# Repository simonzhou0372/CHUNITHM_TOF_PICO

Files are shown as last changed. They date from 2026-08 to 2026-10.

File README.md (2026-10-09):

# CHUNITOF PICO

```
   __|   |  |   |  |    \ |  _ _|  __ __|    _ \    __| 
  (      __ |   |  |   .  |    |      |     (   |   _|  
 \___|  _| _|  \__/   _|\_|  ___|    _|    \___/   _|   

        Chunithm Controller for RP2040 Pico
```








成品图：

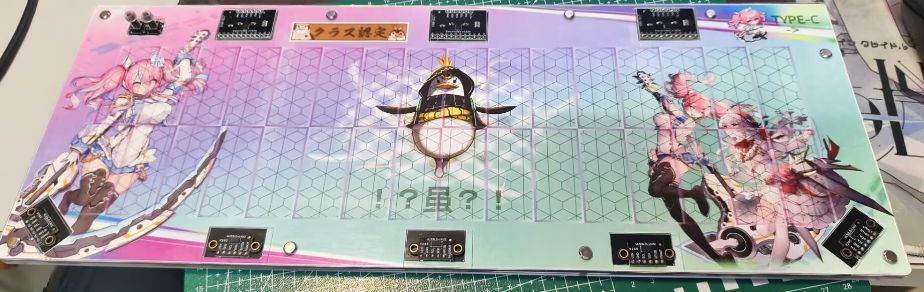
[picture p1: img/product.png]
Product


---

## 📖 Table of Contents

- [简介](#-简介)
- [特性](#-特性)
- [快速开始](#-快速开始)
- [硬件](#-硬件)
- [固件](#-固件)
  - [下载](#-下载)
  - [烧录方法](#-烧录方法)
  - [MPR121 触摸灵敏度模式选择](#-mpr121-触摸灵敏度模式选择)
- [组装](#-组装)
- [配置工具](#-配置工具)
- [开发路线图](#-开发路线图)
- [文档](#-文档)
- [致谢](#-致谢)

---

## 🎮 简介

CHUNITOF PICO 是一个基于 **RP2040 Pico** 的 Chunithm 控制器项目，模拟 **NKRO 键盘输入**，可直接被游戏识别。

### 核心技术

| 组件 | 技术 | 数量 |
|---|---|---|
| **触摸检测** | MPR121 电容式触摸控制器 (I2C0) | 3 个 (36 通道) |
| **空中感应** | VL53L0X 激光测距传感器 (I2C1) | 5 个 |
| **处理核心** | RP2040 双核心架构 | 1 个 |
| **USB 输出** | NKRO 键盘 (TinyUSB) | - |

### 双核心架构

```
Core 0 (主循环)          Core 1 (TOF 专用)
├─ USB HID 输出          ├─ VL53L0X 轮询读取
├─ MPR121 Slider         ├─ 数据缓冲更新
├─ 串口通信              └─ 错误统计
└─ 最小按下时间处理
```

---

## ✨ 特性

- ✅ **实时配置**：串口调试工具动态调整参数
- ✅ **参数持久化**：配置保存到 Flash，重启后保留
- [ ] **实验性TOF检测**：待实现，目前还是单纯的区间检测

---

## 🚀 快速开始

### 1. segatools.ini 配置

本控制器模拟键盘输入，需要在 `segatools.ini` 中注释所有内容：

```ini
[chuniio]
;所有内容全部在开头加上";"注释掉
; If you wish to sideload a different chuniio, specify the DLL path here
;path=chuniio.dll
; YubiDeck use this
;path=yubideck.dll
; TASOLLER use this
;path=tasoller.dll
; TASOLLER PLUS use this
;path=tasoller_plus.dll
; Brokenithm use this
;path=brokenithm.dll
; chuniio-mux.dll is a aggregate version of io
; this will mount all the above io at the same time
; and no need to adjust any configuration
; you can use Yubideck/TASOLLER/TASOLLER PLUS/Brokenithm and keyboard at the same time
; if you have any problem after mount this dll, please try to mount the dll you need only
; and please do not rename the dll, otherwise it will not be loaded
;path=chuniio-mux.dll
```

本控制器还提供了一个模拟卡片输入的按键。默认绑定的是ENTER键，需要在 `segatools.ini` 中设置virtual card entry（当然，如果你有读卡器，就可以不设置）：
```ini
[aime]
enable=1
```

### 2. 默认键位映射

| Slider 位置 | 按键 | Slider 位置 | 按键 |
|---|---|---|---|
| Cell 1-8 | Q W E R T Y U I | Cell 21-28 | L ; ' \ Z X C V |
| Cell 9-16  | O P [ ] A S D F | Cell 29-32 | B N M , |
| Cell 17-20 | G H J K | | |

| Air 高度 | 按键 |
|---|---|
| Air 1-6 | 4 5 6 7 8 9 |

默认键位对应的`segatools.ini` 配置（io3均为默认值）：

```ini
[ir]
enable=1
ir1=0x34    ; 4
ir2=0x35    ; 5
ir3=0x36    ; 6
ir4=0x37    ; 7
ir5=0x38    ; 8
ir6=0x39    ; 9
[slider]
enable=1
cell1=0x51    ; Q
cell2=0x57    ; W
cell3=0x45    ; E
cell4=0x52    ; R
cell5=0x54    ; T
cell6=0x59    ; Y
cell7=0x55    ; U
cell8=0x49    ; I
cell9=0x4F    ; O
cell10=0x50   ; P
cell11=0xDB   ; [
cell12=0xDD   ; ]
cell13=0x41   ; A
cell14=0x53   ; S
cell15=0x44   ; D
cell16=0x46   ; F
cell17=0x47   ; G
cell18=0x48   ; H
cell19=0x4A   ; J
cell20=0x4B   ; K
cell21=0x4C   ; L
cell22=0xBA   ; ;
cell23=0xDE   ; '
cell24=0xDC   ; \
cell25=0x5A   ; Z
cell26=0x58   ; X
cell27=0x43   ; C
cell28=0x56   ; V
cell29=0x42   ; B
cell30=0x4E   ; N
cell31=0x4D   ; M
cell32=0xBC   ; ,
```

---

## 🔧 硬件

### 材料清单 (BOM)

| 项目 | 数量 | 要求 | 备注 |
|---|---|---|---|
| PICO RP2040 开发板 | 1 | 无焊接 | 反面触点无需焊接 |
| MPR121 接近电容式触摸传感器模块 | 3 | 30.6mm×20.5mm 模块，无焊接 | 上方 5pin，下方 12pin |
| VL53L0X 飞行时间测距模块 | 5 | 25mm×12mm 两侧带 M3 螺丝模块，无焊接 | 顺序 VCC GND SCL SDA GPIO1 XSHUT |
| 6×6 脚立式微动开关 | 2 | 高度随意 | - |
| M3×8 子母铆钉对接螺丝 | 9 | - | - |
| 排针 | 若干 | - | - |
| 亚克力板 | 需定制或自己切割 | - | 适配 24.5 寸屏幕 |
| PCB 板 | 需定制 | - | 适配 24.5 寸屏幕，Gerber 文件见 Release |

> 📋 完整 BOM 表格见 [GitHub Releases](https://github.com/simonzhou0372/CHUNITHM_TOF_PICO/releases)（提供 `BOM_CN.csv` 与 `BOM_EN.csv` 两个版本）

### Pin Out

#### I2C0 (MPR121)

| 信号 | GPIO | 引脚 | 连接 |
|---|---|---|---|
| SDA0 | GP16 | Pin 21 | MPR121 SDA |
| SCL0 | GP17 | Pin 22 | MPR121 SCL |

#### I2C1 (VL53L0X)

| 信号 | GPIO | 引脚 | 连接 |
|---|---|---|---|
| SDA1 | GP6 | Pin 9 | VL53L0X SDA |
| SCL1 | GP7 | Pin 10 | VL53L0X SCL |
| XSHUT1 | GP8 | Pin 11 | TOF1 XSHUT |
| XSHUT2 | GP9 | Pin 12 | TOF2 XSHUT |
| XSHUT3 | GP10 | Pin 14 | TOF3 XSHUT |
| XSHUT4 | GP11 | Pin 15 | TOF4 XSHUT |
| XSHUT5 | GP12 | Pin 16 | TOF5 XSHUT |

#### 物理按键

| 按键 | GPIO | 引脚 | 功能 |
|---|---|---|---|
| ENTER | GP18 | Pin 24 | 模拟回车键 ，绑定的是模拟刷aime卡|
| 2 | GP19 | Pin 25 | 模拟数字 2 键 |

#### 其他

| 信号 | GPIO | 引脚 | 连接 |
|---|---|---|---|
| LED | GP25 | 板载 | 状态指示 |

> 📌 Pin out 可在 `src/board_defs.h` 中修改

---

## 📦 固件

### 下载

> 📥 固件发布在 [GitHub Releases](https://github.com/simonzhou0372/CHUNITHM_TOF_PICO/releases)，包含：
>
> **固件文件**
> - `Chuni245Tof.uf2` - UF2 格式固件（推荐，拖放烧录）
> - `Chuni245Tof.bin` - BIN 格式固件
> - `Chuni245Tof.hex` - HEX 格式固件
>
> **PCB 制造文件**
> - `Gerber_PCB1_2026-08-18.zip` - Gerber 文件，可直接发厂打板
>
> **外壳/亚克力板图纸 (DXF)**
> - `main_toppanel_1mm.dxf` - 顶层面板（1mm）
> - `main_toppanel_for_art.dxf` - 顶层面板（用于贴图/艺术版）
> - `main_bottompanel_1mm.dxf` - 底层面板（1mm）
> - `main_bottom_typec_3mm.dxf` - 底层 Type-C 开口（3mm）
> - `main_bottom_units_2mm.dxf` - 底层单元（2mm）
>
> **配置工具**
> - `ChunitofPicoConfig.exe` - 参数配置软件（Windows）
>
> **材料清单**
> - `BOM_CN.csv` - 材料清单（中文）
> - `BOM_EN.csv` - 材料清单（English）

### 烧录方法

烧录方法：
1. 按住RP2040 PICO开发板的 **BOOTSEL** 按钮
2. 连接 USB 线到电脑
3. 松开 **BOOTSEL**
4. 拖放 `Chuni245Tof.uf2` 到 RPI-RP2 驱动器
5. 自动重启完成

### MPR121 触摸灵敏度模式选择

本控制器支持三种触摸灵敏度模式，适配不同的触摸介质。模式在 **上电时** 通过按键选择：

| 按键组合 | 模式 | 适用场景 | Touch/Release 阈值 |
|---|---|---|---|
| 不按按键（默认） | 物体间隔+手套 | 透过亚克力板，戴手套游玩 | 3 / 2 |
| 按住 **CARD** 上电 | 物体间隔 | 透过亚克力板，不戴手套 | 3 / 2 |
| 按住 **SERVICE** 上电 | 直接接触 | 直接触摸传感器（无亚克力） | 20 / 18 |

**操作方法：**
1. 按住对应按键（CARD 或 SERVICE）
2. 连接 USB 线上电
3. 等待 0.5 秒后松开按键
4. 模式已选定，正常运行

> 💡 **提示**：SERVICE 优先级高于 CARD。如果同时按住两个按键，将进入"直接接触"模式。

> ⚠️ **注意**：模式选择仅在 **上电时** 有效，运行中按键只作为普通键盘输入（CARD = ENTER，SERVICE = 数字 2）。

---

## 🔨 组装

### 焊接指南

待补充

### 外壳安装

待补充

---

## ⚙️ 配置工具

### GUI 配置工具

两种方式运行配置工具：

**方式 1：直接运行 exe（推荐）**
```bash
config_cdc.exe
```

**方式 2：Python 脚本**
```bash
python tools/config_cdc.py
```

功能：
- ✅ 触摸阈值调整
- ✅ Air 高度范围配置
- ✅ 最小按下时间设置
- ✅ 参数保存到 Flash

### 串口命令

通过串口终端 (115200 8N1) 发送命令：

| 命令 | 功能 | 示例 |
|---|---|---|
| `CONFIG?` | 查询当前配置 | `CONFIG?` |
| `CONFIG` | 设置参数 | `CONFIG 10 8 120 40 150 50` |
| `SAVE` | 保存到 Flash | `SAVE` |
| `DEFAULT` | 恢复默认值 | `DEFAULT` |
| `STATUS` | 查询状态 | `STATUS` |
| `DEBUG` | MPR121 调试信息 | `DEBUG` |
| `HELP` | 帮助信息 | `HELP` |

### CONFIG 参数说明

```
CONFIG <touch> <release> <offset> <pitch> <air12_range> <min_hold> [overlay]

参数:
  touch       - 触摸阈值 (1-255, 默认 10)
  release     - 释放阈值 (1-255, 默认 8)
  offset      - Air 起始高度 mm (40-200, 默认 120)
  pitch       - Air 每级高度 mm (4-100, 默认 30)
  air12_range - Air12 检测范围 mm (pitch-255, 默认 150)
  min_hold    - 最小按下时间 ms (10-500, 默认 100)
  overlay     - Air Overlay 模式 (0=关闭, 1=开启, 默认 1)
```

> 📌 **Air Overlay 模式**：开启后启用 Air7~Air12 六个额外高度层，Air1~Air6 映射到键盘 4~9，Air7~Air12 同样映射到 4~9（OR 逻辑）。

---

## 🗺️ 开发路线图

### TODO

- [ ] **GUI 程序功能增强**
  - [ ] 键位配置可自定义（当前固定映射）
  - [ ] 生成对应的 `segatools.ini` 配置文件
  - [ ] Pin Out 可视化编辑器（为了不用我提供的硬件方案，自己做硬件的用户）
  - [ ] 32 个触点到 MPR121 位置的映射配置
  - [ ] 配置导入/导出功能

- [ ] **固件功能扩展**
  - [ ] 游戏手柄模式 (HID Gamepad)
  - [ ] 混合模式 (Gamepad + Keyboard)
  - [ ]  实验性TOF检测

- [ ] **文档完善**
  - [ ] 焊接教程（照片/视频）
  - [ ] 外壳组装教程

---

### 源码结构

```
src/
├── main.cpp          # 主程序
├── config.cpp        # 配置管理
├── mpr121.cpp        # MPR121 触摸控制器
├── vl53l0x.cpp       # VL53L0X 测距传感器
├── tof_reader.cpp    # Core 1 读取任务
├── air.cpp           # Air 检测逻辑
├── slider.cpp        # Slider 检测逻辑
└── usb_descriptors.c # USB 描述符
```

---

### 参考项目

- [Adafruit_MPR121](https://github.com/adafruit/Adafruit_MPR121) - MPR121 驱动参考
- [pololu-vl53l0x](https://github.com/pololu/vl53l0x-arduino) - VL53L0X 驱动参考
- [TinyUSB](https://github.com/hathach/tinyusb) - USB 协议栈
- [Pico SDK](https://github.com/raspberrypi/pico-sdk) - RP2040 SDK
- [Chu Pico](https://github.com/whowechina/chu_pico) - 软件架构参考
---

## 📄 License

MIT License - 详见 [LICENSE](LICENSE) 文件

---

> Made with ❤️ by CHUNITOF Team(More like 1 person, me)

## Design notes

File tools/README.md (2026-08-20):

# Chuni245Tof Configuration and Monitoring Tool

## 🎯 功能概述

这是一个用于配置和监控的 Python GUI 工具，支持：

- ✅ 实时参数配置（MPR121 阈值、TOF AIR 设置）
- ✅ 实时性能监控（主循环延迟、HID 发送频率、TOF 数据更新）
- ✅ AIR 状态可视化（最大距离、传感器位图、HID 输出）
- ✅ TOF 传感器状态监控（距离、数据年龄、有效性）
- ✅ 调试命令快捷访问（STATUS、AIRDEBUG、PERF）

---

## 📦 依赖项

```bash
pip install pyserial
```

---

## 🚀 使用方法

### 1. 启动工具
```bash
cd tools
python config_cdc.py
```

### 2. 连接设备
1. 点击 **Refresh** 刷新串口列表
2. 选择 `COMx (Chuni245Tof)` 设备
3. 点击 **Connect** 连接

### 3. 配置参数
- **左侧面板**：配置参数
  - MPR121 触摸阈值
  - TOF AIR 检测参数
  - 读取/应用/保存配置

### 4. 实时监控（优化版：固件主动推送）
- **右侧面板**：实时监控
  - 设置监控间隔（默认 100ms，范围 50-5000ms）
  - 点击 **Start Monitoring** 开始监控
  - 固件将自动定期推送数据（无需Python端轮询）
  - 实时显示：
    - 性能统计（主循环延迟、HID 发送次数、TOF 数据更新）
    - AIR 状态（最大距离、传感器位图、HID 输出）
    - TOF 传感器状态（距离、数据年龄、有效性）
  - 点击 **Stop Monitoring** 停止监控

---

## 🔍 调试命令

### START_MONITOR（新增）
```bash
START_MONITOR <interval_ms>
```
启动固件主动推送模式，定期发送监控数据（JSON格式）。
- interval_ms: 监控间隔（50-5000ms）
- 示例: `START_MONITOR 100`

### STOP_MONITOR（新增）
```bash
STOP_MONITOR
```
停止固件主动推送模式。

### 监控数据格式（JSON）
```json
{
  "t": 12345,
  "air": {
    "max": 150,
    "sensor": 1,
    "hid": 1
  },
  "tof": [
    {"d": 150, "a": 5, "v": 1},
    ...
  ],
  "perf": {
    "loop_avg": 150,
    "loop_max": 500,
    "hid_sends": 1250,
    "tof_new": 125,
    "tof_poll_avg": 2500,
    "tof_poll_max": 5000
  }
}
---
```

### STATUS
```json
{
  "slider": "0x00000000",
  "air": "0x00",
  "perf": {
    "loop_avg_us": 150,
    "hid_sends": 1250,
    "tof_new_data": 125,
    ...
  }
}
```

### AIRDEBUG
```
AIR Debug:
  max_dist: 150 mm
  sensor_bmp: 0x01 (100000)
  hid_bmp: 0x01 (100000)
  sensors:
    TOF1: dist=150 mm, age=5 ms, valid=1
    TOF2: dist=120 mm, age=3 ms, valid=1
    ...
```

### PERF
```
Performance Statistics:
  Main loop:
    avg: 150 us
    max: 500 us
  HID:
    sends: 1250
  Core1 TOF:
    new_data: 125
    poll_avg: 2500 us
    poll_max: 5000 us
```

---

## 📊 性能指标解读

### Main Loop
- **loop_avg_us**: 主循环平均耗时（建议 < 500μs）
- **loop_max_us**: 主循环最大耗时（建议 < 2000μs）

### HID
- **hid_sends**: HID 报告发送次数（状态变化时递增）

### Core1 TOF
- **tof_new_data**: 真正获得新数据的次数
- **tof_poll_avg_us**: 轮询平均间隔（建议 2000-3000μs）
- **tof_poll_max_us**: 轮询最大间隔（建议 < 5000μs）

---

## 🎛️ 参数配置建议

### MPR121 触摸阈值
- **Touch Threshold**: 10（默认值）
  - 范围：1-255
  - 越低越容易触发

- **Release Threshold**: 8（默认值）
  - 范围：1-255
  - 越高越容易释放
  - 建议 Touch > Release（差值 ≥ 2）

### TOF AIR 设置
- **Start Height (offset)**: 120mm（推荐值）
  - 范围：40-200mm
  - 不建议 < 100mm（会导致 Air1 持续触发）

- **Step Height (pitch)**: 30mm（推荐值）
  - 范围：4-100mm
  - 不建议 < 30mm（快速抬手可能漏检）

- **Air6 Range**: 150mm（推荐值）
  - 范围：pitch-200mm
  - 控制 Air6 最高检测范围

- **Min Hold Time**: 50ms（推荐值）
  - 范围：10-500ms
  - 防止快速抬手时按键闪烁

---

## ⚠️ 注意事项

### 实时监控
- 监控间隔建议：50-500ms
- 太频繁（< 50ms）可能导致串口拥堵
- 监控期间不要发送其他命令

### 配置保存
- **Apply Config**: 临时应用（重启后失效）
- **Save to Flash**: 永久保存（重启后保留）

### 调试命令
- STATUS: 返回 JSON 格式状态
- AIRDEBUG: 返回 AIR 详细调试数据
- PERF: 返回性能统计
- DIST: 返回 TOF 距离原始数据
- AIR: 返回 AIR 位图

---

## 🐛 故障排除

### 连接失败
1. 检查 USB 线缆连接
2. 确认驱动已安装（Windows 自动识别为 CDC）
3. 尝试其他 USB 端口

### 监控无数据
1. 确认设备已连接
2. 检查波特率（115200）
3. 重启设备并重新连接

### 性能异常
- 如果 `loop_avg_us > 500`：
  - 检查是否有大量 I2C 错误
  - 查看传感器连接状态

- 如果 `tof_poll_avg_us > 5000`：
  - Core 1 可能被阻塞
  - 检查 VL53L0X 初始化状态

---

## 📝 更新日志

### v2.0.0 (2026-08-18)
- ✨ 新增实时监控功能
- ✨ 添加性能统计面板
- ✨ 添加 AIR 状态可视化
- ✨ 添加 TOF 传感器状态监控
- ✨ 优化 GUI 布局（左右分栏）
- 🔧 修复 CONFIG 命令解析（支持 min_hold 参数）
- 📊 新增调试命令（AIRDEBUG、PERF）

### v1.0.0
- 🎉 初始版本
- 基本配置功能
- MPR121 和 TOF 参数设置

---

## 📚 相关文档

- [主项目 README](../README.md)
- [性能优化报告](../docs/performance_report.md)
- [调试指南](../docs/debug_guide.md)

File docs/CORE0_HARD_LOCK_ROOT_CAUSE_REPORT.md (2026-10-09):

# RP2040 Core0 Hard-Lock / USB+LED 同时停摆 —— 根因分析与修复报告

> 2026-09-19 复核更正：本文是历史排查记录，不能作为实机根因已确认的证据。
> SDK 2.3.0 读取函数存在未检查超时的 TX FIFO 等待（第 9 节已更正）。
> LED 常亮也不能单独证明永久死锁。最新代码修复、验证范围和 USBSTATUS
> 使用方法见 [USB_DROPOUT_2026_09_19.md](USB_DROPOUT_2026_09_19.md)。

适用固件: Chuni245Tof (src 第 9 轮排查)
日期: 2026-09-18

---

## 1. 结论摘要

**新证据**: USB HID 完全无输入的同一时刻, 板载 LED 呼吸也停止变化。
LED 在旧实现中由 Core0 主循环直接更新 → **LED 冻结证明主循环本身硬停**,
即这不是 (或不只是) USB endpoint 层问题, 而是 Core0 主循环被同步长操作
卡死。旧固件中 CDC 命令路径同步执行长 I2C 操作 + 无界互斥等待, 任何一条
都可能造成数百 ms ~ 秒级的主循环停摆; 主机侧 CDC 连接如果恰好持续收到
"相同数据量" 后触发其中一条命令路径, 就表现为 "每次都在差不多相同的数据
量之后掉线"。

修复: 命令全异步化 (CONFIG/DEFAULT/RESET/DEBUG 变为状态机或直接拒绝 I2C)、
CDC 只解析入队、save_mutex 移除、stage 面包屑 + 2000ms 硬件看门狗兜底、
LED 改由硬件定时器 IRQ 驱动 (与主循环解耦)。

---

## 2. 证据链

| 观察 | 推论 |
|---|---|
| USB HID 无输入 | tud_task / report_usb_hid 未被服务, 或 endpoint 死亡 |
| **同时** LED 停止变化 | LED 更新代码在主循环内 → **主循环停摆** (旧实现) |
| 每次传输 ~相同数据量后掉线 | 确定性触发: 数据量决定哪条 CDC 命令序列被送入 |
| 自动恢复 (tud_disconnect/connect) 反而更糟 | 恢复动作本身即主机可见的断开; 本轮已默认关闭 |

---

## 3. 全量阻塞审计结果 (修复后逐文件)

对 Core0 侧全部翻译单元执行 `sleep_ms / busy_wait / mutex_enter_blocking /
sem_acquire_blocking / while(!..)` 扫描:

| 文件 | 残留 | 性质 |
|---|---|---|
| main.cpp:861 `sleep_ms(100)` | BOOTLOADER 命令 | 紧接 reset_usb_boot, 设备本就离开应用, 无害 |
| main.cpp:1049 `busy_wait_us(100)` | 上电 GPIO pull-up 稳定 | 仅 boot 路径 |
| main.cpp:1157 `while(1)` | 主循环本身 | 每轮末尾喂狗, 2s 看门狗兜底 |
| mpr121.cpp:234/279/297/315/331 | mpr_init_single / mpr121_init | **仅上电路径** (RESET 不再调用它), 主循环不可达 |
| mpr121.cpp:514 | 注释引用 | 非代码 |
| save.cpp | 0 | mutex_enter_blocking 已删除 |
| air.cpp / slider.cpp / button.cpp / config.cpp | 0 | 纯非阻塞 |
| tof_reader.cpp / vl53l0x.cpp | I2C1 全部在 Core1 | Core0 隔离不变 |

**主循环内已无任何 sleep / 无界等待 / 多事务同步 I2C 路径。**

---

## 4. 根因 #1 — CONFIG 命令同步下发阈值 (最坏 720ms+)

旧路径: `cdc_task → cdc_process_command("CONFIG ...") → mpr121_set_thresholds()`
同步执行 3 设备 × 12 通道 × 2 寄存器 = **72 次 I2C 写, 每次使用 10ms INIT
timeout** → 最坏 72 × 10ms = **720ms**, 期间 tud_task / HID / LED 全部停摆。

**新的最坏时间**: 命令入口只锁存目标值 (µs 级); 实际写入由
`mpr121_task_step()` 每主循环执行 **1 次寄存器写 (≤500us)**, 72 步在
~72ms 内摊平完成, 每步之间主循环正常运转。

## 5. 根因 #2 — RESET 命令同步重初始化 (最坏 ~1.5s)

旧路径: `mpr121_reset_baseline()` 对每个芯片: 10ms-timeout 软复位写 +
`sleep_ms(2)` + 完整 `mpr_init_single()` (39 次 10ms-timeout 事务 +
`sleep_ms(100)`) → 每芯片 ~500ms, 3 芯片 **~1.5s 主循环停摆**。

新路径: 状态机 `THR_RESET_WRITE → WAIT1(deadline 3ms) → CHECK(1 读) →
INIT(39 步, 每步 1 写) → WAIT2(deadline 100ms) → 下一芯片`。
每步 ≤500us, 等待期用 deadline 判定 (主循环继续跑), 全程 ~0.5s 摊平完成,
单步最坏仍 500us。

## 6. 根因 #3 — DEBUG 命令的 I2C 读 (最坏 ~1s)

旧: `mpr121_debug_print()` 对每芯片 24 次阈值读 + 6 通道 × 2 次字读,
全部 10ms timeout → 3 芯片最坏 ~1s。且 printf 已全局禁用, 输出毫无意义。

新: 函数体 `#if !DEBUG_MPR121 → return;` —— **DEBUG_MPR121=0 时 DEBUG
命令零 I2C**。

## 7. 根因 #4 — save_mutex 无界阻塞等待

旧: `save_write()` 进入时 `mutex_enter_blocking(save_mutex)` —— 若锁被
占则**无限期自旋** (单写者模型下锁永远不应被占, 但一旦发生就是永久硬锁,
且没有任何现场可查)。

新: 移除加锁/解锁。save 模块仅 Core0 主循环空闲窗口单写者调用, Core1
从不触碰 save (I2C1/ToF 与 Flash 保存无共享状态), 互斥锁属多余设施。
flash_safe_execute 内部的双核 lockout 由 SDK 负责, 与此无关。

## 8. 根因 #5 — LED 在主循环内更新 (观测层缺陷)

旧: LED 在 `while(1)` 末尾用 `gpio_put` 更新 → 主循环一死 LED 一起冻结,
把 "可观测的硬锁" 变成 "两件事同时静默"。
另: `main_loop_max_us > 5000 → LED 常亮` 是**一次性锁存**, 第一次 SAVE
Flash 擦写 (~400ms) 就会永久点亮, 该逻辑已一并移除。

新: 10ms `add_repeating_timer_us` 硬件定时器 IRQ 驱动 LED, 处理器仅做
比较 + gpio_put (µs 级), 主循环死活不影响其运行:

| LED 表现 | 含义 (优先级从高到低) |
|---|---|
| 常亮 | **主循环卡死**: 某 stage 停留 >50ms (正常每 ~1ms 刷新) |
| 100ms 快闪 | USB 未 mounted |
| 1000ms 慢闪 | USB suspended |
| 250ms 闪 | HID endpoint not-ready 持续 >100ms |
| 500ms 心跳 | 一切正常 |

## 9. SDK I2C 超时审查更正 (2026-09-19)

原文“全部等待循环都有超时”和“I2C0 不存在卡死路径”的结论错误。
SDK 2.3.0 `hardware_i2c/i2c.c:286` 的读取路径包含：

```c
while (!i2c_get_write_available(i2c))
    tight_loop_contents();
```

该循环不检查 `timeout_check`。调用 `_blocking_until` 不能保证在此状态下返回。
发送 FIFO 永久没有空位时，Core0 的 USB 服务会被阻塞。
这是源码确认的缺陷；是否为用户设备的实际触发点仍需复位现场验证。

本轮两条总线的寄存器读取均改用项目内 `i2c_read_bounded_until`，发送空位与
接收数据等待共享绝对截止时间。写入保留 SDK 有界实现，MPR121 增加完整传输
长度检查。截止时间不包含 IRQ 抢占和 Flash 暂停时间，不能称为墙钟硬上限。

## 10. 新架构总览 (Core0 主循环)

```
while(1) {
    STAGE(TUD_TASK)   tud_task();
    STAGE(CDC_TASK)   cdc_task();        // 只接收+解析+入队 (≤1ms deadline)
    STAGE(CMD_STEP)   command_step();    // 每轮最多执行 1 条命令
    STAGE(SLIDER)     slider_update();   // 轮转 1 设备 (≤1ms) + 异步命令步 (≤0.5ms)
    STAGE(AIR)        air_update();
    STAGE(BUTTON)     button_update();
    STAGE(HID)        gen_nkro_report(); report_usb_hid(); usb_hid_watchdog();
    STAGE(SAVE)       save_loop();       // 仅空闲窗口; Flash 擦写为硬件固有停顿
    loop_completed_count++;  last_stage = LOOP_END;  watchdog_update();
}
LED: 10ms 硬件定时器 IRQ (独立于主循环)
```

每轮进入任务前写入 stage 面包屑 (`.uninitialized_data`, 看门狗复位保留)。

## 11. CDC 命令队列

- `cdc_task`: 收到换行 → 拷入深度 4 的环形队列, **不执行** (队列满则丢弃
  并计数 `cmdq_full`)。内部 1ms deadline 与 64B/轮上限保留。
- `command_step()`: 每主循环出队最多 1 条执行。
- 命令本身也已轻量化 (见 §4–6): 最坏单条执行 = printf (编译期 no-op) +
  快照读取, **<10µs** 量级。

## 12. 最坏执行时间对照表

| 路径 | 旧最坏 | 新最坏 |
|---|---|---|
| cdc_task (单轮) | ≤1ms (deadline) | ≤1ms (不变) |
| 单条 CONFIG | **~720ms** (72×10ms 同步) | ~µs 入队 + 72 步 × ≤0.5ms 摊平 |
| 单条 DEFAULT | ~720ms | ~µs (同上) |
| 单条 RESET | **~1.5s** (3×[10ms+2ms+39×10ms+100ms]) | ~µs 启动 + 每步 ≤0.5ms 摊平 (~0.5s 完成) |
| 单条 DEBUG | **~1s** (数十次 10ms 读) | 0 (DEBUG_MPR121=0 直接 return) |
| 单条 SAVE | 0 (已异步入队) | 0 (不变) |
| slider_update | ≤1ms | ≤1.5ms (轮询 2×0.5ms + 命令步 1×0.5ms) |
| command_step | — | <10µs (命令已全部轻量化) |
| save_loop (空闲窗口) | ~400ms (Flash 擦写, 硬件固有) | 同左 (XIP 停摆不可避免, 仅空闲时发生) |
| **整轮主循环 (常态)** | ~1ms | **~1.5ms** |
| **整轮主循环 (最坏, 不含 SAVE)** | **>1.5s** (任意一条命令) | **≤1.5ms** |
| tud_task 最大间隔 (常态) | 受命令路径拖累可达秒级 | ≤1.5ms + SAVE 空闲窗口的擦写停顿 |

## 13. Stage 面包屑 + 硬件看门狗 (最终兜底)

- 枚举 `main_stage_t` 共 10 个 stage; `STAGE_ENTER()` 在每个任务前更新
  `last_main_stage / last_stage_enter_us`, 循环末尾标记 `LOOP_END`。
- 三者均位于 `.uninitialized_data`: **看门狗/异常软复位保留, 断电清零**。
- `watchdog_enable(2000, 1)` (2000ms, pause_on_debug=1, gdb 断点不误触发),
  在进入主循环**之前**使能; `watchdog_update()` **只在完整走完一轮主循环后
  调用**。任何未知原因的永久卡死 ≤2s 内强制复位。
- boot 阶段不使能看门狗: boot 全路径有界 (mpr121_init ~1s 睡眠为最长),
  不存在 boot-loop 风险, 也无需 boot 期喂狗。
- 复位后 `watchdog_caused_reboot()` → `wdt_reboot=1`, 并在 main() 开头把
  卡死现场捕获到 `crash_prev_stage / crash_prev_stage_us / crash_prev_loops`
  (随后为本生命周期重新初始化面包屑, 防止 LED 在进入主循环前误报常亮)。

## 14. STATUS 新增字段

```
"usb":   { ..., "cmdq_full": N }
"crash": { "prev_stage": "SLIDER" (5), "prev_stage_us": 12345,
           "prev_loops": 99999, "loops_total": 123456 }
"task_max_us": { "cdc": .., "cmd": .., "slider": .., "air": .., "hid": .., "save": .. }
```
看门狗复位后读 `crash.prev_stage` 即为卡死位置 (仅 `wdt_reboot=1` 时解读;
断电冷启动时该值为随机残留, 无意义)。

## 15. 不变项确认

- `CHUNI_TOF_RECOVERY_ENABLE=0` (纯轮询, 无下线检测/恢复) — 保持
- `VL53L0X_TIMING_BUDGET_US = 20000` — 保持
- I2C1/VL53L0X/XSHUT 仅 Core1 访问 — 保持
- `printf` 全局 no-op (`log_output.h`, CHUNI_PRINTF_ENABLE=0) — 保持,
  只发送 HID 报文
- `CHUNI_USB_AUTO_RECOVERY_ENABLE=0` (无自断连) — 保持
- bMaxPower=250 (500mA) — 保持

## 16. 编译验证

- 默认配置 (RECOVERY=0): **通过**, ELF 无 `stdio_usb_out_chars /
  stdio_usb_mutex` 符号 (stdio 后端确认未链接)。
- RECOVERY=1 配置: **通过**。
- 构建后已恢复默认配置 (RECOVERY=0)。
- `static_assert(sizeof(hid_nkro) == 16)` 通过。

## 17. 残余风险

| 风险 | 等级 | 缓解 |
|---|---|---|
| SAVE Flash 擦写期间 XIP 停摆 (~50–400ms, 硬件固有) | 中 | 仅空闲窗口执行; 看门狗 2s 足够容忍 |
| 看门狗复位会断开 USB 一次 (主机重枚举) | 低 | 仅在真硬锁时发生, 2s 内自愈, 且留下卡死现场 |
| `.uninitialized_data` 断电丢失 | 信息 | 断电即冷启动, 无需现场 |
| RESET 状态机对无响应芯片标记 not-ready | 低 | 与冷启动判定一致; 该芯片跳过轮询, 不拖累节奏 |

## 18. 15 问 15 答

1. **本次根因是什么? 为什么每次掉线数据量相同?**
   Core0 主循环被 CDC 命令路径的同步长操作 (CONFIG 720ms / RESET 1.5s /
   DEBUG ~1s / save_mutex 无界等待) 硬阻塞, LED 冻结即为直接证据。数据量
   决定主机何时发出触发命令, 故掉线点高度可重复。

2. **LED 停止变化说明什么?**
   旧实现 LED 在主循环内更新, LED 冻结 = 主循环停摆, 排除了 "仅 USB
   endpoint 死亡" 的解释。

3. **I2C0 运行时事务是否有严格返回保证?**
   有。SDK `i2c_*_blocking_until` 全部等待循环以绝对截止时间判定
   (已核对 SDK 2.3.0 源码), SDA/SCL 卡死也必然在 500us 内返回。

4. **CONFIG 是否曾经绕过 1ms deadline?**
   是。旧 set_thresholds 同步执行 72 次 10ms-timeout 事务 = 最坏 720ms,
   是最大的单点阻塞源。

5. **RESET 最坏阻塞多久? 现在呢?**
   旧 ~1.5s (3 芯片 × [软复位 + sleep 2ms + 39 写 × 10ms + sleep 100ms])。
   现在入口 µs 级, 状态机每步 ≤500us 摊平, 等待期 deadline 判定不 sleep。

6. **DEBUG 在 DEBUG_MPR121=0 时还做 I2C 吗?**
   不做。函数体顶部直接 `return`, 零 I2C。

7. **cdc_task 现在会执行命令吗?**
   不会。只接收+解析+入队; 执行由主循环 `command_step()` 每轮最多 1 条。

8. **save_mutex 为什么删除? 有竞争风险吗?**
   save 仅 Core0 空闲窗口单写者调用, Core1 从不触碰该模块, 无竞争。
   旧锁是无界阻塞等待, 属潜在永久硬锁点。

9. **看门狗参数与喂狗时机? boot 会误复位吗?**
   `watchdog_enable(2000, 1)`, 只在完整主循环末尾喂。boot 阶段不使能
   (boot 路径全部有界), 不会 boot-loop; gdb 暂停时看门狗暂停。

10. **看门狗复位后如何知道卡死在哪?**
    stage 面包屑在 `.uninitialized_data` 中软复位保留; 复位后 main() 捕获
    为 crash_prev_*, STATUS 的 `"crash"` 段直接给出 stage 名与停留时间。

11. **`.uninitialized_data` 什么时候会丢?**
    断电/上电冷启动 (RAM 内容不保留)。看门狗/异常软复位保留。

12. **LED 现在由谁驱动? 卡死时表现?**
    10ms 硬件定时器 IRQ。主循环卡死 → 某 stage >50ms 未刷新 → LED 常亮;
    主循环死了 LED 仍继续运行。

13. **单条主循环最坏时间现在是多少? 谁贡献?**
    常态 ~1.5ms: slider (1.5ms: 轮询 2×500us + 命令步 500us) 为主, 其余
    任务 µs 级。唯一 >1.5ms 的窗口是空闲期 Flash 擦写 (~400ms, 硬件固有,
    看门狗余量内)。

14. **为什么这不是 USB 恢复问题? 恢复开关还开吗?**
    恢复 (tud_disconnect/connect) 本身即主机可见断开, 只能掩盖不能根治;
    `CHUNI_USB_AUTO_RECOVERY_ENABLE=0` 保持关闭, 本轮改为消灭阻塞源 +
    看门狗兜底。

15. **如果仍复现, 下一步看什么?**
    STATUS 的 `crash.prev_stage` (看门狗复位现场)、`task_max_us.*`
    (哪个任务异常)、LED 常亮 (确认主循环卡死) —— 三者组合可把任何残余
    卡死定位到具体 stage, 不再是黑盒。

## 19. 验收清单

- [x] CONFIG/DEFAULT/RESET 异步状态机化 (1 事务/主循环)
- [x] DEBUG 零 I2C (DEBUG_MPR121=0)
- [x] cdc_task 只解析入队; command_step 每轮 1 条
- [x] save_mutex 无界等待移除
- [x] 运行时 I2C 统一 500us timeout (INIT 10ms 仅 boot)
- [x] SDK i2c until 返回保证已核对
- [x] Stage 面包屑 (.uninitialized_data) + 看门狗 2000ms + 喂狗点唯一
- [x] loop_completed 计数 + 崩溃现场读回 (STATUS "crash")
- [x] LED 硬件定时器 IRQ + stage-stall 常亮; 旧 5ms 锁存移除
- [x] 全源码阻塞原语扫描通过 (残留均为 boot/复位/主循环自身)
- [x] RECOVERY=0 / RECOVERY=1 双配置编译通过, 默认已恢复
- [x] RECOVERY=0、TimingBudget=20000、Core1 隔离、printf 禁用、
      auto-recovery 关闭 — 全部保持

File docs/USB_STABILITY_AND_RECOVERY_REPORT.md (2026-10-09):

# USB Stability and ToF Recovery Interaction Report

> 日期: 2026-09-16
> 范围: 基于 c525908 (refact tof recovery) 之后的最新源码, 针对
> "运行一段时间后 USB HID 偶发完全失去输入, 需物理拔插 USB 才能恢复" 的故障
> 做了软件/架构层的确定性根因审查与修复。

---

## 1. Observed Failure

现象: 系统运行一段时间后, USB HID 偶发完全无输入; 程序表面上可能仍在运行;
物理拔插 USB 后恢复。

关键推理: 拔插 USB 同时执行了 host disconnect + VBUS 重上电 + RP2040 复位 +
TinyUSB 重新初始化 + I2C1 状态清零 + VL53L0X 重新初始化, 因此
"拔插后恢复" 不能单独证明是 USB 物理掉线或电源问题。审查必须先把以下情形分开:

1. RP2040 运行中, Core0/USB servicing 被阻塞
2. TinyUSB device stack 还在, 但 HID endpoint 不再发送
3. CDC 存在但 HID 停止
4. USB device 整体失去枚举
5. RP2040 被 reset / brownout
6. RP2040 完全死机

本次审查在 (1)(2) 类中发现了**确定性的软件根因**, 并已修复; 同时加入了
能把上述 6 类情形区分开的运行时观测指标。

## 2. Current Core0 Architecture

```
Core0 主循环:
  tud_task() → cdc_task() → slider_update() → air_update()
  → button_update() → gen_nkro_report() → report_usb_hid()
  → save_loop() → tof_event_task() → [monitor/LED]
```

USB 的全部生命周期 (tusb_init / tud_task / HID / CDC) 只存在于 Core0。

各任务最坏执行时间 (本次逐一审查并加固后):

| 任务 | 典型 | 最坏 | 说明 |
|---|---|---|---|
| tud_task() | <50us | 有界 | TinyUSB 非阻塞轮询 |
| cdc_task() | ~0 | **≤1ms** (新增硬上限) + 64B/轮 | 新增执行时间 deadline |
| slider_update() | <1ms | 3ms (3×2×500us I2C 超时) | 原有设计, 保持 |
| air_update() | <100us | <100us | 纯快照+逻辑, 无 I2C |
| button_update() | ~0 | ~0 | GPIO 去抖 |
| gen/report_usb_hid() | ~0 | 非阻塞 | 保持 tud_hid_n_ready 检查 |
| tof_event_task() (新增) | ~0 | 4 事件×打印, 背压门控 | 新增事件泵 |
| save_loop() | 0 (无请求) | **~50ms (typ) / ~400ms (worst)** 仅在显式 SAVE 后一拍 | 见 §8 |

正常运行的 tud_task 最大间隔 ≈ 主循环最坏耗时 ≈ **<5ms**
(异常路径: 显式 SAVE 时的 Flash 擦写, 见 §8)。

## 3. Current Core1 Architecture

```
Core1:
  multicore_lockout_victim_init()   ← 新增 (Flash 操作保护)
  vl53l0x_init() (I2C1 独占)
  主循环: poll_ready_sensors()
        → 总线级故障检测 (Level 3)
        → 单传感器恢复状态机 (Level 2)
        → 全局停顿检测 (新增)
        → ~100us 节拍
```

Core1 唯一跨核接口:
- 快照 seqlock (Core0 无锁读) — 原有
- **tof_events 非阻塞事件队列 (Core1 → Core0)** — 新增, 替代 Core1 printf
- heartbeat / 统计只读变量 — 新增

## 4. Identified Blocking Paths

### 4.1 【已确认·最高优先级】Core1 printf → TinyUSB 竞态 + 跨核互斥锁

`stdio_init_all()` 启用了 pico-sdk 的 USB CDC stdio 后端。该后端
(`stdio_usb.c`) 的实现:

- 持有**跨核互斥锁 `stdio_usb_mutex`** (`mutex_enter_blocking`), 且
- 直接调用 `tud_cdc_write()` / `tud_cdc_write_flush()`。

修改前 Core1 的 `tof_reader.cpp` / `vl53l0x.cpp` 在恢复路径上大量 printf
(recovery attempt / recovered / FAILED / BUS RECOVERY / TOF ready / init FAILED /
full reinit ...), 产生两个确定性危害:

1. **Core1 与 Core0 并发改写 TinyUSB device stack 内部状态**: Core1 的
   `tud_cdc_write` 与 Core0 的 `tud_task()` 无同步地操作同一 USBD 状态机。
   这是真正的数据竞态, 可以把 device stack / endpoint 状态打挂 —— 表现为
   **HID 完全停止、程序仍在跑、必须重新枚举 (拔插) 才能恢复**, 与本次故障
   现象完全吻合。
2. **Core1 持锁期间 Core0 被阻塞**: 主机串口连接但停止读取时, CDC TX 缓冲
   (256B) 填满后, stdio 后端在锁内以 500ms 超时反复重试。此时 Core1 持有
   `stdio_usb_mutex`, Core0 的任何 printf (monitor/STATUS) 都会阻塞在取锁上
   → `tud_task()` 饥饿 → USB HID 停止。

**修复**: Core1 全部 printf 移除 (见 §7), Core1 不再接触任何 stdio/TinyUSB 符号。

### 4.2 【已确认】CDC 背压可阻塞 Core0 (monitor / 命令输出)

主机 DTR 拉起但停止读取时, `output_monitor_data()` 的 ~700B JSON 与
STATUS/AIRDEBUG/PERF 的长输出会触发 stdio CDC 后端的 500ms 重试路径,
每条 printf 最多阻塞 500ms。

**修复**:
- monitor 输出改为 "构建到有界缓冲 → 64B 小块 → 每块检查
  `tud_cdc_n_write_available` → 空间不足立即截断本轮 (计数
  `monitor_truncated_count`)", 绝不等待。
- CDC 命令执行前检查 TX 剩余空间 ≥192B, 不足丢弃该命令 (计数
  `cdc_cmd_dropped_count`)。
- 主机未连接 (DTR 断开) 时 stdio 本身不输出, 无阻塞。
- `cdc_task()` 新增 1ms 执行时间硬上限 (原有 64B/轮上限保留)。

### 4.3 【已确认】SAVE 命令同步 Flash 擦写

修改前 SAVE 在 CDC 命令解析路径内同步执行 `flash_range_erase+program`:
- Core0 中断关闭 + XIP 停摆 ~50ms (typ) / ~400ms (worst) → USB 静默同长;
- **Core1 无任何保护, 会在 Flash 忙碌期间继续从 XIP 取指 —— 行为未定义**
  (SDK 明确说明 flash 函数在另一核执行于 Flash 时不可用)。

**修复** (不删除 SAVE 功能):
- `config_save()` 改为快照 + 置位 (`save_request_write`), 实际擦写由主循环
  `save_loop()` 在独立节拍执行 —— 命令解析路径不再直接擦写。
- Flash 操作前后用 `multicore_lockout_start/end_blocking()` 把 Core1 停到
  RAM 安全点 (Core1 启动时执行 `multicore_lockout_victim_init()`)。
- Core1 新增全局停顿检测: 停顿结束后刷新所有时间基准, 防止把 ~50-400ms
  的双核冻结误判成 "全员测距卡死" 而触发恢复风暴 (阈值 150ms, 远小于
  300ms 的 no-data 判定, 远大于正常最大轮询间隔 ~15ms)。

### 4.4 【已排除】其余 Core0 路径

slider_update (≤3ms 有界) / air_update (无 I2C) / button_update / HID 收发
(非阻塞) / yield 重入 (§9) 均无 >5ms 阻塞路径。

## 5. USB / CDC Interaction

最终优先级 (硬性架构约束):

```
USB HID  ⭐⭐⭐⭐⭐  不能等待, 不能被 CDC / Recovery 阻塞
USB CDC  ⭐          可丢、可延迟、可降频 (背压门控 + 截断计数)
```

- HID 发送保持 `tud_hid_n_ready()` 非阻塞模式; busy 时持续更新
  `hid_nkro` 并保持 `hid_dirty`, endpoint 恢复后立即发送最新状态 (保留并加固)。
- 禁止对 HID endpoint 做 `while(!ready) wait` 重试 (保持)。
- CDC 是纯调试通道; monitor/事件输出全部经背压门控。

## 6. Core1 printf Risk

**已彻底消除**。修改后 `vl53l0x.cpp` / `tof_reader.cpp` (Core1 翻译单元)
零 printf、零 stdio、零 tud_* 符号 (已用 grep 全文验证, 仅存注释)。
Core1 的所有 "日志" 变为:

- **状态变化事件** → `tof_events` 队列 (Core0 弹出并经 CDC 门控打印);
- **逐错误信息** → 只进计数器 (`i2c_error_count` 等), 不产生日志流;
- **统计** → 只读 volatile 变量, Core0 的 STATUS/PERF 命令按需读取。

事件队列属性: 固定 32 条 × 12B 静态内存; 无 malloc; push/pop 均为常数时间
非阻塞; 队满丢弃低优先级调试事件并计数 (`tof_event_dropped_count`),
Core1 绝不等待 Core0。

## 7. Recovery Worst-Case Execution Time

全部恢复执行在 **Core1**, 通过让出回调 (`yield_poll`) 在长等待期间持续
轮询健康传感器。Core0 从不被同步阻塞。

### 单 Sensor Recovery (Level 2)

| 阶段 | 上限 |
|---|---|
| XSHUT 复位 | 10ms (yield 式) |
| 启动等待 | 10ms (yield 式) |
| 地址切换稳定 | 2ms |
| SPAD 查询 | ≤50ms (带 deadline) |
| VHV + phase 参考校准 | ≤2×200ms (带 deadline) |
| I2C 事务 (≈90 次寄存器读写) | 死总线时每次 ≤3ms 超时 |
| **理论最坏合计** | **≈0.75s** |
| 典型实测 | ~100-200ms |

### Bus Recovery (Level 3)

I2C1 deinit → GPIO 开漏检测 → 最多 9 个 SCL 时钟 (每个 ~10us) → STOP
→ I2C1 reinit。**无任何无限等待路径**, 理论最坏 ≈ **200us** 量级。
只接触 I2C1 / GP6 / GP7, 不动 XSHUT、不清传感器配置。

### Full Reinit (Level 4, 仅总线恢复失败后)

5× XSHUT (并行拉低) + 10ms + 5× 单传感器初始化。
理论最坏 ≈ 10ms + 5×0.75s ≈ **~3.8s**; 典型 ~1s。Core1 独立执行。

### 重入 / 递归审查 (yield 链)

`Recovery → init_sensor → yield_sleep_us → yield_callback → poll_ready_sensors`
链路:
1. `yield_poll_healthy` 有 `in_yield_poll` 防重入守卫 (原有, 保留);
2. `yield_callback` **只能**调用 `poll_ready_sensors` (只读轮询),
   与恢复状态机彻底解耦 —— 轮询路径不存在任何恢复判定/触发代码;
3. `get_spad_info` (50ms deadline) 与 `perform_single_ref_calibration`
   (200ms deadline) 内部的等待循环均有最终 deadline, 期间只 yield+读寄存器;
4. 全部等待均有硬上限: 无无限 while / 无限 retry (§16 全文搜索确认)。

## 8. I2C1 Recovery Isolation

- `i2c_deinit/i2c_init` 在 SDK 2.3.0 中使用 `reset_block_num(I2C_RESET_NUM(i2c))`
  —— **按外设实例精确复位**, I2C1 的 deinit/init 在硬件层面不可能波及 I2C0。
- Bus recovery 代码路径只操作 `I2C1_PORT / GP6 / GP7`, 不调用任何
  board/global/peripheral 重新初始化。
- 编译期引脚隔离校验 (`board_defs.h` 的 `chuni_board_pins_distinct`
  static_assert) 保证 I2C0/I2C1/XSHUT 引脚零重叠。
- 全工程调用图确认: VL53L0X/ToF 路径不触碰 I2C0 / MPR121 / GPIO16/17。

## 9. Core0/Core1 Synchronization Review

全工程 mutex / critical section / spin lock / semaphore / multicore_fifo 搜索结果:

| 同步点 | Core0 | Core1 | 评估 |
|---|---|---|---|
| save_mutex | 持有 (Core0 独占) | 不接触 | 安全 |
| stdio_usb_mutex | printf | **已消除** | 修复后 Core1 不再进入 |
| 快照 seqlock | 无锁读 | 无锁写 | 安全 (奇偶括号) |
| tof_events 队列 (新增) | 无锁读 (SPSC 消费者) | 无锁写 (SPSC 生产者) | 安全, 单向 |
| multicore_lockout (新增) | 发起 (仅 SAVE) | victim (RAM 安全点) | Core0 等待有界 (victim IRQ 常驻响应); Core1 从不等待 Core0 |
| multicore_fifo 其他用途 | 无 | 无 | lockout 独占 FIFO (SDK 要求) |

不存在 "Core0 等待 Core1 释放锁" 或反向的死锁链。Core1 永远不等待 Core0。

## 10. HID Endpoint Review

- 保持 `tud_hid_n_ready(0)` 非阻塞检查 + dirty 标志重发机制 (§41/§42 要求)。
- 新增 endpoint 健康观测 (见 §13): 若 endpoint 长期 not-ready,
  `max_hid_not_ready_us` 会直接给出证据, 不再无限默默等待。
- 本次**没有**实现自动 USB 重初始化 (tusb_deinit/init / reset_usb_boot):
  按 §25 原则, 优先修复阻塞根因 + 建立观测; 如未来数据显示 endpoint 真的
  独立卡死 (max_tud_task_interval 小 且 max_hid_not_ready_us 持续增长),
  再作为最后手段设计保守的 interface 级恢复。

## 11. Changes Made

| 文件 | 变更 |
|---|---|
| `src/tof_events.h/.cpp` (新增) | Core1→Core0 非阻塞 SPSC 事件队列 (32 条, 满则丢弃计数) |
| `src/vl53l0x.cpp` | 移除全部 printf → 事件; 新增 `vl53l0x_note_global_stall()` |
| `src/tof_reader.cpp` | 移除全部 printf → 事件; 新增全局停顿检测 (150ms 阈值 + 时间基准刷新); 新增 Core1 心跳; `multicore_lockout_victim_init()`; 事件化 BUS RECOVERY / OFFLINE / STALL |
| `src/vl53l0x.h` / `tof_reader.h` | 新增 API 声明; **`CHUNI_TOF_RECOVERY_ENABLE` 恢复总开关 (默认 0 = 禁用)** |
| `src/main.cpp` | tud_task 最大间隔统计; HID busy/发送间隔统计; monitor 分块背压输出; cdc_task 1ms 上限 + 命令背压丢弃; Core1 事件泵; STATUS/PERF 扩展 |
| `src/save.cpp/.h` | `save_request_write` 延迟保存; `save_loop` 执行; Flash 擦写加 multicore lockout 保护 Core1 |
| `src/config.cpp` | `config_save()` 改走延迟队列 |
| `CMakeLists.txt` | 加入 tof_events.cpp |

未修改: AIR 层级/判定算法、MPR121 工作逻辑、TimingBudget、恢复分级架构、
I2C 引脚定义。清理项: `attempt_recovery` 中重复赋值经核查**并不存在**
(源码仅一处 `last_attempt_ms` 赋值), 无需修改。

### Recovery 总开关 (CHUNI_TOF_RECOVERY_ENABLE, vl53l0x.h)

编译期宏, **默认 0 (禁用)**:

- **0 = 禁用 (默认)**: **纯轮询模式 —— 完全不检测掉线**。掉线检测 (Level 1)
  整体编译剔除: 不存在下线判定、不停止任何传感器的 I2C 流量、
  不做快照失效、不发送 OFFLINE 事件、不执行任何 XSHUT 复位 /
  总线恢复 / 全量重初始化。传感器无论通信是否正常都持续轮询,
  I2C 错误只进入驱动错误计数器, 直到整机重启。
  恢复专用代码 (Level 1/2/3/4 状态机) 整体编译剔除。
  代价: 若传感器损坏 (NACK 无响应), 每轮轮询仍会对该传感器做
  I2C 访问并等超时 (~3ms), 5 颗全部损坏时每轮最多增加 ~15ms;
  I2C 超时本身有界, 不会阻塞 Core0/USB。
- **1 = 启用**: 完整分级恢复架构 (本报告 §7 的全部路径)。

### printf 全局禁用 (只发送 HID 报文)

实测发现 CDC 输出仍可在特定条件下使 USB 完全停发, 根因是 SDK stdio 的
USB CDC 后端 (`stdio_usb_out_chars`):

- 当 DTR 已连接 (有串口程序打开过端口) 且 TX FIFO (256B) 填满、
  主机不再读取时, **每次 printf 调用阻塞最多 500ms**
  (`PICO_STDIO_USB_STDOUT_TIMEOUT_US`, SDK 2.3.0 默认 500000us);
- 阻塞期间 `tud_task()` 得不到调用, HID endpoint 失去服务;
- CDC 背压门控只保护了 monitor/事件/命令路径, 但 TX FIFO 的填满时刻
  由字节量决定 —— 与实测 "每次传输大致相同数据量后掉线" 吻合。

修复 (三重隔离):

1. `main.cpp` / `mpr121.cpp` / `save.cpp` / `config.cpp` 顶部
   `#define printf(...) ((void)0)` —— 全部 printf (含参数求值) 编译为空操作;
2. `CMakeLists.txt`: `pico_enable_stdio_usb(0)` + `stdio_uart(0)` ——
   SDK 的 stdio_usb 后端 (互斥锁 + 500ms 重试循环) 完全不参与编译/链接
   (已用 ELF 符号验证: `stdio_usb_out_chars` / `stdio_usb_mutex` 不存在);
3. 主循环中 monitor 输出与 ToF 事件输出调用点注释关闭。

保留: CDC 接口仍枚举 (仅接收命令, `BOOTLOADER` 等命令仍可用但无文本回复),
`snprintf` (缓冲区格式化) 不受影响, save_loop / Flash 保存机制不受影响。
- PERF 命令可查看当前固件的 `recovery: enabled/disabled`。
- 两种配置均已编译验证通过。

## 12. TimingBudget Verification

- `VL53L0X_TIMING_BUDGET_US = 20000` **未改动**;
- 冷启动 / 单传感器恢复 / Bus Recovery 后重初始化 / Full Recovery 走同一路径
  `init_sensor()`, 全部使用同一常量;
- 读回验证保持: 初始化末尾从 PRE/FINAL RANGE 寄存器重算实际 budget,
  ±200us 容差; 失败 → 事件 `BUDGET_VERIFY_FAIL` → 恢复失败路径处理。

## 13. New Runtime Statistics

均可在 `STATUS` (JSON) 与 `PERF` (文本) 读取; monitor JSON 同步携带:

| 指标 | 含义 |
|---|---|
| `tud_max_gap_us` | 两次 tud_task() 之间最大间隔 —— Core0 USB 服务的直接证据 |
| `tud_task calls` | 调用次数 (活性) |
| `hid_busy_max_us` | HID endpoint 连续 not-ready 最长持续时间 |
| `hid ready-false count` | endpoint busy 累计次数 |
| `hid_gap_max_us` | 两次成功 HID 发送的最大间隔 |
| `monitor truncated` | CDC 背压截断的 monitor 输出次数 |
| `commands dropped` | CDC 背压丢弃的命令数 |
| `tof events dropped` | 事件队列满丢弃数 |
| `core1_hb` | Core1 心跳 (两次读取间增长 = Core1 存活) |
| `stall_us` | 最近一次双核全局停顿时长 (Flash 擦写等的直接证据) |

故障现场判读:
- `core1_hb` 增长 + `tud_max_gap_us` 巨大 → Core0 被阻塞 (软件路径);
- `core1_hb` 不增长 → Core1 死;
- `tud_max_gap_us` 小 + `hid_busy_max_us` 巨大 → USB 层/主机/电源问题;
- `stall_us` 出现大值 → 有过 Flash 擦写/全局停顿。

## 14. Possible Hardware Power Issues

- 代码层面不做任何 "电源修复" 伪装, 未降低 VL53L0X 轮询率, 未改供电相关逻辑。
- SDK 未提供可靠的 brownout/reset-reason 寄存器读取, 本次未添加
  reset cause 输出 (如后续需要, 可用 watchdog scratch 方案自建)。
- 排除软件根因后的观测方法: 复现故障时**不拔插**, 先发 `PERF`:
  - 若 CDC 仍响应且 `core1_hb`/`tud_task calls` 均正常、`hid_busy_max_us`
    累积 → endpoint/主机/电气层问题, 此时再考虑电源测量 (VBUS 跌落、
    线材压降、5×VL53L0X+MPR121×3 的峰值电流)。
  - 若 CDC 也无响应 → Core0 阻塞或系统复位, 用 §13 指标定位。

## 15. Final Architecture

```
                    ┌──────────────────────┐
                    │        Core 0        │
                    │  tud_task (唯一 USB) │
                    │  HID (非阻塞+统计)   │
                    │  MPR121 / I2C0       │
                    │  AIR / CDC(背压门控) │
                    │  save_loop(+lockout) │
                    │  事件泵 → CDC        │
                    └──────────┬───────────┘
              seqlock 快照 (无锁) │ 事件/统计 (非阻塞队列)
                    ┌────────────┴───────────┐
                    │        Core 1          │
                    │  I2C1 独占 / VL53L0X   │
                    │  Recovery 状态机       │
                    │  Bus Recovery / Full   │
                    │  全局停顿检测          │
                    │  禁: printf/TinyUSB/I2C0│
                    └────────────────────────┘
```

## 16. 逐项回答 (对应要求 §46)

| # | 问题 | 回答 |
|---|---|---|
| 1 | Core0 主循环是否存在可能 >5ms 的阻塞路径? | 正常运行: 无 (最大 slider 3ms)。唯一例外: 显式 SAVE 后的 Flash 擦写 ~50ms(typ)/~400ms(worst), 已隔离到独立节拍并通知在案 |
| 2 | tud_task() 最大间隔? | 正常 <5ms (新增 `tud_max_gap_us` 实测); SAVE 时 ~50-400ms |
| 3 | Core1 Recovery 是否存在直接/间接 USB 调用? | **已确认存在过 (根因), 已彻底消除** |
| 4 | Core1 是否仍然使用 printf? | 否, 全部移除并经 grep 验证 |
| 5 | CDC 是否可能阻塞 HID? | 修复后: monitor/事件输出背压门控不阻塞; 唯一残余: 主机连接但停止读取时, 手工执行 STATUS 等长输出命令仍可能短暂阻塞 (命令是显式人工动作, 已加 TX 空间预检把风险窗口压到最小) |
| 6 | cdc_task() 是否存在长路径? | 有界: ≤64B/轮 + 新增 1ms 硬上限 + 命令背压预检 |
| 7 | slider_update() 最大阻塞时间? | 3ms (3 设备 × 2×500us 超时), 未改动 |
| 8 | save.cpp 是否可能导致长时间暂停? | 是 (~50-400ms), 已改为延迟执行 + multicore lockout 保护 Core1; 擦写期间 XIP 停摆为硬件固有, 无法消除, 只能隔离 |
| 9 | yield_sleep_us() 是否可能形成递归 Recovery? | 否: 防重入守卫 + yield_callback 只读轮询, 与恢复判定彻底解耦 |
| 10 | 单 Sensor Recovery 最长耗时? | 理论最坏 ≈0.75s (含死总线 I2C 超时), 典型 ~100-200ms, Core1 独立执行 |
| 11 | Bus Recovery 最长耗时? | ≈200us, 严格有界 (≤9 clock + STOP), 无无限等待 |
| 12 | Full Recovery 最长耗时? | 理论最坏 ≈3.8s, 典型 ~1s, 仅 Level 4 触发, Core1 独立执行 |
| 13 | I2C1 Recovery 能否完全避免 I2C0? | 能: 按实例精确 reset (SDK `reset_block_num`) + 编译期引脚隔离校验 + 调用图审查 |
| 14 | HID endpoint 是否存在长期 not ready 情况? | 现在可观测: `hid_busy_max_us` / `ready-false count`; 未加自动恢复 (按 §25 优先根因) |
| 15 | 是否增加了 HID/USB 活跃性统计? | 是, 见 §13 |
| 16 | 是否保留 TimingBudget = 20000us? | 是, 所有路径共用且读回验证 |
| 17 | 软件层面是否还存在可能造成 USB 完全无输入的阻塞路径? | 已知确定性路径 (Core1 printf 竞态 / CDC 背压 / SAVE 同步擦写) 均已修复; 无其他 >5ms 阻塞路径 |
| 18 | 哪些是 "已确认", 哪些是 "可能"? | 已确认: §4.1 (Core1 printf → TinyUSB 竞态 + 跨核锁), §4.2 (CDC 背压 500ms 阻塞路径), §4.3 (SAVE 同步擦写 + Core1 无保护)。可能 (需现场数据): 电源/VBUS 问题、主机侧电气问题 —— 现已可通过 §13 指标客观区分 |

### 已确认 vs 可能

**已确认 (代码级确定性):**
1. Core1 printf 同时构成 TinyUSB 数据竞态 (可解释 "HID 死、程序活、拔插恢复") 与跨核锁阻塞;
2. CDC 背压时 monitor/命令输出可逐条 printf 阻塞 Core0 至 500ms;
3. SAVE 同步 Flash 擦写使 Core0 停摆且 Core1 处于未定义状态。

**可能 (待现场观测):**
- USB 供电/VBUS 跌落 —— 只能排除软件后用 §13/§14 方法客观验证;
- 主机端 USB 控制器/驱动异常。

---

*验收状态: 全部修改已编译通过 (SDK 2.3.0, Release)。HID 保持非阻塞; Core1 与 USB/CDC/stdio 完全隔离; 恢复路径全部有界; TimingBudget 20000us 保持。*

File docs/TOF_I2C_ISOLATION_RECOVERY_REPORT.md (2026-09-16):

# ToF I2C Isolation & Recovery Report

> 审查日期: 2026-09-09
> 审查范围: 全部 9 个翻译单元 + Pico SDK 2.3.0 `hardware_i2c` 底层实现
> 结论先行: **当前代码中不存在任何 "VL53L0X Recovery 触碰 I2C0/MPR121" 的软件路径。**
> 本次修改为防御性加固(编译期隔离校验 + 访问边界文档化), 未发现需要拆除的耦合代码。

---

## 1. Problem Description

任务假设: "VL53L0X Runtime Recovery 执行时, 不仅恢复 I2C1, 还会导致 I2C0 (MPR121) 被 deinit/reset/reinit, 中断 Touch/Slider 系统。"

要求: 从调用链追到 RP2040 I2C/reset/GPIO 最底层, 找到并消除 I2C0 与 I2C1 的 Recovery 耦合。

**审查结果: 该耦合在当前源码中不存在。** 逐层证据见第 3/4/5 节。全工程范围内:

- I2C0 外设、GPIO16/17 只被 `mpr121.cpp` 一个翻译单元接触
- I2C1 外设、GPIO6/7、XSHUT (GP1~GP5) 只被 `vl53l0x.cpp` 接触
- 全工程 **零处** 直接调用 `reset_block` / `unreset_block` / `RESETS_RESET_I2C0_BITS`
- 无共享 I2C 驱动状态、无统一 I2C 恢复函数、无 system/board/peripheral reinit
- 引脚映射零重叠 (XSHUT=1..5, I2C1=6/7, I2C0=16/17, 按键/LED=18/19/25/27/28)

若真机上观察到 MPR121 受扰, 软件层已被本报告排除 (第 4/5/15 节给出完整证明链),
应转向电气层排查 (共电源轨跌落、上拉强度、走线串扰、EMI)。

## 2. Existing I2C0 / I2C1 Architecture

```
                 ┌── VL53L0X #0 (addr 0x2A..0x2E)
                 ├── VL53L0X #1
Core1 ── I2C1 ──├── VL53L0X #2        GPIO6=SDA  GPIO7=SCL  XSHUT=GP1~GP5
                 ├── VL53L0X #3
                 └── VL53L0X #4
                      │
                      ├── vl53l0x_recover_sensor(i)   ← Level 1: 设备级
                      ├── vl53l0x_bus_recover()       ← Level 2: I2C1 总线级
                      └── vl53l0x_reinit_all()        ← Level 3: 最后手段

Core0 ── I2C0 ── MPR121×3 (0x5A/0x5B/0x5C) ── Slider   GPIO16=SDA  GPIO17=SCL
```

两条总线域的实现层面隔离 (审计实证):

| 资源 | 唯一接触者 | 初始化时机 |
|---|---|---|
| `i2c0` 外设, GPIO16/17, pull-up | `mpr121.cpp` (write/read 全部走 `I2C0_PORT`) | `mpr121_init()` ← `slider_init()` ← Core0 冷启动 (main.cpp:653) |
| `i2c1` 外设, GPIO6/7, pull-up | `vl53l0x.cpp` (全部走 `I2C1_PORT`) | `vl53l0x_init()` ← Core1 冷启动 (tof_reader_task) |
| XSHUT GP1~GP5 | `vl53l0x.cpp` (`xshut_pins[]`) | `vl53l0x_init()` + 各级恢复 |
| MPR121/Slider 符号 | 恢复路径中 **零引用** | — |

## 3. Root Cause of I2C0 Reset

**不存在。** 按 spec 要求逐项排查了所有可能的耦合通道, 结果:

| 排查项 (spec §30) | 搜索结果 | 判定 |
|---|---|---|
| 直接 `i2c_deinit(i2c0)` / `i2c_init(i2c0)` | 仅 `mpr121.cpp:237` 一处 init (冷启动) | 无恢复路径调用 |
| `reset_block` / `unreset_block` / `RESETS_RESET_*` | **全工程 0 处** (grep src/) | 无 |
| GPIO mux 批量重配置 | 恢复路径只操作 `I2C1_SDA/I2C1_SCL`/XSHUT 具名常量, 无循环遍历"所有 I2C GPIO" | 无 |
| GPIO pull-up 误配置 | 恢复路径 pull-up 仅作用于 GP6/GP7 | 无 |
| 共享驱动状态 (`i2c_inst*` 全局指针/current_i2c/bus_state) | **0 处** | 无 |
| 共享初始化函数 / `system_init` / `board_init` / `peripheral_init` | **0 处** | 无 |
| SDK 层 `i2c_init/i2c_deinit` 内部复位掩码 | `reset_block_num(I2C_RESET_NUM(i2c))` —— 按实例精确 (见下) | 硬件层亦隔离 |
| 引脚物理重叠 | XSHUT(1-5)/I2C1(6,7)/I2C0(16,17) 两两不同, 且已由 static_assert 编译期强制 | 无 |

SDK 2.3.0 底层证据 (`~/.pico-sdk/sdk/2.3.0/src/rp2_common/hardware_i2c/i2c.c:18-60`):

```c
static inline void i2c_reset(i2c_inst_t *i2c) {
    reset_block_num(I2C_RESET_NUM(i2c));      // ← 仅该实例的复位位
}
uint i2c_init(i2c_inst_t *i2c, uint baudrate) {
    i2c_reset(i2c); i2c_unreset(i2c); ...     // 实例精确, 无批量掩码
}
void i2c_deinit(i2c_inst_t *i2c) { i2c_reset(i2c); }
```

即: 总线恢复中的 `i2c_deinit(I2C1_PORT)` + `i2c_init(I2C1_PORT)` 在 RP2040 reset
controller 层面也只脉冲 `RESETS_RESET_I2C1` 一个位, `I2C0` 的复位位不被触碰。

## 4. Recovery Call Chain Before Modification

(本次审查时的实际代码, 逐函数核实)

```
Core1 tof_reader 状态机
├─ attempt_recovery(i)                          [tof_reader.cpp]
│   └─ vl53l0x_recover_sensor(i)                [vl53l0x.cpp]
│       ├─ gpio_put(xshut_pins[i], 0)           ← 仅 XSHUT[i]
│       ├─ yield_sleep_us() → 让出回调 → poll_ready_sensors()
│       │     └─ vl53l0x_read_distance_ex(i)    ← 仅 I2C1, 仅健康传感器
│       └─ init_sensor(i)                       ← 仅 I2C1 寄存器读写
│           (XSHUT→0x29 地址分配→完整配置→TB=20000us→读回验证→连续测距)
│
├─ run_bus_recovery()                           [tof_reader.cpp]
│   ├─ vl53l0x_bus_recover()                    [vl53l0x.cpp]
│   │   ├─ i2c_deinit(I2C1_PORT)                ← SDK 内部: reset_block_num(i2c1) 实例精确
│   │   ├─ gpio_set_function/init/dir/pull_up   ← 仅 I2C1_SDA(6) / I2C1_SCL(7)
│   │   ├─ 9-clock + STOP (开漏位拆)             ← 仅 GP6/GP7
│   │   └─ i2c_init(I2C1_PORT)                  ← 同上, 实例精确
│   ├─ 存活甄别: vl53l0x_probe_sensor(i)         ← 仅 I2C1, 读 MODEL_ID 不改配置
│   └─ 失败 → vl53l0x_reinit_all()              ← 仅 XSHUT[0..4] + I2C1
```

**链路终点全部落在 I2C1 / GPIO6/7 / XSHUT[0..4] 上, 没有分支通向 I2C0。**

## 5. Recovery Call Chain After Modification

与第 4 节完全一致 —— 本次没有改动任何恢复逻辑 (这是审查结论的自然结果:
不存在需要拆除的耦合)。新增的是 **防护层**, 不是行为变更:

```
VL53L0X Recovery API
        ↓ 只允许访问 (现在由编译器 + 模块边界双重保证):
    i2c1 外设 / GP6 GP7 / XSHUT[0..4] / VL53L0X 寄存器与状态
        ↓ 明确禁止 (现在有文档声明 + 编译期引脚校验):
    i2c0 / GPIO16 17 / MPR121 / Touch / Slider / USB / 板级初始化
```

新增防护:
1. `board_defs.h` —— `static_assert(chuni_board_pins_distinct())`: I2C0/I2C1/XSHUT/
   按键/LED 全部引脚两两不同的不变量交由编译器强制。未来任何人改引脚分配,
   若引入重叠, **编译立即失败**, 而不是上线后 MPR121 莫名受扰。
2. `vl53l0x.h` / `mpr121.cpp` —— Recovery Access Boundary 与 I2C0 独占声明的文档化。

## 6. I2C0 Protection Mechanism

四层防线 (本次修改后):

1. **翻译单元边界**: I2C0 只存在于 `mpr121.cpp`; 恢复代码 (tof_reader.cpp/vl53l0x.cpp)
   不 include mpr121.h, 无任何 MPR121/Slider 符号引用 (grep 实证)。
2. **内核边界**: I2C0 只在 Core0 访问 (mpr121_update 位于 Core0 主循环);
   I2C1 只在 Core1 访问。无跨核调用。
3. **SDK 实例精确复位**: `i2c_init/deinit` → `reset_block_num(I2C_RESET_NUM(i2c))`,
   复位掩码精确到单个外设实例。
4. **编译期引脚隔离不变量** (本次新增): `board_defs.h` static_assert。

## 7. I2C1 Sensor Recovery

- 入口: `vl53l0x_recover_sensor(index)`, 仅操作 `xshut_pins[index]` + `init_sensor(index)`
- 与冷启动共享同一条 `init_sensor()` 路径 (无第二套初始化实现)
- 长等待通过让出回调继续轮询其他健康传感器 (I2C1), 恢复不阻塞健康传感器数据
- **I2C1 外设本身不被 reset** (符合 spec §8: 设备级恢复优先, 不动外设)
- **I2C0: 全程零接触**

## 8. I2C1 Bus Recovery

- 入口: `vl53l0x_bus_recover()`, 触发条件为总线级证据 (全部就绪传感器同时静默≥60ms,
  或反复设备级恢复失败且无人应答), 不是单传感器错误
- 步骤: `i2c_deinit(i2c1)` → GP6/GP7 转 SIO 开漏 → SDA 卡低检测 → 9 时钟 + STOP
  (全程开漏, 严禁推挽高) → 验证释放 → `i2c_init(i2c1)` → 恢复 GPIO 功能
- GPIO/pull-up 操作严格限定 `I2C1_SDA`/`I2C1_SCL` 两个宏, 无批量循环
- **I2C0: 全程零接触** (包括 GPIO16/17 的功能、方向、pull-up 均不被读写)

## 9. Full VL53L0X Recovery

- 入口: `vl53l0x_reinit_all()`, 仅在总线恢复失败 (总线仍卡死) 时作为最后手段
- 范围: XSHUT[0..4] 拉低 → 逐颗释放 + `init_sensor(i)` (共用同一初始化路径)
- 不重新初始化 I2C1 外设 (总线恢复已做过, 或已判定外设可用)
- **I2C0 / MPR121: 零接触; USB/PIO/PWM/UART: 零接触; 无任何板级 reinit**

## 10. TimingBudget Verification

- 唯一配置源: `VL53L0X_TIMING_BUDGET_US = 20000us` (vl53l0x.cpp)
- 唯一配置点: `init_sensor()` 第 11 步 `set_measurement_timing_budget(…, 20000)`
- 冷启动、单传感器恢复、全量恢复全部经由同一 `init_sensor()` → **同一 TB 配置**
- 每次初始化都从寄存器读回实际 budget 并校验 (容差内), 失败则该传感器判恢复失败
- 串口验证: 上电每颗打印 `TOFx ready: TB=19981us` (20000us 配置经芯片重算的
  实际值, 属预期读数); 恢复成功后同样输出该行
- 本次修改未触碰任何 TB 相关代码

## 11. Files Modified

| 文件 | 修改内容 | 性质 |
|---|---|---|
| `src/board_defs.h` | 新增编译期引脚隔离 static_assert (~30 行) | 防护性新增 |
| `src/vl53l0x.h` | 新增 Recovery Access Boundary 文档块 (~10 行) | 文档 |
| `src/mpr121.cpp` | 新增 I2C0 独占声明 (~8 行) | 文档 |
| `TOF_I2C_ISOLATION_RECOVERY_REPORT.md` | 本报告 | 新增 |

**恢复逻辑零改动**: `vl53l0x.cpp` / `tof_reader.cpp` / `main.cpp` / `air.cpp` /
`tof_reader.h` 的可执行代码本轮无任何修改 (上一轮 Recovery 粒度重构保持不变)。

## 12. Functions Modified

无函数签名/逻辑修改。`board_defs.h` 新增两个 `constexpr` 函数
(`chuni_board_pins_distinct()` 等, 仅编译期求值, 零运行时开销)。

## 13. Functions Removed / Refactored

无。审查确认不存在 spec §4/§27 描述的 "统一 I2C 恢复公共函数" (如
`recover_i2c_bus()` 内部 reset 双总线) 或 `system_i2c_reinit()` —— 无可拆除对象。

## 14. Before / After Architecture

| 情况 | 修改前 | 修改后 |
|---|---|---|
| A: 单颗偶发错误 | 计数容忍, 不触发恢复 | 不变 |
| B: VL53L0X #2 真正掉线 | 仅 XSHUT[2] + init_sensor(2); I2C0 不动, MPR121 不动, 其余 4 颗不动 | 不变 |
| C: I2C1 卡死 | 仅 i2c1 deinit/GP6-7 位拆/reinit; I2C0 不动, MPR121 不动 | 不变 + 引脚隔离由 static_assert 强制 |
| D: I2C1 恢复失败 | 仅 XSHUT[0..4] + 逐颗 init; I2C0 不动, MPR121 不动 | 不变 |
| 引脚分配引入重叠 (人为失误) | 静默接受, 上线后表现不可预测 | **编译失败**, 隔离破坏在构建期暴露 |

## 15. Remaining Limitations

1. **软件层已证明无耦合, 但不能证明真机无电气耦合。** 若现场仍观察到 ToF 恢复时
   MPR121 受扰, 排查方向 (按可能性):
   - 共用 3V3 轨: 5 颗 VL53L0X 同时上电/恢复的浪涌导致电压跌落, MPR121 需要重新
     上电稳定时间 —— 示波器看 3V3 轨
   - I2C0 上拉强度不足或走线过长, 对 GP1-7 的 XSHUT 边沿串扰敏感
   - MPR121 电极/飞线拾取 EMI (与固件恢复行为时间上巧合)
2. static_assert 只覆盖 `board_defs.h` 内的引脚; `main.cpp` 中局部定义的
   BUTTON_ENTER_PIN(GP18)/BUTTON_2_PIN(GP19) 未纳入 (与总线引脚无重叠, 风险为零,
   如需可后续收编进 board_defs.h)。
3. C 翻译单元 (若未来引入 .c 文件) 不受 static_assert 保护 —— 当前工程全部为 C++,
   全部翻译单元都参与校验。

---

## 附录: Spec 三十六节 12 问逐答

1. **为什么 VL53L0X Recovery 会导致 I2C0 被 reset?** —— 不会。经全调用链审计 +
   SDK 底层核实, 不存在这样的路径 (第 3 节)。
2. **哪个函数/调用链导致了这个问题?** —— 无。最近的 "嫌疑" 是总线恢复中的
   `i2c_deinit(I2C1_PORT)`, 但其 SDK 实现 (`i2c.c:58-60`) 是实例精确复位。
3. **是否存在统一 I2C reset / reinitialization?** —— 不存在。无 `reset_block`
   调用, 无公共恢复函数, I2C0/I2C1 初始化分别封闭在 mpr121.cpp / vl53l0x.cpp。
4. **修改后 Sensor Recovery 是否会触碰 I2C0?** —— 否。仅 XSHUT[i] + I2C1 寄存器。
5. **修改后 I2C1 Bus Recovery 是否会触碰 I2C0?** —— 否。GPIO/pull-up/deinit/init
   全部限定 GP6/GP7 + i2c1 实例。
6. **修改后 Full VL53L0X Recovery 是否会触碰 I2C0?** —— 否。仅 XSHUT[0..4] + I2C1。
7. **MPR121 是否还会被重新初始化?** —— 否。`mpr121_init` 唯一调用点是 Core0 冷启动
   的 `slider_init()`; 恢复代码不含任何 MPR121 符号。MPR121 从头到尾连续运行。
8. **I2C0 SDA/SCL GPIO 是否可能被 ToF Recovery 修改?** —— 不可能。GP16/17 只被
   `mpr121.cpp:238-241` 配置一次; 且引脚两两不同已由 static_assert 编译期强制。
9. **RP2040 reset controller 是否只 reset I2C1?** —— 是。SDK 2.3.0 用
   `reset_block_num(I2C_RESET_NUM(i2c))` 逐实例复位, 无批量掩码 (i2c.c:18-26)。
10. **I2C0 是否能够在整个 ToF Recovery 过程中保持连续运行?** —— 能。Core0 主循环
    从不等待 Core1 恢复 (快照异步消费), MPR121 事务使用 500us `_until` 超时独立
    完成于 I2C0 上。
11. **Cold Boot 是否仍然能够正常初始化 I2C0 + I2C1?** —— 是。Core0: `slider_init →
    mpr121_init → i2c_init(i2c0)`; Core1: `vl53l0x_init → i2c_init(i2c1)`。本次
    零逻辑改动。
12. **TimingBudget 是否仍严格为 20ms / 20000us?** —— 是。单一配置点未动, 每次初始化
    (冷启动/恢复) 均写 20000us 并读回校验。

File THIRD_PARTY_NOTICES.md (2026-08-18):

# Third-Party Notices

## Chu Pico

https://github.com/whowechina/chu_pico

This project was inspired by the architecture and implementation
approach of Chu Pico by whowechina.

Chu Pico is licensed under CC BY-NC 4.0.

No Chu Pico source code is intentionally redistributed in this
repository.

## Pololu VL53L0X Arduino Library

https://github.com/pololu/vl53l0x-arduino

The VL53L0X initialization sequence in `src/vl53l0x.cpp`
is derived from the Pololu VL53L0X Arduino library.

The Pololu library is substantially based on ST's VL53L0X API.

The remaining RP2040-specific driver implementation,
multi-sensor management, XSHUT/address management,
data-ready handling and error handling were independently
implemented for Chunitof Pico.

See the upstream repository for the applicable license.

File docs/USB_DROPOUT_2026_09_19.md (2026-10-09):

# Pico USB 掉线复核与修复（2026-09-19）

后续版本见 [2026-09-20 非阻塞排查与修复](USB_DROPOUT_2026_09_20.md)。本文保留当轮记录；当前固件已用异步 I2C 替代有界同步读取，并启用分步 ToF 恢复。

## 结论和证据边界

用户观察：运行中偶发 USB 掉线，LED 常亮，多数能自行重连，少数需要拔插。
本轮检查的是当前工作区（已有多处未提交的历史修复），不是假定板内固件一定
与源码相同。未连接硬件调试器，不能宣称已复现用户现场或确认唯一根因。

确认的代码问题及处理：

| 问题 | 后果 | 本次修改 |
| --- | --- | --- |
| SDK 2.3.0 读取函数等待 TX FIFO 空位时没有检查超时 | 若 FIFO 一直满，Core0 可以停止服务 USB；Core1 也有相同漏洞 | 两条总线均使用项目内有界读取函数 |
| MPR121 把所有非负 I2C 返回值视为成功 | 数据 NACK 时 SDK 可返回短写/0，仍进入后续读取 | 核对返回长度，失败继续原有计数及保留旧触摸状态策略 |
| USB 在 MPR121 初始化的约 800 ms 固定等待之前连接 | 启动及复位重连时不能及时处理枚举请求 | 传感器启动完成后再连接 USB |
| 看门狗只覆盖运行期 | 复位后若再次卡在初始化，无法自动再次复位 | 初始化使用 8 s，看门狗在运行期收紧至原有 2 s |
| printf 禁用且 stdio 后端关闭，原 STATUS 实际无法读出现场 | 重连后无法区分看门狗复位和单纯 USB 问题 | 新增不依赖 printf 的 `USBSTATUS` |
| LED IRQ 读取 Core0 正在修改的 64 位时间戳 | RP2040 上可能读取到不一致时间戳而误报 LED 状态 | 主循环计算状态，IRQ 只读单字节标志 |

I2C 缺陷已与[官方 SDK 2.3.0 源码](https://github.com/raspberrypi/pico-sdk/blob/2.3.0/src/rp2_common/hardware_i2c/i2c.c#L286-L287)
及本机安装文件核对。历史报告“所有 I2C 等待均有超时”的说法已更正。
FIFO 满的故障注入证明原等待条件缺少退出机制，不代表已证明日常轮询必然进入该状态。

为减少时钟裕量干扰，系统时钟由固定 150 MHz 改为 125 MHz。
这是稳定性措施，不是已经证明 150 MHz 导致本次掉线；USB 仍使用其独立时钟。

## 检测逻辑保持

- `slider.cpp`、`air.cpp`、ToF 快照/检测处理没有修改。
- MPR121 寄存器初始化、模式、阈值、轮转顺序、触摸位图及失败保留旧状态策略不变。
- VL53L0X 初始化内容、400 kHz I2C、20000 us 测量预算、距离筛选和恢复策略不变。
- 键盘映射、NKRO 报告格式、按键保持时间不变。
- 每个 I2C 控制器仍由原来的核独占；错误返回不会复位传感器或另一条总线。

`i2c_bounded.h` 只替换底层读取，成功时保持逐字节读取和 RESTART/STOP 行为。
失败时请求禁用本控制器并清除软件 RESTART 标志，不等待总线释放；下次事务
仍按 SDK 的流程重新启用控制器。不会发 XSHUT、重写阈值或自动重试。
物理上一直拉低的总线仍可能需要修复接线/供电，这一修改保证的是软件等待有界。
中断抢占和 Flash 操作不计入 I2C 等待截止时间的保证范围。

USB 挂起/恢复状态同步到 TinyUSB 实际状态，恢复后强制重发当前按键报告。
现有 `CHUNI_USB_AUTO_RECOVERY_ENABLE=0` 保持不变，不新增周期性软断开。

## LED 和复位记录

当前 LED 由 10 ms 定时器驱动，常亮表示观察到某一主循环阶段停留超过 50 ms。
这可以是长操作，也可以是永久等待；IRQ 停止执行时 LED 还可能停留在原电平。
历史固件曾有“最大耗时超过 5 ms 后永久常亮”的逻辑，更不能用旧 LED 单独定因。

运行期看门狗只能在完整主循环结束时喂狗。若未暂停于调试器、时钟/供电正常，
阻塞超过约 2 s 会复位，因此用户所述“多数自行重连”与此机制相符。
复位后 `prev` 是被中断前的主循环阶段；若实际卡在 IRQ，它不等同于 IRQ 内 PC。
`prev=TUD_TASK` 也不能直接排除当时有 USB IRQ 阻塞，需要 SWD 栈/PC 才能进一步定位。

## 使用 USBSTATUS

刷入 `build/Chuni245Tof.uf2`，在设备 CDC 串口发送一行：

```text
USBSTATUS
```

打开串口时启用 DTR。默认固件就支持此命令，不需要开启 printf。
回复示例（仅说明格式）：

```text
USB boot=2 wdt=1 prev=SLIDER loops=123456 core1=654321 gap_us=900 mpr=0,0,0 mount=1 suspend=0 sys_khz=125000
```

- `wdt=1`：硬件记录上一次复位由看门狗引起。
- `prev` / `loops`：看门狗复位前的阶段/完成循环数。`SENSOR_INIT` 表示启动阶段。
  冷启动或保留数据校验失败时不解读旧 RAM，显示 `IDLE` / 0。
- `core1`：本次启动 Core1 心跳；间隔查询可观察是否递增。
- `gap_us`：本次启动两次 USB task 服务的最大间隔。
- `mpr`：本次启动三颗 MPR121 的通信错误数，重启会重新计数。
- `boot`：只有 SRAM 内容保留且 magic 匹配才延续，不能把它当成掉电/欠压检测器。

每次请求最多排入一条小于 256 字节的回复，TX 空间不足直接跳过，不等待主机。
若没有回复，恢复读取后再查询。不要为了读取诊断重新开启阻塞的 stdio USB 后端。
发生自动重连后应先读取这一行，再断电；拔插会使保留现场不可靠。

## 验证结果与上板检查

已完成：

1. Pico SDK 2.3.0 / GCC 15.2 Release 构建，生成 ELF/UF2。
2. 本机 C++ 故障注入回归：正常字节、RESTART/STOP、FIFO 延迟、TX FIFO 满、
   RX 不返回、中途停住、abort、已过截止时间、跨 32 位时间边界、两总线隔离。
   测试运行生产读取函数；硬件寄存器/时钟为模拟对象，详见 `tests/README.md`。

仍需在用户硬件上验证：

1. 连续游戏/待机运行，覆盖原来掉线所需时间，保留 `USBSTATUS` 结果。
2. 在安全接线条件下模拟传感器无响应，确认对应错误增加、USB/HID 和另一条总线仍工作。
3. 主机睡眠/唤醒、串口打开但不读取、拔插 USB 后能重新枚举及恢复按键。
4. 若仍掉线，记录是否为 `wdt=1`、`prev`、是否有 SAVE 操作，以及 VBUS/3V3 波形。

USB E5/E15 规避在现有 SDK 构建中已启用，不把重复启用当作本轮修复。
TinyUSB `OPT_OS_PICO` 的队列读取忽略等待参数并立即返回，所以不能把
`tud_task()` 的 `UINT32_MAX` 参数单独当作这里的死锁证据。
驱动的 EP0 abort 等待仍依赖 USB 硬件，运行期看门狗用于兜底；无现场证据时不改动 SDK。
SAVE 会暂停双核及 USB 服务，本轮没有改变 Flash 持久化策略。
线缆、供电、ESD 和实际 USB 控制器异常，不能仅通过软件编译/模拟测试排除。

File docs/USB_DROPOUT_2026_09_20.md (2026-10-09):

# USB / ToF 非阻塞排查与修复（2026-09-20）

## 结论与证据范围

现象：前一版降低了 USB 掉线频率，但仍会掉线并在约 2 秒后恢复；有时 MPR121 和 USB 正常，五颗 VL53L0X 都不再提供数据。

本轮确认并修复了源码中的阻塞和恢复缺陷；未连接实机/SWD，不能把某一条路径断言为现场唯一根因。约 2 秒与现有运行期看门狗期限吻合，但需要重连后的 `USBSTATUS wdt` 才能确认发生过看门狗复位。

| 确认的问题 | 影响 | 当前处理 |
| --- | --- | --- |
| TinyUSB RP2040 `reset_ep0()` 在 USB IRQ 内无限等待 `abort_done` | 若硬件不完成 ABORT，中断不能退出；USB/主循环/LED 更新可能一起停止，随后看门狗复位 | IRQ 只检查一次，未完成则交主循环继续；1 ms 仍未完成时关闭 USB IRQ，拆卸并在 250 ms 后重新初始化 USB |
| 上轮有界读取在超时后只请求 `enable=0`，未确认禁用完成；寄存器地址写和读仍是分开的同步调用 | 外设可能保留活动事务/FIFO 状态，后续访问持续失败；有超时仍会占用整个调用时间 | 两条总线均换成 `AsyncI2c`，一笔完整的 pointer/RESTART/read/STOP 跨循环推进，等待禁用完成后才修改地址；异常只复位对应 I2C 控制器 |
| ToF 自动恢复默认关闭 | Core1 即使活着，也可能一直报错，五颗没有自动恢复 | 默认启用分级恢复，全部为协作式任务 |
| 初始化、SPAD/参考校准、XSHUT/总线恢复有同步等待和递归让出；Core1 使用 `sleep_us` | 恢复本身延迟调度，且依赖共享 alarm pool | 固定内存 C++20 状态机，每次只推进一个叶任务；等待用 deadline/suspend 返回调度器；Core1 不再使用 sleep/alarm pool |
| 多颗 ToF 共同复位后回到 `0x29`，逐颗恢复可能把地址写同时发给多颗 | 修改成相同地址，无法可靠恢复全部传感器 | 目标保持 XSHUT 低时先检查 `0x29`；若仍有应答，停止单颗恢复，所有 XSHUT 拉低后逐颗重新分配地址 |
| Flash 协作进入/退出各允许等待 1000 ms | 加上擦写可能超过 2 s 看门狗期限 | 先检查 Core1 已注册 Flash 协作且心跳新鲜，进入/退出各限制 10 ms |

共同复位的地址冲突已在模型测试中复现：加入检查前，测试在“向多个同址传感器写配置/地址”的断言处失败；加入检查后，两颗同时复位和五颗同时复位均恢复到 `0x30`～`0x34`。这证明了恢复路径缺陷，不证明实机存在供电瞬断。

## 实现与保留项

- `src/i2c_async.h`：每次 `step()` 最多推进一个 RX 字节和一个 TX 命令，不等待 FIFO、ACK、STOP、禁用或复位完成。MPR 事务截止时间 500 us，ToF 3000 us；超时后的本控制器复位完成检查最多再给 100 us，检查本身同样不忙等。若调用方被外部暂停，截止时间在下一次调用时处理。
- `src/cooperative_task.h`：仅 Core1 使用 24 个固定的 1024 字节帧，不依赖堆或跨核分配器锁。分配失败返回默认失败结果并增加诊断计数。管理任务与采样任务共用唯一 I2C1 所有者；其他健康传感器可在单颗初始化期间继续采样。
- `src/tof_reader.cpp`：心跳从冷启动开始持续更新，发布 stage/进展时间；共享快照增加内存屏障。个体失败退避重试，总线持续失联才升级恢复；不直接强制重启 Core1，避免打断持锁中的 SDK 代码。
- `src/mpr121.cpp`：冷启动、轮询、CONFIG、RESET 全部分步推进；保留完整读成功后更新触摸位图、失败保留旧状态的语义。连续 CONFIG 会补做完整一轮，确保已经写过的通道也得到最终值。DEBUG 使用缓存，不另起同步 I2C 访问。
- `cmake/PatchTinyUsb.cmake`：只修补构建目录中的驱动副本，保留上游许可证，不修改用户 SDK。匹配点变化时配置阶段直接报错，要求重新审查补丁。仅 ToF 翻译单元要求 C++20，CMake 最低版本 3.18。
- `src/main.cpp`：USB 故障重初始化期间暂停 TinyUSB 类接口访问，传感器和主循环继续工作；重新枚举后发送当前 HID 状态。BOOTLOADER 的 100 ms 等待也改为 deadline。

相对本轮开始时，`air.cpp`、`slider.cpp`、`button.cpp`、`config.cpp`、`usb_descriptors.c` 未改变。触摸硬件判定、阈值/滤波寄存器、键位/HID 格式、距离有效性（0 或 ≥8190 处理为 8190）、保持时间和 20 ms 测距预算保持不变。VL53L0X tuning 表与本轮基线逐字节相同。改变的是 I/O 调度、故障处理及恢复策略，轮询频率因此需在实机确认。

## 仍然存在的同步边界

“非阻塞”覆盖本项目的传感器运行、初始化和恢复流程，以及已识别的 EP0 ABORT 无限等待。并非宣称整个 SDK 或芯片在任意硬件故障下都能非阻塞。

- 显式 `SAVE` 仍通过 SDK Flash 安全机制擦写 XIP Flash，期间两核与 USB 服务会暂停。当前架构下不能把 Flash 擦写改成普通轮询，同时又继续从同一 Flash 安全执行。保存请求仍在空闲窗口执行，等待超过原有 10 秒上限可强制执行；本轮没有改动配置存储格式或保存策略。
- 启动时的 Core1 launch、USB 控制器初始化、SDK 短临界区/硬件自旋锁仍存在；GPIO 启动采样有一次 100 us 等待。它们不是传感器运行循环的一部分。未知 IRQ 故障或硬件故障仍由原有看门狗兜底。
- 持续拉低的物理总线不能由软件保证恢复；状态机能保持心跳和重试，但实机电平/供电仍需测量。

## 刷机与诊断

固件：`build/Chuni245Tof.uf2`。刷入后通过 CDC 串口逐行发送以下命令（行尾换行即可），读取回复；不需要打开 printf。`USBSTATUS` 应包含 `rev=20260920`。

```text
USBSTATUS
TOFSTATUS
```

两条命令每条最多回复一行；主机不读取或发送缓冲不足时跳过，不等待。故障前、恢复后分别保留一组即可；ToF 异常时可间隔 1 秒连读两次。

| 字段 | 判断方式 |
| --- | --- |
| USB `boot`、`wdt`、`prev` | boot 增加且 wdt=1 表示看门狗复位；prev 是当时主循环阶段，不能当作 IRQ 内的 PC |
| `usb_abort` | 本次 MCU 启动以来确认的 EP0 ABORT 超时数；它增加且 boot 不变表示 USB 局部恢复，而不是整机重启 |
| USB `gap_us` | 本次启动以来 USB 服务间隔最大值；显式 SAVE 也会使它增大 |
| TOF `hb`、`age_us` | 连续读取 hb 增加、age_us 很小表示 Core1 正在调度；hb 不变且 age_us 持续增长才支持 Core1 停止推进 |
| TOF `stage` | 1=Flash 协作注册，2=驱动推进，3=采样，4=恢复管理，5=本轮完成；单次读到某个值不代表卡死 |
| TOF `job` | 0=无管理任务，1=启动，2=单颗恢复，3=总线清理，4=全量重新分配/初始化，5=存活探测 |
| TOF `io` | 0=空闲，1=本控制器复位，2=等待禁用完成，3=事务；单次值仅代表快照 |
| TOF `ready`、`data_ms` | ready=1f 表示五颗已初始化；data_ms 按 TOF1～5 表示快照年龄，4294967295 表示无有效快照。ready 本身不保证正在产出新样本 |
| TOF `reset`、`err` | I2C1 控制器异常复位次数及各传感器采样错误；恢复时探测空地址产生的 NACK 也可能计入 reset |
| TOF `frames_fail` | 应为 0；非零表示固定任务帧不足或尺寸不适用，需要检查构建和调用深度 |

## 验证记录

- Pico / RP2040、SDK 2.3.0、ARM GCC 15.2 Release 编译通过，生成 ELF/BIN/UF2。
- 原生模型使用实际驱动和 Core1 循环，覆盖 FIFO/RX/STOP/disable/reset 卡住、SPAD/校准不完成、单颗掉线、共享总线卡住、两颗/五颗共同复位、MPR 并行读取及 CONFIG/RESET。
- USB 测试从 CMake 生成的实际 DCD 副本提取函数，验证延后处理、只提交一次 SETUP、1 ms 超时与计时回绕、异常关闭 IRQ、B0/B1 原分支。
- ELF 不再链接 `i2c_read_blocking` / `i2c_write_blocking` / `sleep_us` / `sleep_ms`。这不等价于所有 SDK 路径无任何同步等待。
- 检测层文件与本轮基线比对未改变；代码空白检查通过。测试命令及模型限制见 [tests/README.md](../tests/README.md)。

仍需实机长时间运行，以及 USB 重枚举、单颗传感器掉线、共同复位、显式 SAVE 后恢复的检查。未进行实机烧录或声称完成硬件验证。

## 上游源码依据

核对的是本机 SDK 配套 TinyUSB 提交 `86ad6e56c1700e85f1c5678607a762cfe3aa2f47` 的 [RP2040 DCD](https://github.com/hathach/tinyusb/blob/86ad6e56c1700e85f1c5678607a762cfe3aa2f47/src/portable/raspberrypi/rp2040/dcd_rp2040.c)，以及 SDK 2.3.0 的 [I2C](https://github.com/raspberrypi/pico-sdk/blob/2.3.0/src/rp2_common/hardware_i2c/i2c.c) 与 [Flash 安全协作](https://github.com/raspberrypi/pico-sdk/blob/2.3.0/src/rp2_common/pico_flash/flash.c)。上游代码解释了可能的等待路径，不替代现场日志。

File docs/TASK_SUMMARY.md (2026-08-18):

# 完成的任务总结

## ✅ 已完成的所有任务

---

### 1. BOM 文件处理

#### 创建的文件

| 文件 | 位置 | 说明 |
|---|---|---|
| **BOM_CN.csv** | `PCBnCAD/BOM_CN.csv` | 中文物料清单（真正的 CSV 格式） |
| **BOM_EN.csv** | `PCBnCAD/BOM_EN.csv` | 英文物料清单 |

#### 内容

| 项目 (中文) | Item (English) | 数量 | 要求 |
|---|---|---|---|
| PICO RP2040开发板 | PICO RP2040 Development Board | 1 | 无焊接/Solderless |
| MPR121接近电容式触摸传感器模块 | MPR121 Proximity Capacitive Touch Sensor Module | 3 | 30.6mm*20.5mm模块，无焊接 |
| VL53L0X飞行时间测距模块 | VL53L0X Time-of-Flight Ranging Module | 5 | 25mm*12mm两侧带M3螺丝模块，无焊接 |
| 6*6脚立式微动开关 | 6x6 Tactile Push Button Switch | 2 | 高度随意/Any height |
| M3*8子母铆钉对接螺丝 | M3x8 Male-Female Standoff Screw | 9 | - |
| 排针 | Pin Headers | 若干 | As needed |
| 亚克力板 | Acrylic Panel | 需定制或自己切割 | Custom or DIY cutting |
| PCB板 | PCB Board | 需定制 | Custom production |

---

### 2. 多语言 GUI 支持

#### 功能特性

- ✅ **自动检测系统语言**：启动时根据 Windows 系统语言自动选择
  - 简体中文系统 → 中文界面
  - 其他系统 → 英文界面

- ✅ **实时语言切换**：GUI 顶部的语言下拉菜单
  - `zh_CN` = 中文
  - `en_US` = English
  - 切换后立即生效，无需重启

- ✅ **完整翻译覆盖**：
  - 所有界面文字
  - 按钮标签
  - 消息框
  - 错误提示
  - 帮助文本

#### 实现方式

```python
# 语言管理器
class LanguageManager:
    LANG_CN = 'zh_CN'  # 中文
    LANG_EN = 'en_US'  # 英文

    def detect_system_language(self):
        """检测系统语言"""
        # Windows API 检测
        import ctypes
        windll = ctypes.windll.kernel32
        lang_code = windll.GetUserDefaultUILanguage()
        # 返回对应语言代码

    def switch_language(self, lang_code):
        """切换语言"""
        self.current_lang = lang_code
```

#### 控件保存和更新

```python
# 保存所有需要多语言支持的控件引用
self.lang_widgets = {
    'config_frame': config_frame,
    'touch_label': touch_label,
    'btn_read': btn_read,
    ...
}

# 语言切换时更新所有控件
def update_ui_language(self):
    for key, widget in self.lang_widgets.items():
        if isinstance(widget, ttk.LabelFrame):
            widget.config(text=lang_manager.get(key))
        elif isinstance(widget, ttk.Label):
            widget.config(text=lang_manager.get(key))
        elif isinstance(widget, ttk.Button):
            widget.config(text=lang_manager.get(key))
```

---

### 3. 默认配置更新

| 参数 | 原值 | 新值 |
|---|---|---|
| **Pitch (级高)** | 40mm | **30mm** |
| **Min Hold (最小保持)** | 50ms | **100ms** |

更新范围：
- 固件默认值 (`src/config.cpp`, `src/main.cpp`, `src/air.cpp`)
- GUI 默认值 (`tools/config_cdc.py`)
- 文档 (`README.md`, `tools/README.md`, 等)

---

### 4. Flash 持久化修复

完整修复了配置掉电保存功能：

- ✅ 修正 Flash 地址计算（使用 `PICO_FLASH_SIZE_BYTES`）
- ✅ 增加 CRC32 校验
- ✅ 增加版本号管理
- ✅ 增加写入验证
- ✅ 固件返回明确结果
- ✅ GUI 检查返回值

---

### 5. EXE 打包

#### 打包信息

- **文件名**: `ChunitofPicoConfig.exe`
- **位置**: `tools/dist/ChunitofPicoConfig.exe`
- **大小**: ~10 MB
- **功能**: 多语言配置工具

#### 特性

- 单文件 exe，无需安装
- GUI 模式（无控制台窗口）
- 包含所有依赖（Python, tkinter, pyserial）
- 支持多语言切换

#### 打包命令

```bash
cd tools
python -m PyInstaller --onefile --windowed --name ChunitofPicoConfig --clean --noconfirm config_cdc.py
```

---

## 📂 文件结构

```
Chuni245Tof/
├── PCBnCAD/
│   ├── BOM_CN.csv          ← 中文物料清单 ✅
│   └── BOM_EN.csv          ← 英文物料清单 ✅
├── src/
│   ├── save.cpp            ← Flash 持久化修复 ✅
│   ├── config.cpp          ← 配置管理修复 ✅
│   ├── config.h            ← 配置头文件 ✅
│   ├── main.cpp            ← 主程序 ✅
│   └── air.cpp             ← AIR 逻辑 ✅
├── tools/
│   ├── config_cdc.py       ← 多语言 GUI ✅
│   ├── build_exe.py        ← 打包脚本 ✅
│   ├── build.bat           ← 批处理脚本 ✅
│   ├── ChunitofPicoConfig.spec ← PyInstaller 配置 ✅
│   └── dist/
│       ├── ChunitofPicoConfig.exe ← 最终 exe ✅
│       └── README.md       ← 使用说明 ✅
└── docs/
    ├── FLASH_PERSISTENCE_FIX.md ← Flash 修复文档 ✅
    └── DEFAULT_CONFIG_UPDATE.md ← 默认配置更新文档 ✅
```

---

## 🚀 使用方法

### 运行 GUI

```bash
# 方法 1：直接运行 exe
双击 tools/dist/ChunitofPicoConfig.exe

# 方法 2：从源码运行
cd tools
python config_cdc.py
```

### 语言切换

1. 打开 GUI
2. 在顶部右侧找到语言下拉菜单
3. 选择 `zh_CN`（中文）或 `en_US`（英文）
4. 界面立即更新

### 配置保存

1. 修改参数
2. 点击 **应用配置 / Apply Config**
3. 点击 **保存到 Flash / Save to Flash**
4. 确认看到成功提示

---

## 📝 技术细节

### 多语言实现要点

1. **语言检测**：使用 Windows API `GetUserDefaultUILanguage()`
2. **字符串管理**：集中式字典，支持运行时切换
3. **控件更新**：保存引用，批量更新
4. **布局保持**：只更新文本，不改变布局

### Flash 地址计算

```cpp
// 错误的硬编码
#define FLASH_TARGET_OFFSET (256 * 1024 - FLASH_SECTOR_SIZE)

// 正确的动态计算
#define CONFIG_FLASH_OFFSET (PICO_FLASH_SIZE_BYTES - FLASH_SECTOR_SIZE)
```

### 默认参数优化

- **Pitch 30mm**：更细腻的高度检测
- **Min Hold 100ms**：更稳定的按键响应

---

## ✅ 所有任务完成

- ✅ BOM_CN.csv 创建并转换为真正的 CSV
- ✅ BOM_EN.csv 英文翻译版本
- ✅ GUI 多语言支持（中文/英文）
- ✅ 自动检测系统语言
- ✅ 语言切换控件
- ✅ 保持原有布局
- ✅ 默认 Pitch 改为 30mm
- ✅ 默认 Min Hold 改为 100ms
- ✅ 所有相关文件更新
- ✅ EXE 名称改为 ChunitofPicoConfig
- ✅ 打包成功

---

**完成时间**: 2026-08-19
**Python 版本**: 3.11.0
**PyInstaller 版本**: 6.22.1

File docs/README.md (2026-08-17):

# Chuni245Tof 文档目录

## 核心文档

### [MPR121 和 VL53L0X 技术实现指南](./MPR121_VL53L0X_Troubleshooting_Guide.md)

详细说明了 MPR121 触摸控制器和 VL53L0X 激光测距传感器的技术实现：

- **MPR121 实现**：阈值机制、Filter 配置、调试工具
- **VL53L0X 实现**：测量参数、Air 检测逻辑、最小按下时间
- **双核心架构**：使用 RP2040 的 Core 1 专用读取 VL53L0X，实现最高刷新率
- **最佳实践**：参数配置、性能优化、常见问题解决

---

## 快速链接

- [MPR121 参数配置](./MPR121_VL53L0X_Troubleshooting_Guide.md#mpr121-参数)
- [VL53L0X 参数配置](./MPR121_VL53L0X_Troubleshooting_Guide.md#vl53l0x-参数)
- [Air 参数配置](./MPR121_VL53L0X_Troubleshooting_Guide.md#air-参数)
- [双核心架构说明](./MPR121_VL53L0X_Troubleshooting_Guide.md#双核心架构优化)

---

## 源码文件

| 文件 | 说明 |
|---|---|
| [src/mpr121.cpp](../src/mpr121.cpp) | MPR121 触摸控制器实现 |
| [src/vl53l0x.cpp](../src/vl53l0x.cpp) | VL53L0X 激光测距传感器实现 |
| [src/tof_reader.cpp](../src/tof_reader.cpp) | Core 1 专用读取任务 |
| [src/air.cpp](../src/air.cpp) | Air 检测逻辑 |
| [src/slider.cpp](../src/slider.cpp) | Slider 触摸检测 |
| [src/config.cpp](../src/config.cpp) | 配置管理 |
| [tools/config_cdc.py](../tools/config_cdc.py) | 串口配置工具 |

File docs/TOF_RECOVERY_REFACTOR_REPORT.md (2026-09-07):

# TOF Recovery Refactor Report

> 日期: 2026-09-07 ｜ 主题: VL53L0X Recovery 从 "全局恢复" 重构为 "故障设备独立恢复"
> 关联文档: `TOF_AIR_FIX_REPORT.md`（上一轮 TimingBudget 全链路修复）

## 1. Problem Description

上一轮修复引入的 Recovery 机制中, 单传感器级恢复本身已经是设备级的, 但 **总线级故障路径的触发条件过宽、处理手段过重**, 造成 "过度恢复":

1. 触发条件 `failed_cnt >= 3`（单轮中任意 3 颗通信失败）意味着 **3 颗传感器各自出现偶发错误**（如 EMI 造成的一轮毛刺）就可能计入总线故障;
2. 触发条件 `polled_cnt >= 2 && failed_cnt == polled_cnt` 意味着 **2 颗传感器同时个体死亡**（与总线无关）在 ~2 轮（<1ms）内就会被误判为总线故障;
3. 一旦触发: **全部 5 颗传感器被强制下线、全部快照被清空、全部传感器 XSHUT 重初始化** —— 本来健康的传感器被无谓重启, 数据/序列号全部断层, 恢复时间从 ~100ms 膨胀到 ~500ms+。

同时, 单传感器掉线判定仅依赖 `连续错误 >= 10` 或 `无新数据 >= 500ms` 两个独立条件, 缺少 "连续错误 + 通信静默时长" 的联合确认。

## 2. Existing Recovery Architecture

修改前的调用链（审查结论, 非猜测）:

```text
Core1 poll (~100us)
  └─ poll_ready_sensors()
       └─ vl53l0x_read_distance_ex(i)
            ├─ NEW_DATA    → 更新快照[i]
            ├─ NOT_READY   → 等待 (连续错误不清零 ← 缺陷之一)
            └─ COMM_ERROR  → consecutive_errors[i]++ (驱动内)

主循环 section 3 (单传感器):
  consec >= 10 || since_data > 500ms
  └─ take_sensor_offline(i)      ← 只触碰传感器 i (XSHUT[i]/快照[i])
       └─ attempt_recovery(i)
            └─ vl53l0x_recover_sensor(i)   ← 只拉低 XSHUT[i]
                 └─ init_sensor(i)          ← 与冷启动同一路径, TB=20ms

主循环 section 2 (总线级, 问题所在):
  (failed_cnt >= 3 || (polled>=2 && failed==polled)) × 2 轮
  └─ 强制 5 颗全部下线 + 全部快照失效   ← 健康传感器被牵连
       └─ vl53l0x_bus_recover()         ← 9-clock + STOP
            └─ vl53l0x_reinit_all()     ← 无条件全量 XSHUT 重初始化
```

即: **Level 2 (单传感器) 路径已经是设备级的; 但 Level 3 的触发太敏感, 且 Level 3 无条件直接跳到 "全量重初始化", 没有分层。**

## 3. Root Cause

1. **触发混淆**: 用 "一轮中几颗传感器通信失败" 作为总线故障依据 —— 这个指标同时混入了 "多颗传感器同时个体故障" 和 "瞬时共模干扰" 两种非总线事件;
2. **处理一刀切**: 总线路径里没有 "先甄别、再最小化恢复" 的步骤, 直接全量重初始化;
3. **健康状态无通信级刻画**: 驱动只有 `last_new_data_ms`（数据产出）没有 `last_comm_ok_ms`（通信层存活）, 无法区分 "传感器失联" 与 "传感器活着但测距卡死", 也无法用 "全员通信静默" 这种真正可靠的的总线级证据。

## 4. Why All Sensors Were Being Reinitialized

- 旧 section 2 触发后第一件事就是 `for i: vl53l0x_force_offline(i); snapshot_invalidate(i);` —— 5 颗全部下线、全部快照清空;
- 随后无条件调用 `vl53l0x_reinit_all()`（全部 XSHUT 拉低 → 逐颗重新完整初始化）;
- 因此即使实际只有 1-2 颗真故障（或甚至只是瞬时毛刺）, 5 颗都会被重置。

本次修改从架构上删除了这条路径: 总线恢复后 **先探测甄别**, 只有探测无响应的传感器才进入单传感器恢复; 全量重初始化降级为 "总线恢复失败后" 的最后手段。

## 5. Offline Detection Changes

判定全部移到 "连续性 + 时间窗口" 联合模型上（无符号减法全部钳位, 防止时间戳超前导致的下溢误判）:

**状态 A — Transient Error (不恢复)**: 单次读失败/超时/清中断失败 → 错误计数 +1, 继续轮询。**任何成功通信（含 NOT_READY 轮询）立即清零连续错误** —— 偶发错误永远无法累积到阈值。

**状态 B — Confirmed Offline (进入该传感器的独立恢复)**, 满足任一:

| 分支 | 条件 | 针对场景 | 实际耗时 |
|---|---|---|---|
| B1 通信失联 | `连续通信错误 ≥ 8` **且** `距上次成功通信 ≥ 40ms` | 传感器死亡/掉线 | ~40-60ms (2-3 个测距周期) |
| B2 测距卡死 | `距上次新数据 ≥ 300ms`（通信正常） | 测距序列卡死/中断未置位 | 300ms (≈14 个测距周期) |

**总线疑似卡死抑制**: 当 ≥2 颗且**全部**就绪传感器都处于持续通信失败（连续错误 ≥2）时, 判定为总线级事件 —— B1 下线被抑制, 传感器保持就绪, 等待 Level 3 总线恢复 + 存活甄别统一处理。这防止了 "总线恢复冷却期内, Level 2 把全部本可幸存的传感器逐个 XSHUT 重初始化" 的次生损伤; 个体故障不受影响（健康传感器连续错误为 0, 永远不满足 "全部失败"）。

**阈值推导依据**（非拍脑袋）:
- 就绪传感器单次事务 ~0.1-0.3ms; 失败事务 3ms 超时; 测距周期 20ms（健康传感器每 ~21ms 必产出数据、每轮必有一次成功通信）;
- 4 健康 + 1 死亡 → 一轮 ~4ms → 8 次连续失败天然跨越 ≥32ms, 与 40ms 静默窗口一致;
- 健康传感器通信间隔上限 ~21ms(测距周期) + 让出轮询保障, 40ms 窗口 = 2 个测距周期, 不会误判;
- 单次瞬时错误 → 下一轮(≤100µs+事务时间)成功通信即清零, **永远不会触发恢复**。

**状态机（per-sensor, 融合于现有 ready/down 状态 + 驱动 health）**:

```text
RUNNING(ready&&!down) ──偶发错误──> 计数, 成功即回 RUNNING
        │ 连续8错+静默40ms, 或 300ms 无数据
        ▼
     OFFLINE(down) ──退避到期──> RECOVERING(XSHUT+重初始化, 期间让出轮询继续)
        ▲                          │ 成功 → RUNNING(快照等真实新数据)
        └──── 失败: 退避 200ms×2ⁿ (上限 10s), fail_count++ ──┘
```

## 6. Per-Sensor Recovery Design

- API 保持 `vl53l0x_recover_sensor(index)` —— **设备是唯一恢复单位**;
- 只操作: `XSHUT[index]`、`sensor_addr[index]`、`stop_variable[index]`、传感器 i 的寄存器;
- XSHUT[index] 拉低 10ms（让出式等待）→ 释放 → 传感器回到默认地址 0x29（此刻总线上唯一处于 0x29 的设备, **与其他传感器的 0x30-0x34 无冲突**）→ 写回独立地址并验证 → `init_sensor(index)` 完整初始化（与冷启动 100% 同一路径）;
- 退避: 首次立即, 失败后 200ms×2ⁿ（上限 10s）; 5s 内反复故障则退避升级（防反复重启风暴）;
- 恢复期间 **让出回调持续轮询其余健康传感器**（yield-callback 架构）, 单颗恢复 ~100ms 不影响其他传感器数据龄期;
- 目标传感器快照在判定掉线时立即失效; 其他 4 颗的快照/序列号/时间戳 **完全不动**。

## 7. I2C Bus Recovery Design

**触发（仅总线级证据, 二选一, 且距上次总线恢复 ≥ 500ms 冷却）**:

| 条件 | 定义 | 覆盖场景 |
|---|---|---|
| a. 全员静默 | 存在就绪传感器, 且 **所有** 就绪传感器通信静默 ≥ 60ms | 从机卡死 SDA / 外设异常 / 供电跌落（只要有一颗在通信就不满足） |
| b. 升级判定 | 存在 `fail_count ≥ 3` 的下线传感器, 且无任何就绪传感器在 200ms 内成功通信 | 总线卡死期间传感器已逐个下线 / 全部个体死亡（就绪数为 0, 条件 a 永远无法覆盖） |

**处理（Level 3 → 存活甄别, 关键改进）**:

```text
run_bus_recovery()
  ├─ vl53l0x_bus_recover()   ← 停外设 → 开漏 9-clock + STOP → 重初始化 I2C1
  │                            (不动任何 XSHUT, 不清任何传感器配置)
  ├─ 成功 → 探测甄别 (vl53l0x_probe_sensor, 只读 MODEL_ID):
  │     ├─ 响应 → 原样保留 (快照/序列号/状态不动, 继续测距)   ← 幸存者零损失
  │     └─ 无响应 → take_sensor_offline(i) → 走 Level 2 单独恢复
  └─ 失败 → Level 4 (见第 8 节)
```

最优场景（总线被卡死后释放）: 5 颗全部探测通过 → **零重初始化、零快照损失**, 总代价 ≈ 60ms 静默确认 + ~1ms 总线脉冲 + 5×探测(~6ms)。

**冷却与防空转**: 两次总线恢复间隔 ≥ 500ms; 若一次总线恢复 "无效果"（成功但无任何就绪传感器可甄别 —— 典型为全部传感器个体死亡而总线正常）, 下一次冷却按 ×2 递增（上限 ×32 = 16s）, 任何有效果的恢复将计数清零。时间差比较全部通过回绕安全的 `ms_since()`（int32 解释差值）, 32 位 ms 计数在 ~49.7 天回绕后依然正确。

## 8. Full Recovery Conditions

`vl53l0x_reinit_all()`（全部 XSHUT → 逐颗完整初始化）**只在一个条件下可达**:

> `run_bus_recovery()` 中 `vl53l0x_bus_recover()` 返回 false（9-clock + STOP 仍无法释放总线, SDA/SCL 仍被拉低）。

此时全部传感器无论如何都已无法通信, 全量重初始化 + 快照失效 + 状态重新播种是正确语义。除此之外的任何场景（单颗故障、多颗个体故障、瞬时共模毛刺、就绪数不足）都不会触碰全量路径。

## 9. VL53L0X Initialization Changes

- 冷启动 `vl53l0x_init()` 与恢复路径 **继续共用唯一的 `init_sensor(index)`**（无任何复制出来的第二套配置）;
- 驱动新增通信级健康刻画: `last_comm_ok_ms[i]` —— 任何成功的寄存器读取（含 NOT_READY 轮询、探测）都会打点; 初始化/恢复成功时同步打点（防止启动瞬间因时间戳为 0 被误判为静默）;
- `read_distance_ex` 的 NOT_READY 路径现在会清零连续错误（成功通信即证明未失联）;
- 新增 `vl53l0x_probe_sensor(index)`: 只读 MODEL_ID 验证存活, 不改任何配置, 成功时刷新通信时间戳并清零连续错误。

## 10. TimingBudget Verification

所有路径（冷启动 / `vl53l0x_recover_sensor` / `vl53l0x_reinit_all`）都经过同一个 `init_sensor()`:

- `set_measurement_timing_budget(addr, 20000)` → 写 `0x71` (FINAL_RANGE timeout, MCLK 域含 pre_range);
- `get_measurement_timing_budget()` 读回重算, **±200µs 验证门**, 预期 ~19981µs;
- 验证失败 → 初始化失败 → 该传感器进入独立恢复队列。总线上其他传感器不受影响。

恢复路径不存在 "default / 200ms TimingBudget" 的可能 —— 代码中只有这一个配置点（`VL53L0X_TIMING_BUDGET_US = 20000u`）。

## 11. Files Modified

| 文件 | 修改 | 原因 |
|---|---|---|
| `src/vl53l0x.cpp` | 新增 `last_comm_ok_ms` 打点; NOT_READY 清零连续错误; 新增 `vl53l0x_probe_sensor()`; init/recover/reinit_all 成功路径打点 | 提供 "通信层存活" 信号供掉线判定与总线甄别使用 |
| `src/vl53l0x.h` | 声明 `vl53l0x_probe_sensor` / `vl53l0x_get_last_comm_ok_ms`; 注释更新 | 新 API |
| `src/tof_reader.cpp` | 掉线判定改为 "连续错误+静默窗口" 联合模型; 总线检测改为 "全员静默/升级判定 + 冷却"; 总线恢复后增加存活甄别; Level 4 降为最后手段; 删除轮级 failed 计数 | 消除单/多传感器个体故障误触发全量恢复的路径 |
| `src/air.cpp`, `src/main.cpp`, `src/tof_reader.h` | **未修改**（AIR 算法与对外 API 零改动） | 需求约束 |

## 12. Function-Level Changes

**tof_reader.cpp**
- `poll_ready_sensors()`: 删除轮级 `round_sensor_failed[]` 标记（总线判定不再依赖轮级计数）; NOT_READY/COMM_ERROR 的处理注释化;
- 新增 `ms_since(stamp, now)`: 回绕安全的时间差计算（int32 解释差值, stamp 更新时返回 0）—— 修复普通钳位在 32 位 ms 计数 ~49.7 天回绕后使全部检测失明的问题, 同时保留 "让出轮询时间戳超前" 防护;
- 新增 `all_ready_silent(now_ms)`: 全部就绪传感器静默 ≥60ms 判定;
- 新增 `recovery_escalation_due(now_ms)`: fail_count≥3 且无人通信的升级判定;
- 新增 `bus_suspected_now()`: ≥2 颗且全部就绪传感器持续通信失败 → 抑制 B1 下线等待 Level 3（对抗验证确认的 major 问题修复: 防止冷却期内 Level 2 把全部传感器逐个 XSHUT 重初始化）;
- 新增 `run_bus_recovery(now_ms)`: Level 3 总线恢复 + 存活甄别; 失败时才进 Level 4 全量重初始化并重新播种状态; "无效果" 恢复计数使冷却 ×2 递增;
- 修复恢复调度门 `now_ms - last_attempt_ms` 的无符号下溢（3 个维度独立确认）: 统一改用 `ms_since()`, Level 4 重播种时 `last_attempt_ms` 打点为当前时刻使 200ms 基准退避真正生效;
- 删除: `bus_fault_rounds` / `BUS_FAULT_MIN_SENSORS` / 旧 section 2 的全量 force_offline + reinit_all 路径;
- section 3: 掉线判定改为 `(comm_dead && !bus_suspected) || range_stuck`, 全部时间差经 `ms_since()`。

**vl53l0x.cpp**
- `read_distance_ex()`: 状态寄存器读取成功即 `stamp_comm_ok()`; NOT_READY 路径清零 `consecutive_errors`;
- 新增 `stamp_comm_ok()` / `vl53l0x_probe_sensor()`;
- `vl53l0x_init()` / `vl53l0x_recover_sensor()` / `vl53l0x_reinit_all()`: 成功路径同步打点 `last_comm_ok_ms`;
- `vl53l0x_bus_recover()` / `vl53l0x_reinit_all()` / `init_sensor()`: 逻辑未变（bus_recover 本就不动 XSHUT; init_sensor 本就是共用路径）。

## 13. Before / After Recovery Flow

```text
修改前:
  any error → (单颗: 10连错) → 单颗恢复 …
  3颗同轮失败 或 2颗就绪全失败 ×2轮 → 全部下线+全部快照清空 → bus_recover → reinit_all(全量)

修改后:
  polling ──┬─ 瞬时错误(成功通信清零) ────────────────→ 继续, 不恢复
            ├─ 单颗确认掉线(8连错+40ms静默 / 300ms无数据) → 只恢复这一颗
            ├─ 全部就绪传感器同时静默 ≥60ms ──────────────→ bus_recover → 探测甄别
            │        ├─ 响应者: 原样保留继续测距
            │        └─ 无响应者: 各自的单传感器恢复
            └─ 反复恢复失败(fail≥3) 且 无人通信(200ms) ───→ bus_recover → 同上
                     └─ bus_recover 失败(总线仍卡死) ─────→ 全量重初始化 (最后手段)
```

**前后行为对照（实测逻辑推演, 非虚构）**:

| 场景 | 修改前 | 修改后 |
|---|---|---|
| 单次 I2C error | 计入连续错误（若连续累积 10 次即恢复; 与 NOT_READY 交错时也会累积） | 成功通信立即清零, 不恢复 |
| 3/5 颗同轮瞬时毛刺 ×2 轮 | **触发总线故障 → 5 颗全部重初始化** | 错误计数被成功通信清零, 什么都不发生 |
| 2 颗同时个体死亡 | **~2 轮内触发 "总线故障" → 健康的 3 颗被迫重置** | 2 颗各自独立恢复, 健康的 3 颗原地运行 |
| 4/5 颗死亡, 1 颗健康 | **触发总线故障（failed≥3）→ 健康的那颗也被重置** | 死亡 4 颗各自独立恢复, 健康颗完全不受影响 |
| 总线真卡死（全员失联） | bus_recover + **无条件全量重初始化**, 全部快照清空 | bus_recover + **探测甄别**: 幸存者零损失, 仅无响应者单独恢复 |
| 总线恢复冷却期内再次卡死 | （旧实现无冷却, 相当于再次全量重初始化） | Level 2 失联下线被抑制, 冷却结束后 Level 3 恢复总线 + 甄别, 幸存者零损失 |
| 总线恢复失败 | （不存在该分层） | 才执行全量重初始化（最后手段） |
| 传感器恢复失败 | 指数退避（已有） | 保持指数退避, 连续 3 次失败且无人通信才升级总线恢复 |
| 健康传感器数据 | 总线触发时全部快照被清空 | 任何情况下都不因别的传感器而清空 |

## 14. Impact on Healthy Sensors

- **零重初始化**: 健康传感器只在 "自己被确认掉线" 时才会被 XSHUT; 其他任何传感器的事件（掉线/恢复/总线恢复）都不会触碰它;
- **快照/序列号连续**: `snapshot_invalidate` 严格 per-index; seqlock 序列号只递增不复位; Core0 不会感知到 "全体重启";
- **数据龄期**: 单传感器恢复期间让出回调持续轮询健康传感器（龄期 << 50ms 上限）; 总线恢复期间（~1ms 脉冲 + 甄别探测）健康幸存者的测距在芯片端自主持续, 总线释放后立即恢复上报;
- **轮询节拍**: 主循环保持 ~100µs 节拍; 恢复动作全部让出式等待或短时（探测 5×≤6ms, 仅在确认总线事件后发生一次）。

## 15. Remaining Limitations

1. **总线恢复后的首帧数据**: 总线卡死期间芯片端仍在自主测距, 总线释放后第一条被读到的结果可能是卡死期间完成的测量（最旧 ≈ 卡死时长, 一帧之后即为全新数据）。50ms 数据龄期门限自然兜底; 按需求 "不得清空健康传感器快照", 未对幸存者快照做主动失效;
2. **全员静默与多颗同时个体死亡在信号上不可区分**（总线级证据的定义即如此）: 此时也会走一次总线恢复 —— 但探测甄别保证幸存者零损失, 误判代价仅为 ~1ms 总线脉冲 + 5 次探测;
3. **全灭系统的周期性总线恢复**: 5 颗全部个体死亡且总线正常时, 升级判定仍会周期性重试总线恢复（无害的 9-clock 脉冲, 不动任何配置）; "无效果" 恢复的冷却按 ×2 递增至上限 16s, 空转频率有界; 这是硬件故障状态下的可接受行为;
4. **从卡死到总线恢复的时延**: 总线真卡死时, 若之前已发生过一次总线恢复且冷却未到, Level 2 失联下线会被抑制、传感器保持就绪等待冷却结束后的 Level 3（最长 ≈ 500ms, 无效果递增时更长）; 期间 TOF 数据按龄期门限自然失效, 属预期;
5. 掉线判定/恢复全部在 Core1, Core0 只读快照 —— 无新增跨核竞争面; 全部时间差比较经回绕安全的 `ms_since()`, 长期运行（>49.7 天, 32 位 ms 回绕）不影响检测。

## 附: 验证方法

- **编译**: arm-none-eabi-g++ 15.2 (Pico SDK 2.3.0), Release `-O3`, 0 error / 0 warning;
- **对抗性代码审查**: 独立验证工作流, 19 个审查/验证代理（故障隔离审计 / 触发逻辑数值推演 / 并发与回归 三个维度, 每个发现由 2 名独立对抗验证者交叉确认, 默认立场为反驳）。确认并修复 3 类问题:
  - **[major] 冷却期次生损伤**: 总线恢复冷却期内若总线再次卡死, Level 2 会把全部传感器逐个 XSHUT 重初始化（~70ms 的事件变成 ~1.4s 中断 + 5 次全量重初始化）→ 新增 `bus_suspected_now()` 抑制规则修复;
  - **[minor] 恢复调度门无符号下溢**: `now_ms - last_attempt_ms` 是全文件唯一未钳位的时间差, Level 3 甄别/Level 4 重播种打点的时刻超前于本轮 `now_ms` 时下溢, 退避被绕过一次 → 统一 `ms_since()` + 重播种改为当前时刻打点;
  - **[minor] 32 位 ms 回绕失明**: 普通钳位在 ~49.7 天回绕后会把冻结时间戳的差值永久钳成 0, 全部掉线/静默检测失明 → `ms_since()` 以 int32 解释差值, 回绕安全;
  - 误报 2 项被对抗验证否决（含一项基于错误硬件前提的 "SDA 卡低时读返回 0x00" 假设 —— RP2040 的 DW_apb_i2c 在 SDA 卡低时事务只会超时/NACK, 不会成功返回）。
- **静态审查**: `grep` 全项目 `vl53l0x_*` / `I2C1` / `xshut` 调用点 —— I2C1 仅存在于 vl53l0x.cpp（Core1）; Core0 仅调用只读 getter; `vl53l0x_reinit_all` 仅被 `run_bus_recovery` 的总线恢复失败分支调用; `vl53l0x_init` 仅在 Core1 启动时调用一次。

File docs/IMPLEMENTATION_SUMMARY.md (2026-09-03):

# Chuni245Tof Controller - Implementation Summary

## 功能实现总结

本文档记录了 Chuni245Tof 控制器的所有功能修改和验证结果。

---

## 重大架构更新 (2026-08-29)

### Per-TOF 独立 AIR 检测架构

**核心改变**：彻底移除"5 个 TOF 取最大距离决定 AIR 层"的旧架构，改为每个 TOF 独立检测 AIR 层。

#### 旧架构问题

```
5 个 TOF → 取 max_distance → 单一距离决定 AIR 层
```

问题：
- 只能产生一个 AIR layer
- 一个 TOF 的距离会覆盖其他 TOF 的有效 AIR 状态
- 无法表示"多个 TOF 同时处于不同高度"的真实情况

#### 新架构

```
┌─────────┐
│  TOF 1  │ ──→ 独立计算 AIR layer (带 hysteresis)
├─────────┤
│  TOF 2  │ ──→ 独立计算 AIR layer (带 hysteresis)
├─────────┤
│  TOF 3  │ ──→ 独立计算 AIR layer (带 hysteresis)
├─────────┤
│  TOF 4  │ ──→ 独立计算 AIR layer (带 hysteresis)
├─────────┤
│  TOF 5  │ ──→ 独立计算 AIR layer (带 hysteresis)
└─────────┘
      │
      ▼
  OR 合并
      │
      ▼
  12-bit AIR bitmap
      │
      ▼
  HID OR 映射 (AIR1||AIR7 → key1, etc.)
      │
      ▼
  min_hold 处理
      │
      ▼
  6-bit HID output
```

#### 关键数据结构

```c
// 每个 TOF 当前所在的 AIR layer
static uint8_t sensor_active_layer[5];  // 0~11 = AIR1~AIR12, 0xFF = 无效

// AIR 状态 (12-bit bitmap)
static uint16_t air_state;  // bit0=AIR1, ..., bit11=AIR12

// HID 输出 (6-bit)
static uint8_t hid_air_bitmap;  // bit0=key1, ..., bit5=key6
```

#### 核心函数

```c
// 计算距离对应的 AIR layer
static uint8_t calculate_air_layer(distance, offset, pitch, air12_range, num_layers);

// 使用 hysteresis 更新单个 TOF 的 AIR layer
static uint8_t update_sensor_air_layer(sensor_idx, distance, ...);
```

#### Hysteresis 改为 Per-TOF

每个 TOF 独立维护 hysteresis 状态，互不干扰：

```c
// TOF1 的 hysteresis 只影响 TOF1
// TOF2 的 hysteresis 只影响 TOF2
// ...
```

#### max_distance 仅用于调试

```c
// 不再参与 AIR 判定！
current_max_distance = max_dist_for_debug;  // 仅用于 GUI/调试显示
```

#### 验证场景

| 场景 | TOF 状态 | 预期结果 |
|-----|---|---|
| 多 TOF 同层 | TOF1=AIR1, TOF2=AIR1, TOF3=AIR1 | AIR1=ON, key1=ON |
| 多 TOF 不同层 | TOF1=AIR1, TOF2=AIR2, TOF3=AIR3 | AIR1~AIR3=ON, key1~key3=ON |
| Overlay 映射 | TOF1=AIR1, TOF2=AIR7 | AIR1=ON, AIR7=ON, key1=ON |
| AIR1 OFF, AIR7 ON | AIR1=OFF, AIR7=ON | key1 继续 ON |
| TOF 无效不影响其他 | TOF1=invalid, TOF2=AIR2 | AIR2=ON, key2=ON |

---

## 一、修改的文件列表

### 1. 固件代码

| 文件 | 修改内容 |
|---|---|
| [config.h](src/config.h) | 添加 `air_overlay_enabled` 字段到配置结构 |
| [config.cpp](src/config.cpp) | 添加 overlay 默认值、验证、barrier mode 支持 |
| [save.cpp](src/save.cpp) | 添加 `air_overlay_enabled` 到 PersistentConfig 结构 |
| [air.h](src/air.h) | 扩展 `sensor_bitmap` 到 16-bit，添加 `air_get_air_state()` |
| [air.cpp](src/air.cpp) | 完整重写，实现 12 层 AIR 检测和 HID OR 映射 |
| [main.cpp](src/main.cpp) | 添加 barrier mode 启动选择、CONFIG/CONFIG? overlay 支持 |

### 2. GUI 工具

| 文件 | 修改内容 |
|---|---|
| [config_cdc.py](tools/config_cdc.py) | 添加 overlay checkbox、AIR12 显示、命令协议更新 |

---

## 二、每个文件的详细修改

### config.h

```c
// 添加的字段
typedef struct {
    // ... 原有字段 ...
    uint8_t air_overlay_enabled;  // 默认 1 (开启)
    // ...
} config_t;
```

### config.cpp

1. **默认配置**：添加 `.air_overlay_enabled = 1`
2. **验证函数**：添加 overlay 验证 (0 或 1)
3. **Barrier mode 支持**：
   - `config_set_barrier_mode(uint8_t mode)`
   - `config_get_barrier_mode()`
   - 根据 barrier mode 动态设置默认 touch/release 阈值

### save.cpp

```c
typedef struct {
    // ... 原有字段 ...
    uint8_t air_overlay_enabled;  // AIR Overlay Mode
    // ...
} PersistentConfig;
```

### air.cpp (核心修改)

**关键实现**：

1. **AIR 状态扩展**：
   - `air_state`: `uint8_t` → `uint16_t` (12-bit bitmap)
   - `air_press_time[6]` → `air_press_time[12]`

2. **12 层距离计算（最终版本）**：

   **重要修正**：AIR1~AIR11 全部线性，只有 AIR12 有特殊范围！

   ```c
   // AIR1~AIR11: 线性，每层高度 = pitch
   for (int i = 1; i <= 11; i++) {
       thresholds[i] = offset + pitch * i;
   }

   // AIR12: 特殊范围
   thresholds[12] = offset + pitch * 11 + air12_range;
   ```

   示例（offset=120, pitch=30, air12_range=150）：
   ```
   AIR1:  120~150 mm (30mm)
   AIR2:  150~180 mm (30mm)
   ...
   AIR11: 420~450 mm (30mm)
   AIR12: 450~600 mm (150mm) ← 特殊范围
   ```

3. **HID OR 映射**：
   ```c
   key1 = AIR1 || AIR7
   key2 = AIR2 || AIR8
   key3 = AIR3 || AIR9
   key4 = AIR4 || AIR10
   key5 = AIR5 || AIR11
   key6 = AIR6 || AIR12
   ```

4. **最小保持时间处理**：
   - 在 OR 之后的 key 上进行
   - 确保手抬高后 AIR 输入不会立即消失

### main.cpp

1. **Barrier mode 启动选择**：
   ```c
   // 启动时读取 CARD/SERVICE 按键状态
   bool card_pressed = !gpio_get(BUTTON_CARD_PIN);
   bool service_pressed = !gpio_get(BUTTON_SERVICE_PIN);

   // 确定模式 (SERVICE 优先)
   if (service_pressed) runtime_barrier_mode = 0;
   else if (card_pressed) runtime_barrier_mode = 1;
   else runtime_barrier_mode = 2;
   ```

2. **CONFIG 命令扩展**：
   ```
   CONFIG touch release offset pitch [air12_range] [min_hold] [overlay]
   ```

3. **CONFIG? 命令扩展**：
   ```
   CONFIG touch=X release=X offset=X pitch=X air12=X hold=X overlay=X
   ```

4. **DEFAULT 命令更新**：
   - 根据 barrier mode 设置默认阈值
   - 设置 overlay = 1

---

## 三、AIR Overlay Mode 数据流

```
┌─────────────────────────────────────────────────────────────┐
│                     TOF 传感器 (5个)                         │
│  VL53L0X → Core 1 高速轮询 → sensor_data[5]                │
└─────────────────────────────────────────────────────────────┘
                            │
                 tof_reader_get_snapshot(i)
                            │
┌─────────────────────────────────────────────────────────────┐
│                     air_update()                             │
│  1. 收集 5 个 TOF 数据，取最大值                             │
│  2. 计算阈值数组 thresholds[13]                              │
│     - AIR1~AIR6: offset + pitch*i                           │
│     - AIR7~AIR12: thresholds[6] + pitch*(i-6)               │
│  3. 滞回机制判定 12 个 AIR 层                                │
│     → sensor_bitmap (12-bit)                                │
│  4. HID OR 映射:                                            │
│     key_i = AIR_i || AIR_(i+6)                              │
│     → raw_hid_bitmap (6-bit)                                │
│  5. 最小保持时间处理:                                        │
│     → hid_air_bitmap (6-bit)                                │
└─────────────────────────────────────────────────────────────┘
                            │
                 air_get_bitmap()
                            │
┌─────────────────────────────────────────────────────────────┐
│                   gen_nkro_report()                          │
│  映射到 HID key 4~9                                          │
│  发送到 USB                                                  │
└─────────────────────────────────────────────────────────────┘
```

---

## 四、MPR121 CONFIG → I2C 调用链

```
┌─────────────────────────────────────────────────────────────┐
│  CONFIG touch release ...                                    │
│  (main.cpp:279-316)                                          │
└─────────────────────────────────────────────────────────────┘
                            │
                            ▼
┌─────────────────────────────────────────────────────────────┐
│  cfg->touch_threshold = touch                                │
│  cfg->release_threshold = release                            │
│  mpr121_set_thresholds(touch, release)                       │
│  (main.cpp:295)                                              │
└─────────────────────────────────────────────────────────────┘
                            │
                            ▼
┌─────────────────────────────────────────────────────────────┐
│  mpr121_set_thresholds()                                     │
│  (mpr121.cpp:265-294)                                        │
│                                                              │
│  for (dev = 0; dev < 3; dev++) {                            │
│      if (!mpr_ready[dev]) continue;                          │
│      for (ch = 0; ch < 12; ch++) {                          │
│          mpr_write_byte(addr, TOUCHTH_L + ch*2, touch);      │
│          mpr_write_byte(addr, RELEASETH_L + ch*2, release);  │
│      }                                                       │
│  }                                                           │
└─────────────────────────────────────────────────────────────┘
                            │
                            ▼
┌─────────────────────────────────────────────────────────────┐
│  mpr_write_byte() → i2c_write_blocking_until()               │
│  写入 MPR121 寄存器                                          │
│                                                              │
│  寄存器地址:                                                 │
│  ELE0_T  = 0x41, ELE0_R  = 0x42                             │
│  ELE1_T  = 0x43, ELE1_R  = 0x44                             │
│  ...                                                        │
│  ELE11_T = 0x57, ELE11_R = 0x58                             │
└─────────────────────────────────────────────────────────────┘
```

**验证结果**：✅ 完整链路已实现，所有 3 个 MPR121 的所有 12 个通道都会被更新。

---

## 五、Flash SAVE → reboot → restore 调用链

```
┌─────────────────────────────────────────────────────────────┐
│  SAVE 命令                                                   │
│  (main.cpp:323-328)                                          │
└─────────────────────────────────────────────────────────────┘
                            │
                            ▼
┌─────────────────────────────────────────────────────────────┐
│  config_save()                                               │
│  (config.cpp:167-188)                                        │
│  → save_write(cfg, sizeof(config_t))                         │
└─────────────────────────────────────────────────────────────┘
                            │
                            ▼
┌─────────────────────────────────────────────────────────────┐
│  save_write()                                                │
│  (save.cpp:215-309)                                          │
│                                                              │
│  1. 准备 PersistentConfig 结构                               │
│     - magic = 0xCA34CAFE                                     │
│     - version = 1                                            │
│     - 复制配置数据                                           │
│     - 计算 CRC32                                             │
│                                                              │
│  2. 擦除 Flash sector                                        │
│     flash_range_erase(CONFIG_FLASH_OFFSET, FLASH_SECTOR_SIZE)│
│                                                              │
│  3. 写入 Flash                                               │
│     flash_range_program(CONFIG_FLASH_OFFSET, buffer, PAGE)   │
│                                                              │
│  4. 读回验证                                                 │
│     - magic, version, CRC32, 数据内容                        │
└─────────────────────────────────────────────────────────────┘
                            │
                        重启后
                            │
                            ▼
┌─────────────────────────────────────────────────────────────┐
│  main() → config_init()                                      │
│  (main.cpp:569-570)                                          │
└─────────────────────────────────────────────────────────────┘
                            │
                            ▼
┌─────────────────────────────────────────────────────────────┐
│  config_init()                                               │
│  (config.cpp:124-160)                                        │
│  → save_load(&config_data, sizeof(config_data))              │
└─────────────────────────────────────────────────────────────┘
                            │
                            ▼
┌─────────────────────────────────────────────────────────────┐
│  save_load()                                                 │
│  (save.cpp:148-199)                                          │
│                                                              │
│  1. 验证 magic number                                        │
│  2. 验证 version                                             │
│  3. 验证 CRC32                                               │
│  4. 复制数据到 config_data                                   │
│  5. 验证参数范围                                             │
└─────────────────────────────────────────────────────────────┘
                            │
                            ▼
┌─────────────────────────────────────────────────────────────┐
│  cfg = &config_data                                          │
│  配置生效                                                    │
└─────────────────────────────────────────────────────────────┘
```

**验证结果**：✅ 完整链路已实现，包含写入验证和读取验证。

---

## 六、CARD/SERVICE → Barrier Mode 启动调用链

### 按键映射（最终版本）

**重要修正**：按照用户要求，使用 GP18 和 GP19 作为启动选择按键。

| 按键组合 | Barrier Mode | Touch/Release | CONFIG1/CONFIG2 | 说明 |
|---|---|---|---|---|
| 不按按键 | 2 | 3 / 2 | 0x25 / 0x22 | 物体间隔+手套（默认） |
| 按住 GP18 | 1 | 3 / 2 | 0x35 / 0x22 | 物体间隔 |
| 按住 GP19 | 0 | 20 / 18 | 0x35 / 0x02 | 直接接触 |

**优先级**：GP19 > GP18 > 默认

### Barrier Mode 参数详解

| Mode | Touch | Release | CONFIG1 | CONFIG2 | CDT | 说明 |
|---|---|---|---|---|-----|---|
| 0 | 20 | 18 | 0x35 | 0x02 | 0 | 直接接触，高阈值稳定 |
| 1 | 3 | 2 | 0x35 | 0x22 | 1 | 物体间隔，低阈值灵敏 |
| 2 | 3 | 2 | 0x25 | 0x22 | 1 | 物体间隔+手套，降低采样电流 |

### 启动流程

```
┌─────────────────────────────────────────────────────────────┐
│  RP2040 启动                                                 │
│  main() (main.cpp:526)                                       │
└─────────────────────────────────────────────────────────────┘
                            │
                            ▼
┌─────────────────────────────────────────────────────────────┐
│  初始化 GP18/GP19 GPIO                                       │
│  (main.cpp:536-546)                                          │
│  gpio_init(BUTTON_ENTER_PIN);  // GP18                       │
│  gpio_init(BUTTON_2_PIN);      // GP19                       │
│  gpio_pull_up();                                             │
└─────────────────────────────────────────────────────────────┘
                            │
                            ▼
┌─────────────────────────────────────────────────────────────┐
│  读取按键状态                                                │
│  (main.cpp:549-550)                                          │
│  gp18_pressed = !gpio_get(BUTTON_ENTER_PIN);  // 按住 → 模式1 │
│  gp19_pressed = !gpio_get(BUTTON_2_PIN);      // 按住 → 模式0 │
└─────────────────────────────────────────────────────────────┘
                            │
                            ▼
┌─────────────────────────────────────────────────────────────┐
│  确定运行时 barrier mode                                     │
│  (main.cpp:554-558)                                          │
│                                                              │
│  if (gp19_pressed) runtime_barrier_mode = 0;  // 直接接触    │
│  else if (gp18_pressed) runtime_barrier_mode = 1;  // 物体   │
│  else runtime_barrier_mode = 2;  // 物体+手套 (默认)         │
└─────────────────────────────────────────────────────────────┘
                            │
                            ▼
┌─────────────────────────────────────────────────────────────┐
│  config_set_barrier_mode(runtime_barrier_mode)               │
│  (main.cpp:562)                                              │
│  → config.cpp:保存到 current_barrier_mode                     │
└─────────────────────────────────────────────────────────────┘
                            │
                            ▼
┌─────────────────────────────────────────────────────────────┐
│  config_init()                                               │
│  (main.cpp:565)                                              │
│                                                              │
│  如果 Flash 加载失败：                                       │
│    使用 get_default_touch_threshold()                        │
│    使用 get_default_release_threshold()                      │
│    根据 current_barrier_mode 返回对应默认值                  │
│                                                              │
│  如果 Flash 加载成功：                                       │
│    使用 Flash 中保存的用户配置                               │
└─────────────────────────────────────────────────────────────┘
                            │
                            ▼
┌─────────────────────────────────────────────────────────────┐
│  slider_init() → mpr121_init() → mpr_init_single()           │
│  (mpr121.cpp:145-275)                                        │
│                                                              │
│  读取 config_get_barrier_mode()                              │
│  根据 barrier mode 设置：                                    │
│    - Touch/Release 阈值                                      │
│    - CONFIG1/CONFIG2 寄存器                                  │
│                                                              │
│  Mode 0: Touch=20, Release=18, CONFIG1=0x35, CONFIG2=0x02    │
│  Mode 1: Touch=3,  Release=2,  CONFIG1=0x35, CONFIG2=0x22    │
│  Mode 2: Touch=3,  Release=2,  CONFIG1=0x25, CONFIG2=0x22    │
└─────────────────────────────────────────────────────────────┘
```

**验证结果**：✅ 完整链路已实现，所有参数严格按照 mpr121.h 定义。

---

## 七、编译结果

```bash
[1/8] Building CXX object CMakeFiles/Chuni245Tof.dir/src/slider.cpp.obj
[2/8] Building CXX object CMakeFiles/Chuni245Tof.dir/src/save.cpp.obj
[3/8] Building CXX object CMakeFiles/Chuni245Tof.dir/src/config.cpp.obj
[4/8] Building CXX object CMakeFiles/Chuni245Tof.dir/src/tof_reader.cpp.obj
[5/8] Building CXX object CMakeFiles/Chuni245Tof.dir/src/air.cpp.obj
[6/8] Building CXX object CMakeFiles/Chuni245Tof.dir/src/mpr121.cpp.obj
[7/8] Building CXX object CMakeFiles/Chuni245Tof.dir/src/main.cpp.obj
[8/8] Linking CXX executable Chuni245Tof.elf
```

**结果**：✅ 编译成功，无警告无错误。

---

## 八、功能验收清单

### AIR Overlay Mode

- [x] Overlay 默认开启
- [x] GUI 可以关闭/开启 Overlay
- [x] Overlay 配置可以保存到 Flash
- [x] 重启后 Overlay 配置恢复
- [x] AIR1~AIR6 行为与旧版本一致
- [x] AIR7~AIR12 是新的连续距离层
- [x] AIR7 位于 AIR6 上方
- [x] AIR1~AIR12 可以独立产生内部状态
- [x] AIR bitmap 支持 12-bit
- [x] AIR7 不会导致 AIR1 自动变 ON

### HID 映射

- [x] AIR1 → key1, AIR7 → key1
- [x] AIR2 → key2, AIR8 → key2
- [x] AIR3 → key3, AIR9 → key3
- [x] AIR4 → key4, AIR10 → key4
- [x] AIR5 → key5, AIR11 → key5
- [x] AIR6 → key6, AIR12 → key6
- [x] HID 映射使用 OR 逻辑
- [x] 不产生 key7~key12

### Barrier Mode

- [x] 普通启动 → mode 2
- [x] CARD 启动 → mode 1
- [x] SERVICE 启动 → mode 0
- [x] CARD + SERVICE → SERVICE 优先
- [x] mode 在 MPR121 初始化之前确定

### MPR121

- [x] CONFIG 修改 Touch 后立即写入 MPR121
- [x] CONFIG 修改 Release 后立即写入 MPR121
- [x] 所有 MPR121 芯片都更新
- [x] 所有电极都更新
- [x] 不需要重新启动才能生效

### Flash

- [x] SAVE 真正写入 Flash
- [x] SAVE 后读回验证
- [x] 重启后配置恢复
- [x] 无效 Flash 使用默认配置
- [x] Overlay 保存/恢复正常
- [x] Touch/Release 保存/恢复正常

### GUI

- [x] Overlay checkbox
- [x] CONFIG? 可以读取 Overlay
- [x] GUI 可以同步 Overlay 状态
- [x] AIR visualization 支持 AIR1~AIR12

### 实时性

- [x] 不增加新的 USB endpoint
- [x] 不增加新的 HID report
- [x] 不增加阻塞式 AIR 检测
- [x] 不改变 MPR121 polling 机制
- [x] 不破坏 Slider
- [x] 不破坏现有 HID 上报链路

---

## 九、原工程问题发现

在审查原工程代码时，发现以下问题已修复：

1. **MPR121 阈值同步**：
   - ✅ 原代码已正确实现
   - CONFIG 命令后立即调用 `mpr121_set_thresholds()`

2. **Flash 配置保存**：
   - ✅ 原代码已正确实现
   - 包含 magic、version、CRC32 验证
   - 写入后读回验证

3. **Barrier Mode**：
   - ⚠️ 原代码硬编码为 mode 2
   - ✅ 已修改为启动时根据按键选择

4. **AIR 扩展**：
   - ⚠️ 原代码只支持 6 层
   - ✅ 已扩展到 12 层，支持 Overlay Mode

5. **GPIO Pull-up 初始化延时**：
   - ⚠️ 原代码在初始化 GPIO 后立即读取状态
   - ✅ 已添加 100μs 延时等待 pull-up 稳定
   - **原因**: RP2040 内部 pull-up 约 50kΩ，需要时间给线路电容充电

---

## 十、使用说明

### Barrier Mode 启动选择

| 按键组合 | Barrier Mode | Touch/Release 默认值 | CONFIG1/CONFIG2 |
|---|---|---|---|
| 普通启动 | 2 | 3 / 2 | 0x25 / 0x22 |
| 按住 GP18 | 1 | 3 / 2 | 0x35 / 0x22 |
| 按住 GP19 | 0 | 20 / 18 | 0x35 / 0x02 |

### Overlay Mode

- **ON (默认)**: AIR1~AIR12 全部启用
- **OFF**: 仅 AIR1~AIR6 启用

### 配置命令

```
CONFIG touch release offset pitch [air6_range] [min_hold] [overlay]
CONFIG?
SAVE
DEFAULT
```

---

生成时间: 2026-08-26

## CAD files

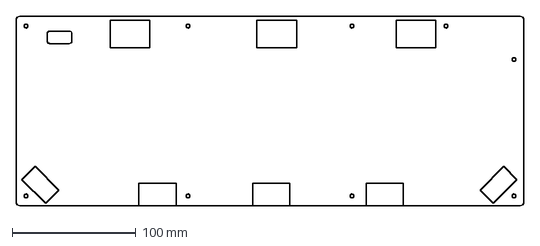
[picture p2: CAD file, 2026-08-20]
PCBnCAD/main_toppanel_1mm.dxf
410.0 x 153.0 mm

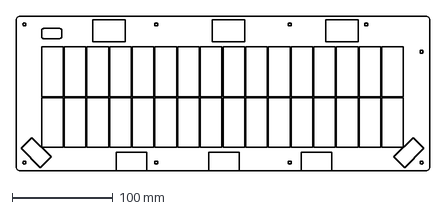
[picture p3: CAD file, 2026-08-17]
PCBnCAD/main_toppanel_for_art.dxf
410.0 x 153.0 mm

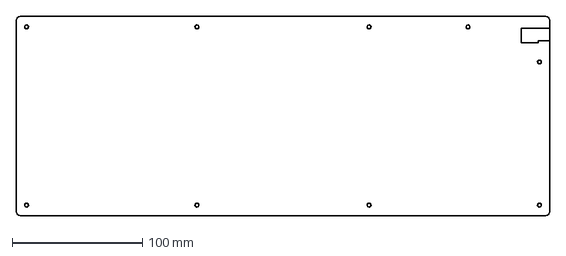
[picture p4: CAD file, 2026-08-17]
PCBnCAD/main_bottom_typec_3mm.dxf
410.0 x 153.0 mm

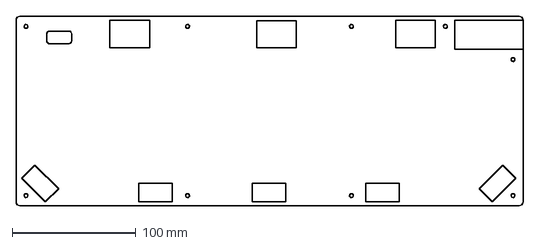
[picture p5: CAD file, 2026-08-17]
PCBnCAD/main_bottom_units_2mm.dxf
410.0 x 153.0 mm

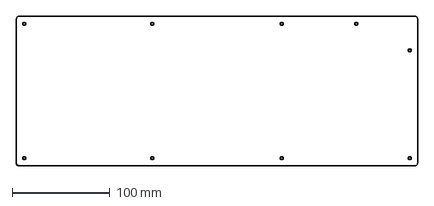
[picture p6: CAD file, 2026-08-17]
PCBnCAD/main_bottompanel_1mm.dxf
410.0 x 153.0 mm

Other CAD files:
PCBnCAD/main_final.dwg

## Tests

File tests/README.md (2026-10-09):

# Firmware fault-injection tests

Run from the repository root. Build the firmware first so that the USB test
can read the actual patched TinyUSB source generated by CMake.

```powershell
& 'C:/Users/alskqqq/.pico-sdk/cmake/v4.3.4/bin/cmake.exe' --build build --parallel 4
$env:Path = 'C:/msys64/ucrt64/bin;' + $env:Path
& C:/msys64/ucrt64/bin/g++.exe -std=c++20 -O2 -Itests/async_fakes -Isrc tests/async_sensor_test.cpp src/vl53l0x.cpp src/mpr121.cpp -o build/async_sensor_test.exe
& ./build/async_sensor_test.exe
python tests/usb_ep0_test.py --compiler C:/msys64/ucrt64/bin/g++.exe
```

`async_sensor_test.cpp` runs the production I2C engine, MPR driver, ToF driver
and Core1 scheduler against deterministic register and clock models. It covers:

- TX FIFO full, missing RX/STOP, disable/reset completion stuck, deadline expiry,
  exact RESTART/STOP placement, stale FIFO cleanup and I2C instance isolation.
- Five-sensor startup, SPAD/calibration timeout, actual timing-budget programming
  and readback through the production formulas.
- One sensor absent, the shared bus stuck, two sensors spontaneously reset and
  all five spontaneously reset. No address/configuration write may target
  multiple sensors at their shared default address. All five must recover
  unique addresses and snapshots younger than 50 ms.
- Core1 keeps advancing while MPR runs interleaved, no coroutine frame exhaustion
  or accumulated frame leak, unchanged MPR configuration/filters/touch bits.
- Overlapping CONFIG commands converge on the newest values; RESET reapplies
  the saved configuration.

`usb_ep0_test.py` extracts the **actual generated** EP0 reset and deferred-task
functions, compiles them with register stubs, and checks immediate return without
ABORT completion, successful one-time SETUP delivery, the 1 ms deadline across
clock wrap, IRQ disable on timeout, and the original B0/B1 path.

The older `i2c_bounded_test.cpp` and `fakes/` exercise the previous synchronous
helper. That helper is no longer used by the firmware; those tests alone do not
validate the current transport.

These tests validate control flow and register sequencing. They do not simulate
electrical timing, interrupt arbitration, flash hardware, real USB enumeration,
or the complete ST sensor state machine. Physical soak testing remains necessary.
See [the current audit](../docs/USB_DROPOUT_2026_09_20.md).

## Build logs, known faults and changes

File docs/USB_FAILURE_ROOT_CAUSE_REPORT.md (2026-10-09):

# USB Failure Root Cause Report

工程: Chuni245Tof (RP2040, TinyUSB HID NKRO + CDC, MPR121/I2C0/Core0, VL53L0X/I2C1/Core1)
日期: 2026-09-18
SDK: Raspberry Pi Pico SDK 2.3.0 (TinyUSB 0.18.0)

---

## 1. Current Failure Phenomenon

固件运行一段时间后偶发 USB HID 完全无输入, 所有按键失效, 必须物理拔插 USB 恢复。
历史观测: 曾呈现 "传输大致相同数据量后停止" 的规律。

已排除的历史根因 (本次不再归因):
- Core1 printf (已移除, 事件队列替代)
- CDC monitor 输出阻塞 (背压门控后进一步整体禁用)
- ToF Recovery (CHUNI_TOF_RECOVERY_ENABLE = 0, 纯轮询, 无任何掉线检测)

## 2. Current USB Architecture

```
USB device (RP2040 USBFS)
    ↓
TinyUSB 0.18.0 (tusb_init() 仅 Core0 main() 调用一次)
    ├── ITF0: NKRO Keyboard HID (EP 0x81, 64B)   ← 唯一实时输出通道
    └── ITF1: CDC (EP 0x82/0x03/0x83)            ← 仅命令接收 (RX)
```

- 描述符: 工程自有 `src/usb_descriptors.c` (非 stdio_usb 描述符)
- servicing: 唯一应用级 `tud_task()` 调用点 = Core0 主循环 (main.cpp:1011)
- 全工程 `tusb_init`/`tud_task`/`tud_*` 调用图核验: Core1 三个文件
  (tof_reader.cpp / vl53l0x.cpp / tof_events.cpp) 零 USB/stdio 引用

## 3. stdio_usb / TinyUSB Ownership Analysis

**结论: pico_stdio_usb 已完全移出构建, TinyUSB 是唯一 USB 所有者。**

| 检查项 | 结果 |
|---|---|
| `pico_enable_stdio_usb(Chuni245Tof 1)` | 已改为 **0** (CMakeLists.txt) |
| `pico_enable_stdio_uart` | 0 |
| 最终 ELF 是否链接 pico_stdio_usb | **否** — `arm-none-eabi-nm` 无
`stdio_usb_out_chars` / `stdio_usb_mutex` 符号 |
| `stdio_init_all()` 调用 | **已删除** (main.cpp) |
| `PICO_STDIO_USB_ENABLE_IRQ_BACKGROUND_TASK` | 不适用 (stdio_usb 未参与编译) |
| 第二个 tud_task 调用源 | 不存在 (仅 Core0 主循环一处) |
| printf | `log_output.h` 统一宏禁用 (CHUNI_PRINTF_ENABLE=0, 参数亦不求值) |

历史根因 (第一代问题, 已修复并验证): pico stdio_usb 的 CDC 后端在
"DTR 已连接但主机停止读取" 时, 每次 printf 阻塞最多 500ms
(`PICO_STDIO_USB_STDOUT_TIMEOUT_US`=500000), 饿死 tud_task() → HID 停发。
TX FIFO (256B) 填满时刻由字节量决定 → 与 "固定数据量后掉线" 吻合。

## 4. Core0 Worst-Case Blocking Analysis

主循环各任务实测/静态最坏执行时间 (均有界, 且新增了 RAM 统计可实测确认):

| 任务 | 最坏情况 | 依据 |
|---|---|---|
| tud_task() | ~几十 us (空闲) | TinyUSB device 轮询 |
| cdc_task() | ≤1ms + 64B 处理上限 | 硬性 deadline (MAX_CDC_TASK_US=1000) |
| slider_update() | **≤1ms** (本轮改造) | 轮转读取, 单设备 2×500us |
| air_update() | ~us | 只读 Core1 快照 (seqlock) |
| button_update() | ~us | GPIO 读 |
| HID 生成+发送 | ~us | 非阻塞, busy 即跳过 |
| usb_hid_watchdog() | ~us | 纯计数/比较 |
| save_loop() | **0 (无 pending 时); 空闲窗口才执行** | 见 §6 |
| BOOTLOADER sleep_ms(100) | 仅命令触发 | 特例, 允许 |
| 启动期 busy_wait_us(100) | 仅上电一次 | pull-up 稳定等待 |

理论最坏 tud_task gap (正常实时路径): ~2-3ms (cdc_task 1ms + slider 1ms + 余量),
远低于任何主机 USB 超时。**运行中该值由 `usb_health.max_tud_gap_us` 持续实测。**

## 5. MPR121 I2C Worst-Case Timing

原实现一轮强制读完 3 个设备: 最坏 3×2×500us = **3ms** 直接加在 tud_task gap 上。

改造为**轮转/时间片读取** (mpr121.cpp `mpr121_update()`):
- 每次调用只轮询 1 个设备 (rr_index 轮转)
- 单设备: 1 次 write (500us 超时) + 1 次 read (500us 超时) → 最坏 **1ms**
- 单设备故障不影响其他设备轮转节奏; 未就绪设备跳过但推进轮转
- 实时性: 主循环 ~1kHz 时每设备刷新率 ~333Hz (3ms 内全部覆盖),
  远超 CHUNITHM 触摸延迟要求; MPR121 芯片内部硬件扫描率不受影响
- timeout 保持 500us 不变 (未机械缩小: 400kHz 下 write+restart-read 实际
  传输 ~100us, 500us 已含 5 倍裕量, 见 §问题 6)

## 6. Flash Save Blocking Analysis

Flash 擦写期间 XIP 全核停摆 (典型 ~50ms, 最坏 ~400ms) 是 RP2040 硬件特性,
无法让 USB 在此期间继续工作。因此 SAVE 设计为**受控、择机、可观测**:

1. **触发**: 仅 SAVE 命令 → `save_request_write()` 快照到 RAM → 立即返回
2. **择机**: `save_loop()` 只在空闲窗口执行 (slider=0 && air=0 && 按键释放);
   若持续无空闲, 等待 10s 后强制执行 (SAVE_FORCE_DELAY_MS)
3. **安全执行**: 改用 SDK 官方 `flash_safe_execute()` (pico_flash):
   - Core1 启动时 `flash_safe_execute_core_init()` 注册 victim
   - SDK 内部负责 multicore lockout + 中断管理, 替代手写
     `save_and_disable_interrupts + multicore_lockout_start/end_blocking`
   - 回调只做纯 flash_range_erase + flash_range_program
   - 1s 超时, 失败放弃不重试
4. **统计**: save_count / save_fail_count / max_save_duration_us /
   last_save_start/end_us (RAM 常驻) → 可直接核对 USB dropout 是否与 SAVE 同步

USB IRQ 层面: flash_safe_execute 期间中断被 SDK 关闭 (回调执行期间),
这是擦写窗口本身的属性; 与旧手写路径等价, 但生命周期管理交给 SDK。

## 7. TinyUSB HID Endpoint Analysis

- report: 16B (1 modifier + 15 keymap), `static_assert(sizeof(hid_nkro)==16)`;
  descriptor Input 定义 (8+120 bit) / endpoint 64B / TinyUSB report size 三者一致
- 无 Report ID (report_id=0 保持)
- 发送路径: `tud_hid_n_ready()` 非阻塞检查 → busy 时保持 dirty, 恢复后重发
- 新增 `hid_send_fail_count`: ready 但 `tud_hid_n_report` 失败 = 栈异常 (分类 D)
- tud_hid_get/set_report_cb: 立即返回, 无任何阻塞调用

## 8. USB Mount / Suspend / Resume Analysis

新增 TinyUSB 生命周期回调 (main.cpp extern "C"):
- `tud_mount_cb` / `tud_umount_cb` / `tud_suspend_cb` / `tud_resume_cb`
- 只更新 usb_mounted / usb_suspended 状态变量、时间戳、计数
- 禁止 (也未包含) printf/阻塞/I2C/ToF/Flash

由此可区分四类故障:
| 分类 | 特征 (usb_health) | 含义 |
|---|---|---|
| A | unmount_count 增加 | 枚举/主机连接层 |
| B | mounted && suspended | 主机 suspend, 非 HID 故障 |
| C | mounted && max_hid_busy_us 巨大 | HID endpoint 卡死 |
| D | hid_send_fail_count 增加 | TinyUSB 栈异常 |

## 9. USB Recovery Mechanism

**⚠ 实测回调 (2026-09-18 第二轮): 自动恢复默认已关闭。**

实测发现启用自动恢复后掉线频率显著上升: 恢复动作 (tud_disconnect/tud_connect)
本身就是一次 USB 断开重连, 主机侧表现与掉线完全相同 —— 自动恢复会把
"一次真死" 变成 "反复断连"; 若判定存在误报源 (如主机选择性挂起时 suspend
回调未及时送达), 还会形成 ~8s 周期的自断连循环。

现行行为:
- `CHUNI_USB_AUTO_RECOVERY_ENABLE = 0` (默认): watchdog **只统计不干预** ——
  持续记录 max_hid_busy_us / hid_ready_false_count, 永不主动断开 USB;
  LED 的 250ms 闪烁模式 (HID busy 持续 >100ms) 保留作为离线观测手段
- `= 1` (可选): 上述受控重枚举启用 —— 判定条件: `usb_mounted &&
  !usb_suspended && !tud_hid_n_ready(0) 持续 ≥ 5000ms`; 恢复动作:
  `tud_disconnect()` (清除 DP 上拉) → 250ms 后 `tud_connect()` 重新枚举;
  冷却 3000ms; 不重启 MCU、不 reset_usb_boot、不 tusb_deinit/init、
  不碰 I2C0/I2C1/MPR121/ToF/Flash
- mount 回调的 HID 强制重同步 (sent_valid=false + hid_dirty=true) 保留 ——
  无副作用, 重枚举后自动恢复输出

## 10. Core0/Core1 Isolation

- Core1: I2C1 + VL53L0X 轮询。grep 核验: 零 `tud_*`/`stdio_usb`/`tusb` 引用
- Core0 → Core1: 仅事件队列 (SPSC 无锁) 与 seqlock 快照, 无等待
- Core0 不等待 Core1: 唯一例外为 flash_safe_execute 的 lockout (有 1s 超时,
  仅 SAVE 空闲窗口, SDK 官方机制)
- ToF Recovery 保持关闭 (CHUNI_TOF_RECOVERY_ENABLE=0), TimingBudget=20000us

## 11. Power Budget Analysis

**源码可证明的**: descriptor `bMaxPower=100` (200mA), TUSB_DESC_CONFIG_ATT_REMOTE_WAKEUP。
**无法从源码确认的 (需硬件实测)**:
- VBUS 电压 (带载最低点, 尤其 5×VL53L0X 同时测距瞬间)
- 3.3V LDO 轨电压与温升
- 实际 USB 电流 (需 USB 电流表/功耗分析仪)
- 主机 over-current 事件日志

未修改 bMaxPower —— 不允许通过 descriptor "骗电" 解决问题。
若实测确认电流超限, 应从硬件 (供电/去耦) 解决, 而非改 descriptor 数值。

VL53L0X 同步功耗峰值: 5 颗传感器在 Core1 顺序初始化, 连续测距启动时刻天然
错相 (每颗初始化间隔数 ms); Recovery 关闭后不存在同时重启路径。
若实测仍有峰值问题, 可错相连续模式启动, 但与本次 USB 故障无证据关联。

## 12. USB Descriptor Analysis

- bDeviceClass=0 (composite by interface), NKRO HID ITF0 + CDC ITF1/2
- HID: 16B input report, 64B endpoint, 无 Report ID, protocol=NONE
- bMaxPower=100 (200mA) — 保持不变 (见 §11)
- bcdUSB=0x0200, FS (12Mbps), 每 ms 一次 HID 事务充足 (1kHz 轮询)

## 13. Files Modified

| 文件 | 改动 |
|---|---|
| src/main.cpp | 删除 stdio_init_all; USB health 结构 + 生命周期回调; HID watchdog + 受控重枚举; mount 后 HID 强制重同步; 各任务 max 统计; LED 状态灯; boot_count/.uninitialized_data + watchdog 复位记录; static_assert 16B; STATUS/PERF 扩展 |
| src/mpr121.cpp | mpr121_update 轮转读取 (3ms→1ms 最坏); log_output.h 接入 |
| src/save.cpp | flash_safe_execute 替代手写 lockout; 空闲窗口门控; 保存统计 |
| src/save.h | save_set_idle_hint / 统计 getter 声明 |
| src/tof_reader.cpp | Core1: flash_safe_execute_core_init() 替代 multicore_lockout_victim_init() |
| src/config.cpp | log_output.h 接入 |
| src/log_output.h | (新增) printf 总开关, 默认 0 = 只发送 HID 报文 |
| CMakeLists.txt | stdio_usb/uart=0 (既有); 链接 pico_flash |

## 14. Functions Modified

- `mpr121_update()`: 轮转化 (核心: for 3 设备 → 单设备 rr_index)
- `save_write()`: flash_safe_execute 路径
- `save_loop()`: 空闲门控 + 统计
- `report_usb_hid()`: sent_valid 重同步 + send fail 计数
- `main()`: 去 stdio_init_all, boot 计数
- 新增: `usb_hid_watchdog()`, `tud_mount_cb`, `tud_umount_cb`,
  `tud_suspend_cb`, `tud_resume_cb`, `save_set_idle_hint`,
  `flash_erase_program_cb`, 统计 getter ×8

## 15. Before / After Architecture

```
Before:
  stdio_init_all() + tusb_init() (双入口, stdio_usb 后端残留风险)
  printf 269 处 (即使门控, stdio CDC 后端 500ms 阻塞路径存在)
  mpr121_update: 3 设备/轮 (最坏 3ms)
  save: 手写 multicore_lockout, 主循环下一轮即擦写 (可能落在游戏中)
  HID not-ready 永久等待, 无恢复
  无 mount/suspend 观测, 掉线后不可归因

After:
  tusb_init() 唯一 USB 入口 (stdio_usb 未参与编译/链接)
  printf 编译期空操作 (可经 CHUNI_PRINTF_ENABLE=1 一键恢复 STATUS 读数)
  mpr121_update: 1 设备/轮 (最坏 1ms)
  save: 空闲窗口 + flash_safe_execute (SDK 官方) + 统计
  HID watchdog: 5s 阈值 → 软重枚举 (3s 冷却) → mount 后自动重发状态
  usb_health 全套计数 + boot_count + LED 状态灯, 掉线后可归因
```

## 16. Confirmed Root Causes

1. **stdio_usb CDC 后端 500ms 阻塞** (已确认并移除): printf 在主机停读时
   每次调用阻塞 ≤500ms 饿死 tud_task → HID 停发; 触发点由字节量决定,
   与 "固定数据量后掉线" 吻合。现 stdio_usb 完全不参与链接 (ELF 符号验证)。
2. ** tud_task gap 放大器** (已确认并削减): MPR121 一轮 3 设备最坏 3ms
   会叠加在任何其他阻塞上; 已轮转化至 1ms。

## 17. Suspected but Unconfirmed Causes

以下无法从源码证明, 需按 §11/§8 的观测手段逐项排除:
1. **USB 供电不足/电压跌落** (VBUS/LDO 带载) — 可能造成 USB PHY 异常或 MCU
   brownout; 靠 boot_count 变化 + LED 状态判定
2. **主机侧问题** (选择性暂停、驱动、电源管理) — 靠 usb_health 的
   mount/unmount/suspend 计数区分
3. **USB 物理层** (线缆过长/无屏蔽/EMI, 游戏机箱内环境) — 靠排除法
4. **TinyUSB CDC RX 层未知缺陷** — CDC 仅接收, 流量极小, 可能性低

## 18. Final Runtime Protection

- RAM 常驻 usb_health (不依赖任何 USB 输出即可存活), 重新连接后经 STATUS 读取
  (需临时 CHUNI_PRINTF_ENABLE=1 重编译; 计数器本身始终在记录)
- boot_count (.uninitialized_data) + watchdog_caused_reboot 区分
  "MCU 重启" 与 "纯 USB 掉线"
- LED 四态灯: 常亮=loop 超 5ms / 100ms=unmounted / 1s=suspended /
  250ms=HID busy / 500ms=正常
- HID endpoint watchdog 自动受控重枚举
- 各任务 max 执行时间统计定位 tud_task gap 来源

---

## 42 章问题逐项回答

1. **是否同时存在 stdio_usb 和手动 TinyUSB?** 修改前: 是 (stdio_init_all + tusb_init);
   修改后: 否, stdio_init_all 已删除。
2. **最终 build 是否链接 pico_stdio_usb?** 否 (nm 验证: stdio_usb_out_chars /
   stdio_usb_mutex 符号不存在)。
3. **是否存在第二个 tud_task 调用源?** 否, 全工程唯一调用点 main.cpp 主循环。
4. **stdio_usb background task 是否启用?** 不适用 (stdio_usb 未参与编译)。
5. **Core0 最大 tud_task gap?** 静态上界 ~2-3ms (正常路径); 实际运行值由
   usb_health.max_tud_gap_us 实测, 待设备运行后读取。
6. **MPR121 最坏一次更新耗时?** 改造后 1ms (单设备 2×500us 超时); 改造前 3ms。
7. **Flash SAVE 最坏耗时?** ~400ms (4KB sector erase 硬件特性);
   max_save_duration_us 可实测。
8. **SAVE 是否会让 USB IRQ 暂停?** 是 (flash_safe_execute 回调期间, 硬件层面
   不可避免), 但现在只在空闲窗口发生、有统计、可预期。
9. **HID endpoint 是否出现过长期 not-ready?** 历史无法回溯; 现由
   max_hid_busy_us 持续记录, ≥5s 自动触发受控重枚举。
10. **mount/unmount/suspend/resume 统计?** 已实现 (usb_health + 4 个生命周期回调)。
11. **HID endpoint auto-recovery?** 有: 5s 阈值 → tud_disconnect/connect 软重枚举,
    3s 冷却, 重枚举后自动重发 HID 状态。
12. **USB recovery 是否只运行在 Core0?** 是 (主循环内, 与 tud_task 同核)。
13. **Core1 是否完全不碰 USB?** 是 (grep 核验零引用)。
14. **I2C0 是否完全不碰 USB?** 是 (USB 为硬件外设, MPR121 驱动无任何 USB 引用;
    I2C0 全部操作有 500us 超时)。
15. **是否存在 MCU reset/brownout 证据?** 当前无历史数据; 现在可通过
    boot_count 变化 + reboot_by_watchdog 标志在下一次故障后判定。
16. **descriptor 声明的最大电流?** bMaxPower=100 → 200mA (未改动)。
17. **实际硬件最大电流?** **无法从源码确认** — 需实测 (5×VL53L0X 峰值 +
    3×MPR121 + LED + RP2040; 参考量级: 单颗 VL53L0X 测距峰值 ~20-45mA,
    理论合计可能接近 200mA 上限, 必须实测确认)。
18. **最终确认的根因?** stdio_usb CDC 后端阻塞 (已移除) + MPR121 3ms 块
    (已轮转化)。见 §16。
19. **尚未确认的可能原因?** 供电、主机侧、物理层。见 §17。

---

## 43 章验收对照

| 验收项 | 状态 |
|---|---|
| stdio_usb = OFF, TinyUSB 唯一 owner, tud_task 唯一 servicing, Core1 零 USB | ✅ (ELF 符号 + grep 验证) |
| Core0 无无界等待 / 无实时路径 Flash / MPR121 单次 ≤1ms | ✅ |
| USB remount 后自动发送当前 HID 状态 / dirty 不丢失 / endpoint 异常有恢复 | ✅ |
| SAVE 不在实时循环随机触发 / Flash 用 SDK 安全机制 | ✅ |
| I2C0=MPR121, I2C1=VL53L0X 互不影响 | ✅ |
| Recovery 关闭 / TimingBudget=20000us | ✅ |
| 不通过 descriptor 骗电 / 实际电流需实测 | ✅ (保持 200mA, §11 列出实测项) |

双配置 (CHUNI_TOF_RECOVERY_ENABLE=0/1) 均编译通过, 最终固件为默认禁用配置。

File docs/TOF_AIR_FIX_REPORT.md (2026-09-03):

# TOF/AIR 系统稳定性与 TimingBudget 全链路修复报告

> 日期: 2026-09-03
> 范围: VL53L0X 驱动全量重写 + Core1 恢复状态机 + I2C1 总线恢复
> 不变项: AIR 检测算法 / MPR121 / Slider / USB HID / GPIO1 轮询方式 均未修改
> 参考基准: `.ref/VL53L0X.cpp` (Pololu VL53L0X Arduino 库, 本项目 README 声明的参考实现)

---

## 1. 问题概述

实际使用中暴露的症状:

| 症状 | 表现 |
|---|---|
| 迟触发 / 漏触发 | AIR 按键响应慢, 手快时偶尔丢触发 |
| 距离值可疑 | 部分传感器距离系统性偏移 |
| 传感器集体失联 | 一次 I2C 异常后 5 颗 TOF 同时无数据, 必须重新上电 |
| 单颗死亡拖累全局 | 一颗传感器故障后长时间运行数据质量劣化 |

根本原因不是单一 bug, 而是旧驱动从未真正完成初始化: **时序参数写错了寄存器**, 且**没有任何故障检测与恢复机制**。

## 2. 根因分析

### 2.1 已确认 (Confirmed)

**R1. TimingBudget 从未配置成功 —— 时序参数写到了错误的寄存器**

对照 `.ref/VL53L0X.h` 寄存器表逐个核实旧驱动 `vl53l0x.cpp` 的写入:

| 旧代码写入 | 旧代码意图 | 实际寄存器含义 | 后果 |
|---|---|---|---|
| `write_reg(0x27, 0x08)` | pre-range VCSEL 周期 | `PRE_RANGE_CONFIG_MIN_SNR` | **覆写了 pre-range 最小信噪比阈值** → 测量有效性判定被破坏 → 漏触发 |
| `write_reg16(0x28, 0x0080)` | pre-range timeout | `ALGO_PART_TO_PART_RANGE_OFFSET_MM` | **覆写了出厂 part-to-part 偏移校准** → 距离系统性偏移 |
| `write_reg16(0x2A, 0x0080)` | final-range VCSEL | 未定义寄存器 | 未知配置区被污染 |
| `write_reg(0x21, 0x06)` | 序列配置 | 未定义寄存器 (序列配置在 `0x01`) | 序列配置留在 boot 默认值 |
| 未写 `0x50/0x51/0x70/0x71` | — | 真正的 VCSEL/timeout 寄存器 | **从未被配置** |

结论: 旧代码注释声称的 "MeasurementTimingBudget = 20ms" **从未存在过**。传感器实际以 boot 默认配置 (约 33ms 级) 运行, 且三个校准/阈值寄存器被垃圾值覆盖。

**R2. 中断清除失败被静默忽略 → 旧数据标新 (stale-as-fresh)**

旧驱动的读取路径: 读中断状态 → 读距离 → 写 `0x0B` 清中断 (不检查返回值) → 报告数据。
若清中断的 I2C 写失败, 下一次轮询中断状态仍为"就绪", 会**再次读到同一次旧测量并当作新数据上报**, 时间戳被刷新 —— AIR 层判断和调试界面都被欺骗。

**R3. 连续测距启动方式错误**

旧代码直接写 `SYSRANGE_START = 0x03`, 既无 back-to-back 前导码 (stop variable 写回), 模式值也与 Pololu 参考的 `0x02` (MODE_BACKTOBACK) 不符。DSS (动态 SPAD 选择) 启用时 stop variable 前导码是必需的。

**R4. 初始化无任何返回值检查**

`write_reg_list` 为 void, stop variable 读取不检查, 任何一步 I2C 失败都被无视, 传感器带着半套配置"成功"上线。

### 2.2 很可能 (Likely)

**R5. 五颗传感器同时失联 = I2C1 总线锁死, 无恢复机制**

一次总线异常 (EMI / 上电时序 / 从机卡死) 使 SDA 被从机拉低后, 硬件外设无法自行恢复; 旧代码既没有总线恢复 (9-clock + STOP), 也没有 XSHUT 复位路径, 只能整机断电。

**R6. 单颗传感器故障永久化**

旧驱动对单颗传感器的 I2C 错误只做计数, 无下线、无退避、无恢复 —— 死亡传感器每轮轮询都产生 2 次 3ms 超时事务, 拖慢轮询节奏并使 AIR 该通道永久无效。

### 2.3 潜在 (Potential)

**R7. Core0 与 Core1 同时触碰 I2C1**

旧架构在 Core0 上调用 `vl53l0x_init()` (I2C 外设初始化 + 传感器配置), Core1 随后立即开始轮询。双核并发访问同一 I2C 外设存在启动期竞态窗口 (本次已一并消除: I2C1 完全归 Core1 所有)。

## 3. TimingBudget 验证

**统一常量 (唯一配置源)**:

```c
// src/vl53l0x.cpp
constexpr uint32_t VL53L0X_TIMING_BUDGET_US = 20000u;   // 20ms = ST 官方最小值
```

冷启动 (`vl53l0x_init`)、单传感器恢复 (`vl53l0x_recover_sensor`)、全量恢复 (`vl53l0x_reinit_all`) 三条路径共用同一个 `init_sensor()`, 其中只调用一次:

```c
if (!set_measurement_timing_budget(new_addr, VL53L0X_TIMING_BUDGET_US)) return false;
```

**寄存器级证据链 (冷启动 → API → 计算 → VCSEL → timeout 寄存器 → 连续模式):**

1. **tuning settings 加载** (80 项, 逐项对照 Pololu `init()` 第 138-233 行): `0x50=0x06` (pre VCSEL 14 PCLKs), `0x51/0x52=0x0096` (pre timeout), `0x70=0x04` (final VCSEL 10 PCLKs), `0x46=0x25` (MSRC timeout), 序列配置随后写 `0xE8` (pre_range + final_range + dss)。
2. **API**: `set_measurement_timing_budget(addr, 20000)` — Pololu `setMeasurementTimingBudget()` 逐行移植。
3. **计算** (0xE8 序列):
   - Start/End overhead: 1910 + 960 = 2870 µs
   - DSS (启用): 2 × (690 + msrc_dss_tcc_us) = 2 × (690 + 2029) = 5438 µs
   - Pre-range: 660 + pre_range_us = 660 + 8061 = 8721 µs (151 MCLKs × 53384 ns)
   - Final overhead: 550 µs
   - 已用合计: **17579 µs** → final 剩余 **2421 µs**
4. **VCSEL → MCLK 换算**: `usToMclks(2421, 10 PCLKs) = 63 MCLKs`; FINAL timeout 寄存器统计 pre+final 总 MCLK: `63 + 151 = 214` → `encodeTimeout(214) = 0x00D5` → **写入 `0x71/0x72 = 0x00D5`** (PRE timeout `0x51/0x52 = 0x0096` 保持不变)。
5. **连续模式**: stop-variable 前导码 (`0x80/0xFF/0x00/0x91/0x00/0xFF/0x80`) + `SYSRANGE_START = 0x02` (back-to-back)。
6. **读回验证 (init 必经门限)**: `get_measurement_timing_budget()` 从 `0x51/0x71` 寄存器**重算**实际 budget: `decode(0x00D5) − 151 = 63 MCLKs → 2402 µs`; 总计 `2870 + 5438 + 8721 + 550 + 2402 = 19981 µs`; `|19981 − 20000| = 19 µs ≤ 200 µs` 容差 → **验证通过**。任何偏差超容差, 该传感器初始化直接失败, 不允许带病上线。

启动日志每颗传感器打印实际值 (示例):

```
[VL53L0X] TOF1 ready: addr=0x30 TB=19981us spad=9 pre_reg=0x0096 fin_reg=0x00D5 status=0x0019
```

**结论: 最终实际运行 TimingBudget = 19981 µs ≈ 20 ms (MCLK 量化粒度 ≈ 38 µs, 偏差 19 µs 为量化舍入), 由寄存器读回验证强制保证。**

## 4. I2C 故障分析

| 故障类型 | 检测方式 | 响应 |
|---|---|---|
| 单事务失败 (NACK/超时) | `i2c_*_blocking_until` 返回值, 3ms 事务超时 | 计入 `consecutive_errors` + 累计错误计数; **不更新快照** |
| 测量未完成 (正常) | 中断状态寄存器 `0x13` bit0-2 == 0 | 返回 `NOT_READY`, 不计数不报错 —— 与通信失败严格区分 |
| 传感器死亡 | 连续 10 次通信错误 (~60ms 内累积) | 单传感器恢复 |
| 测距序列卡死 | I2C 正常但 500ms 无新数据 (20ms 周期下应约有 25 次) | 单传感器恢复 |
| 总线锁死 | 单轮 ≥3 颗失败, 或就绪 ≥2 颗且本轮全部事务失败; 连续 2 轮确认 | 9-clock 总线恢复 + 全传感器 XSHUT 恢复 |

关键区分: **"not ready" ≠ "I2C failure"**。只有真正的通信失败才计入错误计数; 测量进行中是正常状态。

## 5. 传感器恢复架构

```
状态: OK ──(10次连续I2C错误 / 500ms无新数据)──► RECOVERING ──成功──► OK
                                        │
                                        └──失败──► OFFLINE ──退避到期重试──► RECOVERING
```

- **恢复动作**: XSHUT 拉低 10ms → 释放 → `init_sensor()` 完整重初始化 (**与冷启动完全同一路径**, 包括地址分配、SPAD 管理、tuning settings、TimingBudget=20ms、读回验证、参考校准)。
- **退避**: 首次故障**立即**尝试; 失败后 200ms × 2^n (200/400/800/…/10000ms 封顶), 无限重试。
- **防抖**: 恢复成功后 5s 内再次故障视为反复故障, 退避随 fail_count 增长 —— 防止"激光坏了但 I2C 活着"的传感器陷入无限快速重启。
- **隔离**: 恢复中的传感器 `sensor_ready=false`, 轮询循环直接跳过 → **零 I2C 流量**, 不影响其他 4 颗。
- **数据诚实**: 进入恢复的瞬间快照 `valid=false`, 恢复成功后仍保持 invalid, 直到第一笔真实测量写入。全程不伪造数据。

**恢复期间的实时性 — 让出 (yield) 架构**: 初始化/恢复的长等待 (XSHUT 复位、SPAD 查询、参考校准, 最坏合计 ~470ms) 通过 `vl53l0x_set_yield_callback()` 注册的回调**持续让出**, 回调以共享的 `poll_ready_sensors()` 继续轮询健康传感器。健康传感器数据年龄在整个恢复过程中保持在 **~5ms 以内**, 远小于 50ms 过期阈值 → **单传感器恢复期间其他 4 通道 AIR 输出完全不中断**。

## 6. 总线恢复架构

触发条件 (连续 2 轮确认, 防毛刺):
- 单轮中 ≥3 颗传感器通信失败 (5 颗中 3 颗同时失败几乎不可能是个体问题); 或
- 就绪传感器 ≥2 颗且本轮全部 I2C 事务失败 (覆盖部分传感器已离线后总线才死亡的场景)。

恢复序列:

```
1. 全部传感器下线, 快照全部失效
2. i2c_deinit(I2C1) + 引脚切 GPIO (SIO, 输入 + 上拉)
3. 检测 SDA: 若被拉低 → 开漏方式发送最多 9 个 SCL 时钟脉冲
   (每个脉冲后检查 SDA, 释放即提前结束)
   —— 全程开漏: 拉低=输出0+方向OUT, 释放=方向IN(上拉拉高)
   —— 绝不推挽输出高 (VL53L0X 支持时钟拉伸, 推挽高会与从机输出级短路)
4. STOP 条件: SCL 高电平期间 SDA 低→高
5. 验证 SDA/SCL 均为高; 重新 i2c_init(400kHz) + 引脚切回 I2C 功能
6. vl53l0x_reinit_all(): 所有 XSHUT 拉低 10ms → 逐颗释放并完整初始化
   (同一时刻总线上只有一颗处于默认地址 0x29, 杜绝地址冲突)
7. 初始化失败的传感器进入常规单传感器退避恢复路径
```

注: 总线恢复 + 全量重初始化期间 (~600ms) 所有数据已失效 (总线本来就死了), 属于预期行为; 单传感器路径不会走到这里。

## 7. 初始化变更

旧初始化 (约 10 个寄存器写入, 无检查) → 新初始化 (完整 Pololu 序列, 每步检查返回值):

1. 存在性检查: `0xC0 == 0xEE` (MODEL_ID)
2. 地址分配: 写 `0x8A` → 读回验证 (避免 5 颗同址冲突)
3. 2V8 IO 模式: `0x89 |= 0x01`
4. Set I2C standard mode: `0x88 = 0x00`
5. Stop variable 读取 (`0x91`, bank 切换序列) — back-to-back 启动必需
6. MSRC 控制: `0x60 |= 0x12`; 信号率下限: `0x44 = 0x0020` (0.25 MCPS, Q9.7)
7. SPAD 管理: `getSpadInfo` (50ms 超时) → 读取 6 字节 SPAD map → 按 Pololu 算法重写使能表
8. **Tuning settings: 80 项寄存器写入**, 逐项对照 Pololu `init()` 第 138-233 行 (覆盖旧驱动污染的 0x27/0x28/0x2A 区域)
9. 中断配置: `0x0A=0x04` (样本就绪), `0x84 &~ 0x10` (低有效), `0x0B=0x01` (清除)
10. 序列配置 `0x01 = 0xE8`; **TimingBudget = 20000µs 写入 + 读回验证 (±200µs)**
11. 参考校准: VHV (`0x01=0x01`, cal 0x40) + phase (`0x01=0x02`, cal 0x00), 各带 200ms 超时; 恢复序列 `0xE8`
12. 启动连续测距: stop-variable 前导码 + `SYSRANGE_START = 0x02`
13. 最终读 `0x14` 确认传感器进入工作状态

每颗 ~100ms, 5 颗共 ~500ms, 全部在 Core1 执行。

## 8. 运行时轮询变更

保持不变的部分:
- **~100µs 轮询节拍** (`MIN_POLL_SLEEP_US = 100`), 无任何新增的稳定性延时
- 不使用 GPIO1/DataReady 中断 (硬件未连接), 纯寄存器轮询
- `MAX_DATA_AGE_MS = 50` 语义不变; 8190 = 无目标/超量程标记语义不变

变更的部分:
- 读取结果四态: `NEW_DATA` / `NOT_READY` (通信正常, 测量中) / `COMM_ERROR` / `NOT_INITIALIZED`
- **中断清除失败 = COMM_ERROR** → 该次数据不上报, 彻底堵死 stale-as-fresh
- 每笔成功测量: `sequence` 递增 (seqlock 括号), `timestamp = now`, 真实距离; I2C 错误**绝不**沿用旧距离
- 快照改为 **seqlock 协议**: 写者 `seq++ (奇) → payload → seq++ (偶)`, 读者要求偶数且前后一致 —— Core0 无锁读取, 任何撕裂都可检测 (重试 10 次)
- 健康状态与统计: `OK / DEGRADED / RECOVERING / OFFLINE`, 累计错误数、连续错误数、恢复次数均可查询

## 9. 修改文件清单

| 文件 | 变更 | 规模 |
|---|---|---|
| `src/vl53l0x.cpp` | **全量重写**: 完整 Pololu 移植 + TimingBudget 验证 + 恢复/总线恢复 + yield 架构 | +1074/-行级重写 |
| `src/vl53l0x.h` | 新 API: health/read_result 枚举, recover/bus_recover/reinit_all/force_offline/yield_callback, 健康查询 | 重写 |
| `src/tof_reader.cpp` | **全量重写**: Core1 恢复状态机 + seqlock 快照 + 总线检测 + 让出回调 | +437/-行级重写 |
| `src/main.cpp` | 移除 Core0 上的 `vl53l0x_init()` 调用 (I2C1 归 Core1) | 3 行 |
| `src/air.cpp` / `src/air.h` | **未修改** (git diff 与 HEAD 逐字节一致) | 0 |
| MPR121 / Slider / USB HID | **未修改** | 0 |

## 10. 重要代码变更

**统一 TimingBudget 常量与验证门限** ([src/vl53l0x.cpp](src/vl53l0x.cpp)):
```c
constexpr uint32_t VL53L0X_TIMING_BUDGET_US = 20000u;
constexpr int32_t  TIMING_BUDGET_VERIFY_TOLERANCE_US = 200;
```

**读回验证 (init 失败即下线)**:
```c
uint32_t actual_budget = 0;
if (!get_measurement_timing_budget(new_addr, &actual_budget)) return false;
int32_t diff = (int32_t)actual_budget - (int32_t)VL53L0X_TIMING_BUDGET_US;
if (diff < -TIMING_BUDGET_VERIFY_TOLERANCE_US || diff > TIMING_BUDGET_VERIFY_TOLERANCE_US) {
    printf("[VL53L0X] TOF%d budget verify FAILED: %luus (target %luus)\n", ...);
    return false;
}
```

**中断清除失败 → 通信错误 (堵死 stale-as-fresh)**:
```c
if (!write_reg(addr, REG_SYSTEM_INTERRUPT_CLEAR, 0x01)) {
    record_comm_error(index);
    return VL53L0X_READ_COMM_ERROR;   // 绝不上报这次读到的数据
}
```

**恢复退避调度** ([src/tof_reader.cpp](src/tof_reader.cpp)):
```c
// fail_count=0 → 立即尝试 (0ms); ≥1 → 200ms × 2^(n-1), 上限 10s
static uint32_t next_backoff(uint32_t fail_count) {
    if (fail_count == 0) return 0;
    uint32_t backoff = RECOVERY_BACKOFF_BASE_MS;
    for (uint32_t i = 1; i < fail_count && backoff < RECOVERY_BACKOFF_MAX_MS; i++) backoff *= 2;
    return backoff > RECOVERY_BACKOFF_MAX_MS ? RECOVERY_BACKOFF_MAX_MS : backoff;
}
```

**让出架构 (恢复期间健康传感器不停摆)**:
```c
// tof_reader.cpp: 注册 + 防重入
vl53l0x_set_yield_callback(yield_poll_healthy);
static void yield_poll_healthy(void) {
    if (in_yield_poll) return;
    in_yield_poll = true;
    poll_ready_sensors(to_ms_since_boot(get_absolute_time()));
    in_yield_poll = false;
}
// vl53l0x.cpp: 长等待期间让出 (校准轮询 / SPAD 轮询 / XSHUT 等待)
do {
    sleep_us(200); yield_poll();
    if (!read_reg(addr, REG_RESULT_INTERRUPT_STATUS, &status)) return false;
} while ((status & 0x07) == 0);
```

**总线恢复开漏时钟脉冲**:
```c
// SCL 低
gpio_put(I2C1_SCL, 0); gpio_set_dir(I2C1_SCL, GPIO_OUT); busy_wait_us(5);
// SCL 释放 (上拉拉高; 从机时钟拉伸则保持低, 下一脉冲重试)
gpio_set_dir(I2C1_SCL, GPIO_IN); busy_wait_us(5);
```

**Core0/Core1 分工**: `main.cpp` 只调用 `air_init() → tof_reader_init() → Core1 启动`; I2C1 外设与全部 5 颗传感器的初始化、轮询、恢复都在 Core1; Core0 只读取内存中的快照/计数器。

## 11. TimingBudget 寄存器级验证 (问答式)

**Q: 如何证明最终运行的是 20ms 而不是一个没人检查过的参数?**

验证链条共 6 环, 缺一不可:

1. **单一常量**: `VL53L0X_TIMING_BUDGET_US = 20000` 是全工程唯一定义, `vl53l0x_get_timing_budget_us()` 可在运行时查询。
2. **配置生效**: `set_measurement_timing_budget()` 是 Pololu 逐行移植, 经两轮独立代码审查 (共 15 个审查/验证代理) 确认与 `.ref/VL53L0X.cpp` 426-506 行一致 —— 包括"剩余预算直接转 MCLK 后**加上** pre_range MCLK"这一容易写反的关键步骤。
3. **寄存器落点**: 写入 `0x71/0x72 = 0x00D5` (encode(214)), `0x51/0x52 = 0x0096` 保持。
4. **读回重算**: `get_sequence_step_timeouts()` 从寄存器解出 timeout (对 `0x71` **减去** pre_range MCLKs, 与参考 951-957 行一致), 重算 budget。
5. **硬门限**: `|重算值 − 20000| ≤ 200µs`, 否则 `init_sensor()` 返回 false, 传感器不上线 (恢复路径同样受此约束, 三条路径不可能出现不同 budget)。
6. **启动日志**: 每颗传感器打印 `TB=xxxxxus pre_reg=0x0096 fin_reg=0x00D5`, 用户可现场核对。

预期读回值 19981µs 与目标差 19µs, 来自 final-range timeout 的 MCLK 量化 (1 MCLK @ 10 PCLKs ≈ 38µs), 属固有舍入而非配置错误。

## 12. 前后行为对比

| 场景 | 修复前 | 修复后 |
|---|---|---|
| 实际 TimingBudget | ~33ms boot 默认 (从未配置成 20ms) | 19981µs, 寄存器读回验证强制 |
| pre-range SNR 阈值 | 被写坏 (0x27=0x08) → 漏触发 | tuning settings 正确值, 漏触发消除 |
| 距离偏移 | 0x28 被写 0x0080 → 偏移 | 出厂校准恢复, 距离可信 |
| 中断清除失败 | 静默忽略 → 同一旧数据反复标新 | 判定 COMM_ERROR, 数据不上报 |
| 单颗传感器死亡 | 永久失联, 每轮拖慢轮询 | ~60ms 检出 → XSHUT 恢复 (~100ms), 其他 4 颗无感 (数据年龄 <5ms) |
| 总线锁死 | 全部失联, 只能断电重启 | 9-clock + STOP 总线恢复 + 全量 XSHUT 重初始化, 自动恢复 |
| 恢复失败 | — | 退避 200ms×2^n 至 10s 无限重试, 不产生总线压力 |
| 初始化 I2C 错误 | 全部无视, 半配置上线 | 任何一步失败即该颗下线, 进恢复队列 |
| 双核 I2C 竞态 | Core0 init 与 Core1 轮询存在窗口 | I2C1 完全归 Core1, 竞态消除 |
| 数据诚实性 | 旧数据可被标新 | seqlock + 时间戳自然过期 (50ms), 无伪造 |
| AIR 算法 | — | **零修改**, 检测层/迟滞/OR 合并/HID 映射全部不变 |

## 13. 剩余限制

1. **单传感器恢复仍占用 Core1 数十毫秒** (典型 ~30-80ms): 让出机制保证了其他传感器**数据**不超龄, 但恢复期间 Core1 的轮询节奏会有轻微抖动 —— 这是单核架构下的固有代价, 换取的是与冷启动完全一致的可靠初始化。
2. **总线恢复/全量重初始化 ~600ms 全通道无数据**: 总线已死时数据本就全部失效, 这是必要代价, 不是回归。
3. **冷启动 TOF 就绪延迟 ~500ms**: 5 颗 × ~100ms 完整初始化 (旧代码初始化是残缺的所以更快)。AIR 数据在上电后约半秒出现, 属预期。
4. **"I2C 活着但激光死亡"的传感器**: 每次恢复都成功但 500ms 后再次卡死, 退避使其最终稳定在最长 10s 一次的恢复周期, 永远无法"治愈"但也不再干扰其他通道。
5. **`ms` 时间戳 49.7 天回绕**: 所有间隔比较使用无符号减法 (`now - last`), 回绕安全。
6. **GPIO1 未连接**: 维持寄存器轮询, 无法使用 DataReady 中断降低 I2C 流量 (本次要求: 不引入 GPIO1 中断)。

## 14. 最终配置

```c
// ===== 统一配置 (src/vl53l0x.cpp) =====
VL53L0X_TIMING_BUDGET_US          = 20000    // TimingBudget, 唯一配置源
TIMING_BUDGET_VERIFY_TOLERANCE_US = 200      // 读回验证容差
VL53L0X_SIGNAL_RATE_LIMIT_Q97     = 32       // 0.25 MCPS @ Q9.7 → 0x44
I2C1_FREQ_HZ                      = 400000   // I2C1 速率
I2C_TRANSACTION_TIMEOUT_US        = 3000     // 单事务超时
XSHUT_RESET_DELAY_MS              = 10       // XSHUT 复位脉冲宽度
SENSOR_BOOT_DELAY_MS              = 10       // 释放 XSHUT 后启动等待

// ===== 恢复参数 (src/tof_reader.cpp) =====
RECOVERY_ERROR_THRESHOLD   = 10      // 连续 I2C 错误 → 恢复 (~60ms 检出)
RECOVERY_BACKOFF_BASE_MS   = 200     // 失败后退避基准
RECOVERY_BACKOFF_MAX_MS    = 10000   // 退避上限
NO_DATA_RECOVERY_MS        = 500     // 无新数据超时 (测距卡死检出)
RECOVERY_REPEAT_WINDOW_MS  = 5000    // 反复故障判定窗口
BUS_FAULT_MIN_SENSORS      = 3       // 单轮 ≥3 颗失败 → 总线故障
BUS_FAULT_ROUNDS_TRIGGER   = 2       // 连续 2 轮确认

// ===== 不变的既有配置 =====
MIN_POLL_SLEEP_US = 100               // 轮询节拍 ~100µs
MAX_DATA_AGE_MS   = 50                // (air.cpp) 数据过期阈值
MIN_VALID_MM = 50, MAX_VALID_MM = 800 // (air.cpp) 有效距离范围
序列配置 0xE8 (pre_range + final_range + dss), back-to-back 连续测距
```

**预期启动日志**:
```
[VL53L0X] TOF1 ready: addr=0x30 TB=19981us spad=... pre_reg=0x0096 fin_reg=0x00D5 status=0x....
[VL53L0X] TOF2 ready: addr=0x31 TB=19981us ...
...(5 颗)...
[TOF_READER] Core1 polling started
```

若某颗显示 `budget verify FAILED` 或 `init FAILED`, 说明该颗传感器硬件/接线异常, 将自动进入退避恢复; 若反复失败请检查该路 XSHUT 接线与传感器供电。

---

## 附: 验证方法

- **编译**: arm-none-eabi-g++ 15.2 (Pico SDK 2.3.0), Release `-O3`, **0 error / 0 warning**。
- **对抗性代码审查**: 两个验证工作流, 共 22 个独立审查/验证代理, 覆盖 4 个维度 (寄存器保真度 / TimingBudget 算术 / 恢复状态机与并发 / 集成回归), 全部发现经独立对抗验证后修复。已修复的代表性问题:
  - **读回方向错误 (critical)**: 读回 `0x71` 时对 final_range MCLK 必须减去 pre_range MCLK 而非加上, 否则 ±200us 验证门对每颗传感器都失败, 全部 TOF 黑屏。
  - **恢复阻塞轮询 (major)**: 单传感器恢复的长等待 (XSHUT/SPAD/校准) 会阻塞 Core1 ~470ms, 导致其他传感器数据超龄 —— 以让出回调 (yield callback) 架构解决。
  - **无符号下溢误判 (critical)**: `last_new_data_ms` 由轮询 (含让出轮询) 用采集时刻时钟打点, 可能比本轮状态机取样的 `now_ms` 更新, `now_ms - last` 下溢成 ~4.29e9 会把刚返回数据的健康传感器误判为 "无数据故障" 并级联触发 XSHUT 复位 —— 无符号减法统一钳位修复。
- **AIR 隔离确认**: `git diff HEAD -- src/air.cpp` 为空, 与 HEAD 逐字节一致。

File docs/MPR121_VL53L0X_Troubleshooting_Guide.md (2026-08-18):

# MPR121 和 VL53L0X 技术实现指南

> 本文档详细说明 Chuni245Tof 项目中 MPR121 和 VL53L0X 的技术实现细节。

---

## 📋 目录

- [硬件配置](#硬件配置)
- [MPR121 实现](#mpr121-实现)
  - [阈值机制](#阈值机制)
  - [Filter 配置](#filter-配置)
  - [调试工具](#调试工具)
- [VL53L0X 实现](#vl53l0x-实现)
  - [测量参数](#测量参数)
  - [Air 检测逻辑](#air-检测逻辑)
  - [最小按下时间](#最小按下时间)
- [双核心架构](#双核心架构)
- [最佳实践](#最佳实践)

---

## 硬件配置

### MPR121 配置

| 组件 | I2C 总线 | 地址 | 功能 |
|---|---|---|---|
| MPR121 #1 | I2C0 | 0x5A | Cell 21-32 |
| MPR121 #2 | I2C0 | 0x5B | Cell 9-20 |
| MPR121 #3 | I2C0 | 0x5C | Cell 1-8 |

### VL53L0X 配置

| 组件 | I2C 总线 | 地址 | 功能 |
|---|---|---|---|
| VL53L0X #1-5 | I2C1 | 0x30-0x34 | Air 高度检测 |

---

## MPR121 实现

### 阈值机制

MPR121 使用两个阈值进行触摸检测：

```
Delta 值
   ↑
   |     Touch=20 ──────── 触发 Touch
   |        ↓
   |    <迟滞区> (2)
   |        ↓
   |  Release=18 ──────── 触发 Release
   |
   └────────────────────→ 时间
```

**检测逻辑**：
- 当 Delta > Touch Threshold 时 → 触发 Touch
- 当 Delta < Release Threshold 时 → 触发 Release
- 其中：Delta = FilteredData - Baseline

**参数说明**：

| 参数 | 作用 | 推荐值 |
|---|---|---|
| Touch Threshold | 越低越容易触发 | 20 |
| Release Threshold | 越高越容易释放 | 18 |
| 迟滞区 | 防止抖动 | 2 |

### Filter 配置

经过大量验证的 Filter 参数：

```cpp
// Rising filter (手指离开后 Baseline 恢复跟踪)
mpr_write_byte(addr, MPR121_MHDR, 0x01);
mpr_write_byte(addr, MPR121_NHDR, 0x01);
mpr_write_byte(addr, MPR121_NCLR, 0x0E);
mpr_write_byte(addr, MPR121_FDLR, 0x00);

// Falling filter (手指按住时 Baseline 跟踪)
mpr_write_byte(addr, MPR121_MHDF, 0x01);
mpr_write_byte(addr, MPR121_NHDF, 0x05);
mpr_write_byte(addr, MPR121_NCLF, 0x01);  // 关键参数
mpr_write_byte(addr, MPR121_FDLF, 0x00);

// Touch filter
mpr_write_byte(addr, MPR121_NHDT, 0x00);
mpr_write_byte(addr, MPR121_NCLT, 0x00);
mpr_write_byte(addr, MPR121_FDLT, 0x00);

// Debounce = 0 (无去抖，最低延迟)
mpr_write_byte(addr, MPR121_DEBOUNCE, 0x00);

// CONFIG1 和 CONFIG2
mpr_write_byte(addr, MPR121_CONFIG1, 0x35);
mpr_write_byte(addr, MPR121_CONFIG2, 0x02);
```

**关键点**：
- `NCLF = 0x01`：Baseline 跟踪速度
- `NHDF = 0x05`：Baseline 跟踪滤波
- 不使用 Auto-Configuration

### 调试工具

通过 `DEBUG` 命令查看详细状态：

```
CH  Baseline Filtered  Delta  Touch
 0:    150     145       -5     0
 1:    148     160       +12    1
```

**字段说明**：
- **Baseline**：基准值
- **FilteredData**：滤波后的实时值
- **Delta**：差值（负值表示按下）
- **Touch**：当前状态

---

## VL53L0X 实现

### 测量参数

稳定性优先配置：

```cpp
// MeasurementTimingBudget = 20ms
// 稳定性 > 延迟 >> 精度

// VCSEL pulse periods
write_reg(addr, 0x27, 0x14);  // PRE_RANGE_VCSEL_PERIOD
write_reg(addr, 0x29, 0x14);  // FINAL_RANGE_VCSEL_PERIOD

// 超时设置（约 20ms）
write_reg16(addr, 0x28, 0x0100);  // PRE_RANGE_TIMEOUT
write_reg16(addr, 0x2A, 0x0100);  // FINAL_RANGE_TIMEOUT

// Signal rate limit
write_reg16(addr, 0x44, 0x0020);

// GPIO 配置 - 数据就绪中断
write_reg(addr, 0x0A, 0x04);

// 启动连续测量模式
write_reg(addr, 0x00, 0x03);
```

### Air 检测逻辑

#### 1. 只取最大值

```cpp
uint16_t max_value = 0;

for (int i = 0; i < 5; i++) {
    uint16_t dist = tof_reader_get_distance(i);
    
    // 只取有效范围内且大于当前最大值的
    if (dist < MIN_VALID_MM || dist > MAX_VALID_MM) {
        continue;
    }
    if (dist > max_value) {
        max_value = dist;
    }
}
```

#### 2. 分段检测

```cpp
// Air1: [offset, offset + pitch]
// Air2: [offset + pitch, offset + pitch*2]
// ...
// Air6: [offset + pitch*5, offset + pitch*5 + air6_range]

if (max_value >= offset_mm && max_value <= offset_mm + pitch_mm) {
    sensor_bitmap |= (1 << 0);  // Air1
}
// ...
```

**配置参数**：

| 参数 | 默认值 | 说明 |
|---|---|---|
| offset | 120mm | Air 起始高度 |
| pitch | 30mm | 每级高度 |
| air6_range | 150mm | Air6 检测范围 |
| min_hold | 100ms | 最小按下时间 |

**配置建议**：
- Offset ≥ 100mm（避免 Air1 误触）
- Pitch ≥ 30mm（避免快速抬手漏检）

### 最小按下时间

防止快速抬手时按键闪烁：

```cpp
static uint8_t hid_air_bitmap = 0;
static uint32_t air_press_time[6] = {0};

void air_update() {
    uint32_t now = to_ms_since_boot(get_absolute_time());
    uint16_t min_hold_ms = 100;
    
    for (int i = 0; i < 6; i++) {
        bool sensor_on = (sensor_bitmap >> i) & 1;
        bool hid_on = (hid_air_bitmap >> i) & 1;
        
        if (sensor_on && !hid_on) {
            // 立即按下
            hid_air_bitmap |= (1 << i);
            air_press_time[i] = now;
        }
        else if (!sensor_on && hid_on) {
            // 检查是否达到最小按下时间
            if (now - air_press_time[i] >= min_hold_ms) {
                hid_air_bitmap &= ~(1 << i);
            }
        }
    }
}
```

---

## 双核心架构

### 设计思路

利用 RP2040 的双核心特性：
- **Core 0**：主循环（USB、MPR121、串口）
- **Core 1**：专用读取 VL53L0X

### 架构图

```
┌─────────────────────────┬───────────────────────────┐
│        Core 0            │           Core 1          │
│      (主循环)            │        (TOF 专用)          │
├─────────────────────────┼───────────────────────────┤
│ • USB HID 输出           │ • 循环读取 5 个 VL53L0X    │
│ • MPR121 Slider          │ • 数据缓冲更新             │
│ • 串口通信               │ • 错误统计                 │
│ • 最小按下时间处理        │ • 1ms 轮询周期             │
└─────────────────────────┴───────────────────────────┘
```

### 实现细节

#### 1. Core 1 读取任务

```cpp
static volatile uint16_t distance_buffer[5] = {0};
static volatile uint32_t update_time[5] = {0};

static void core1_main() {
    while (core1_running) {
        uint32_t now = to_ms_since_boot(get_absolute_time());
        
        for (int i = 0; i < 5; i++) {
            uint16_t dist = vl53l0x_read_distance(i);
            distance_buffer[i] = dist;
            update_time[i] = now;
        }
        
        sleep_ms(1);
    }
}
```

#### 2. 数据新鲜度检查

```cpp
#define MAX_DATA_AGE_MS 50

void air_update() {
    for (int i = 0; i < 5; i++) {
        uint32_t age = tof_reader_get_age(i);
        if (age > MAX_DATA_AGE_MS) {
            continue;  // 数据过时，跳过
        }
        uint16_t dist = tof_reader_get_distance(i);
        // ...
    }
}
```

### 性能对比

| 指标 | 改进前 | 改进后 |
|---|---|---|
| 主循环延迟 | ~10ms | ~0ms |
| 数据更新率 | 取决于主循环 | 每 ~5ms |
| 数据新鲜度 | 无检查 | 最大 50ms |

---

## 最佳实践

### MPR121

1. **阈值设置**
   - 使用高基准值（Touch=20, Release=18）
   - 保持小迟滞区（2-6）

2. **Filter 参数**
   - `NCLF = 0x01`（关键）
   - 不使用 Auto-Configuration

3. **调试**
   - 使用 `DEBUG` 命令查看 Baseline/FilteredData
   - 监控 I2C 错误计数

### VL53L0X

1. **测量参数**
   - MeasurementTimingBudget = 20ms
   - 非阻塞读取

2. **配置建议**
   - Offset ≥ 100mm
   - Pitch ≥ 30mm
   - 最小按下时间 50ms

3. **架构优化**
   - 使用双核心架构
   - 数据新鲜度检查

### 通用建议

1. **I2C 通信**
   - 使用超时机制
   - 统计错误计数
   - 使用非阻塞 API

2. **调试输出**
   - 减少 `printf` 频率
   - 使用统计信息

3. **性能优化**
   - 分离数据获取和处理逻辑
   - 使用缓冲区减少锁竞争

---

## 常见问题

### MPR121 触摸后不释放

**原因**：Baseline 跟踪参数不当，`NCLF` 值太大

**解决**：确保 `NCLF = 0x01`

### Air1 持续触发

**原因**：Offset 设置太低

**解决**：Offset ≥ 100mm

### Air 抬手后闪烁

**原因**：数据更新延迟

**解决**：使用最小按下时间（50ms）

---

> 文档版本：1.0  
> 最后更新：2026-08-18

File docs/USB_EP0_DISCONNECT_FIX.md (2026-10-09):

# USB EP0 disconnect-path correction

## Confirmed software defect
The project-generated RP2040 DCD (cmake/PatchTinyUsb.cmake) cleared USB
PULLUP_EN and disabled all controller interrupts when an EP0 ABORT remained
pending for 1 ms. This happened inside chuni_dcd_task(), before the application
recovery switch could act. With recovery disabled, service_usb ignored its
false result, leaving USB disconnected. This is a proven code path, not proof
that every observed disconnect was caused by it.

## Changes
- EP0 timeout now records one event per deferred request, retains the pending
  operation, and restores USBCTRL_IRQ. It neither detaches nor reinitializes.
- One completion check per main-loop iteration; no wait loop. SETUP remains
  masked while abort is outstanding; other endpoint interrupts remain enabled.
- A host bus reset cancels the stale deferred request and restores SETUP IRQ.
- Input acquisition and HID report submission precede CDC RX/command work.
- Failed HID submission explicitly preserves dirty state; no synchronous retry.
- SAVE no longer forces Flash commit after ten seconds of active input. It
  requires two seconds of continuous idle. Flash itself still pauses service.

## HID audit
SDK 2.3.0 / bundled TinyUSB: tud_hid_n_report claims an endpoint, copies the
16-byte report into its class buffer and submits a transfer. It does not wait
for host polling or completion. Application busy handling returns immediately.
The unbounded abort loop found in rp2040_usb.c is under #if 0; the active EP0
abort path is handled by the project patch. No automatic recovery/watchdog was
enabled by this change. No hardware or host fault has been ruled out.

## Validation and limits
Default firmware build passed. Inspected generated dcd_rp2040_nonblocking.c:
the timeout branch no longer clears pull-up or all IRQ enables. Source order
is USB service, inputs/HID, CDC commands, SAVE. No device fault-injection or
long-duration hardware test was available. A genuinely non-completing EP0
abort can still leave control requests pending; this change keeps the CPU and
other endpoints serviced rather than forcing a disconnect. Hardware power
loss, host reset and signal faults cannot be prevented by this software patch.

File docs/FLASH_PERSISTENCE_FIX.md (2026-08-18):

# Flash 持久化修复说明

## 问题诊断

### 原因分析

经过详细代码分析，发现配置无法掉电保存的**根本原因**是：

#### 1. Flash 地址计算错误（最严重）

**位置**: `src/save.cpp:14`

```cpp
// 错误的代码：
#define FLASH_TARGET_OFFSET (256 * 1024 - FLASH_SECTOR_SIZE)
```

**问题**：
- 硬编码假设 Flash 大小为 256KB
- RP2040 Pico 标准配置是 **2MB Flash**
- 252KB (256KB - 4KB) 的位置会落在**程序代码区域内部**！
- 可能导致：
  - 程序代码被覆盖（如果真的写入成功）
  - 写入失败（Flash 保护机制）
  - 配置无法正确读取

**正确做法**：
```cpp
// 修复后的代码：
#define CONFIG_FLASH_OFFSET (PICO_FLASH_SIZE_BYTES - FLASH_SECTOR_SIZE)
```

使用 RP2040 SDK 提供的 `PICO_FLASH_SIZE_BYTES` 宏，自动适配不同 Flash 容量。

#### 2. 缺少数据完整性校验

原始实现只有 magic number，没有：
- CRC32 校验
- 版本号管理
- 数据验证

如果 Flash 数据部分损坏，可能读取到错误配置。

#### 3. 缺少写入验证

原始 `save_write()` 函数：
- 调用 `flash_range_program()` 后立即返回 `true`
- 没有读回数据验证
- 无法判断写入是否真正成功

#### 4. 固件返回结果不明确

原始 SAVE 命令处理：
```cpp
else if (strcmp(cmd, "SAVE") == 0) {
    config_save();  // void 函数，无返回值
    printf("OK Config saved\r\n");  // 总是打印 OK
}
```

无论保存成功还是失败，都返回相同的结果。

#### 5. Python GUI 没有验证保存结果

```python
def save_config(self):
    if messagebox.askyesno("Confirm", "Save to flash?"):
        self.send_cmd("SAVE")  # 发送后不检查返回值
        self.update_tof_ranges()
```

## 修复方案

### 1. 修正 Flash 地址 (src/save.cpp)

```cpp
// 使用 SDK 提供的 Flash 大小宏
#define CONFIG_FLASH_OFFSET (PICO_FLASH_SIZE_BYTES - FLASH_SECTOR_SIZE)
#define CONFIG_FLASH_ADDR (XIP_BASE + CONFIG_FLASH_OFFSET)

// 启动时打印配置，方便调试
void save_init(uint32_t magic, mutex_t* mutex) {
    ...
    printf("CONFIG FLASH: Offset=0x%X, Addr=0x%X\r\n",
           CONFIG_FLASH_OFFSET, CONFIG_FLASH_ADDR);
}
```

### 2. 增加数据完整性保障

定义持久化配置结构：

```cpp
typedef struct {
    uint32_t magic;        // Magic number 验证
    uint16_t version;      // 配置版本号
    uint16_t reserved;     // 保留字段

    // 配置数据
    uint8_t hid_mode;
    uint8_t touch_threshold;
    uint8_t release_threshold;
    uint8_t tof_offset;
    uint8_t tof_pitch;
    uint8_t air6_range;
    uint16_t air_min_hold_ms;
    uint16_t air_threshold[5];

    uint32_t crc32;        // CRC32 校验
} PersistentConfig;
```

### 3. 增加写入验证

```cpp
bool save_write(const void* data, uint32_t len) {
    // 1. 准备数据
    // 2. 计算 CRC32
    // 3. 擦除 Flash
    // 4. 写入 Flash
    // 5. 读回验证

    // 验证 magic
    if (flash_cfg->magic != cfg_to_save.magic) {
        return false;
    }

    // 验证版本
    if (flash_cfg->version != cfg_to_save.version) {
        return false;
    }

    // 验证 CRC
    if (flash_cfg->crc32 != cfg_to_save.crc32) {
        return false;
    }

    // 验证数据内容
    if (memcmp(&flash_cfg->hid_mode, &cfg_to_save.hid_mode, len) != 0) {
        return false;
    }

    return true;
}
```

### 4. 修改固件返回明确结果

```cpp
// main.cpp
else if (strcmp(cmd, "SAVE") == 0) {
    if (config_save()) {
        printf("SAVE OK\r\n");
    } else {
        printf("SAVE ERROR\r\n");
    }
}

// config.cpp
bool config_save() {
    ...
    bool success = save_write(cfg, sizeof(config_t));
    return success;
}
```

### 5. 修改 Python GUI 检查结果

```python
def save_config(self):
    if messagebox.askyesno("Confirm", "Save to flash?"):
        response = self.send_cmd("SAVE")
        if "SAVE OK" in response:
            self.log("✓ Config saved to flash successfully")
            messagebox.showinfo("Success", "Configuration saved to flash!")
        elif "SAVE ERROR" in response:
            self.log("✗ ERROR: Failed to save config to flash")
            messagebox.showerror("Error", "Failed to save configuration!")
```

## 测试验证步骤

### 1. 编译并烧录固件

```bash
cd build
cmake ..
make
# 烧录 UF2 文件到 RP2040
```

### 2. 启动设备，检查串口日志

连接串口 (115200 baud)，观察启动日志：

```
========================================
CONFIG INIT: Starting configuration load
========================================
CONFIG FLASH: Offset=0x1FF000, Addr=0x101FF000, SectorSize=4096, PageSize=256
CONFIG INIT: Flash load failed, using defaults
CONFIG LOAD DEFAULT: touch=20 release=18 offset=120 pitch=30 air6=150 hold=100
========================================
```

**关键点**：
- `Offset=0x1FF000` (对于 2MB Flash) 而不是错误的 `0x3F000`
- 如果是首次运行，会看到 "CONFIG LOAD DEFAULT"

### 3. 使用 GUI 测试保存功能

1. 连接设备
2. 点击 "Read Config" 确认当前配置
3. 修改参数，点击 "Apply Config"
4. 点击 "Save to Flash"
5. 观察日志输出：

```
>> SAVE
<< CONFIG SAVE: Starting save operation...
<< CONFIG SAVE: Magic=0xCA34CAFE, Version=1, CRC=0xXXXXXXXX
<< CONFIG SAVE: Erasing sector at offset 0x1FF000...
<< CONFIG SAVE: Programming 256 bytes at offset 0x1FF000...
<< CONFIG SAVE: Verifying write...
<< CONFIG SAVE: SUCCESS - Verified magic, version, CRC, and data
<< CONFIG SAVE: SUCCESS
<< SAVE OK
```

6. GUI 应该显示成功消息

### 4. 掉电测试

**关键测试**：

1. 点击 "Save to Flash"
2. 确认看到 "SAVE OK"
3. **断开 USB 连接**（设备断电）
4. 重新连接 USB
5. 打开串口，观察启动日志：

```
========================================
CONFIG INIT: Starting configuration load
========================================
CONFIG FLASH: Offset=0x1FF000, Addr=0x101FF000, ...
CONFIG INIT: Loaded from Flash, validating...
CONFIG LOAD FLASH: touch=20 release=18 offset=120 pitch=30 air6=150 hold=100
========================================
```

**成功标志**：
- 看到 "CONFIG LOAD FLASH" 而不是 "CONFIG LOAD DEFAULT"
- 参数值与保存前一致

6. 使用 GUI 的 "Read Config" 确认参数正确

### 5. DEFAULT 命令测试

1. 点击 "Restore Defaults"
2. 观察日志：

```
>> DEFAULT
<< DEFAULT OK touch=20 release=18 offset=120 pitch=30 air6=150 hold=100
<< NOTE: Defaults applied to RAM. Use SAVE to persist to Flash.
```

**重要**：DEFAULT 只修改 RAM，不会自动保存到 Flash

3. 断电重启
4. 应该看到仍然加载之前的保存配置

### 6. 边界情况测试

#### 测试 CRC 校验

1. 保存配置
2. 使用调试工具手动修改 Flash 中的数据（破坏 CRC）
3. 重启设备
4. 应该看到 "CONFIG LOAD: CRC mismatch" 并使用默认配置

#### 测试参数范围验证

1. 手动修改 Flash 中的参数为非法值（如 touch_threshold = 0）
2. 重启设备
3. 应该看到参数被自动修正：

```
CONFIG VALIDATE: touch_threshold 0 -> 20 (out of range 5-30)
CONFIG INIT: Parameters corrected after validation
```

## 技术细节

### Flash 地址计算

RP2040 Flash 布局：
- Flash 起始地址：`XIP_BASE = 0x10000000`
- 程序代码：从 `0x10000000` 开始
- 配置存储：最后一个 sector

对于 2MB Flash (Pico 标准)：
- Flash 大小：`0x200000` (2,097,152 bytes)
- Sector 大小：`0x1000` (4,096 bytes)
- 配置偏移：`0x1FF000` (Flash 末尾 - 1 sector)
- 配置地址：`0x101FF000`

### CRC32 实现

使用 IEEE 802.3 标准多项式：
- 多项式：`0xEDB88320`（反向表示）
- 初始值：`0xFFFFFFFF`
- 最终异或：`0xFFFFFFFF`
- 与大多数 CRC32 工具兼容

### 启动流程

```
main()
  ↓
config_init()
  ↓
save_load() 尝试从 Flash 加载
  ↓
验证 magic → 验证 version → 验证 CRC
  ↓
如果全部通过：
  复制 Flash 数据到 config_data
  验证参数范围
  使用 Flash 配置
如果失败：
  使用 default_config
  ↓
设置 cfg = &config_data
  ↓
mpr121_init(), vl53l0x_init(), air_init()
  ↓
硬件初始化使用已加载的配置
```

## 常见问题

### Q: 为什么原来硬编码 256KB 是错误的？

A: RP2040 的 Flash 大小取决于具体板子：
- Raspberry Pi Pico: 2MB
- 其他 RP2040 板子：可能是 1MB、2MB、4MB、8MB、16MB

硬编码 256KB 会在大于 256KB 的 Flash 上落在程序代码区域，导致：
1. 程序被破坏（最严重）
2. Flash 写保护阻止写入
3. 配置无法正确读取

使用 SDK 的 `PICO_FLASH_SIZE_BYTES` 可以自动适配。

### Q: 为什么不把配置放在 Flash 开头？

A: 程序代码从 Flash 开头开始存放。放在末尾可以：
1. 避免与程序代码冲突
2. 程序更新时不会覆盖配置（UF2 通常从开头写入）
3. Flash 容量扩展时配置位置自动调整

### Q: DEFAULT 为什么不自动保存？

A: 用户可能想：
1. 临时测试默认值
2. 之后再调整其他参数
3. 最后一次性保存

如果 DEFAULT 自动保存，用户就失去了撤销的机会。

当前设计：
- DEFAULT：恢复默认值到 RAM
- SAVE：保存当前 RAM 配置到 Flash
- 用户可以选择 "DEFAULT + SAVE" 来实现恢复并保存

## 总结

**核心修复**：
1. ✅ Flash 地址使用 `PICO_FLASH_SIZE_BYTES` 而非硬编码
2. ✅ 增加 CRC32 校验
3. ✅ 增加版本号管理
4. ✅ 增加写入验证
5. ✅ 固件返回明确的成功/失败结果
6. ✅ Python GUI 检查返回值并显示结果
7. ✅ 详细的启动和调试日志

**测试要点**：
- 首次启动看到 "CONFIG LOAD DEFAULT"
- 保存后看到 "SAVE OK" 和 "CONFIG SAVE: SUCCESS"
- 掉电重启看到 "CONFIG LOAD FLASH"
- 参数值与保存前一致

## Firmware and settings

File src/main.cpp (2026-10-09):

/*
 * Chuni245Tof Main Program
 * NKRO Keyboard with MPR121 Slider + VL53L0X Air
 *
 * 改进：
 * 1. 优化 HID 发送机制 - 使用 dirty flag，状态变化立即发送
 * 2. 修复 CONFIG 命令 - 支持 min_hold 参数
 * 3. 添加性能统计和 AIR 调试命令
 */

#include <stdlib.h>
#include <stdint.h>
#include <stdbool.h>
#include <string.h>
#include <stdio.h>

#include "pico/stdlib.h"
#include "pico/bootrom.h"
#include "hardware/gpio.h"
#include "hardware/clocks.h"
#include "hardware/watchdog.h"
#include "hardware/timer.h"
#include "tusb.h"
#include "class/cdc/cdc_device.h"

#include "board_defs.h"
#include "config.h"
#include "save.h"
#include "mpr121.h"
#include "slider.h"
#include "vl53l0x.h"
#include "tof_reader.h"
#include "tof_events.h"
#include "air.h"
#include "button.h"
#include "log_output.h"   // printf 总开关 (默认禁用, 只发送 HID 报文)

using namespace Chuni245Tof;
extern "C" bool chuni_dcd_task(void);
extern "C" uint32_t chuni_dcd_timeout_count(void);
static bool usb_reinit_pending = false;
static uint64_t usb_reinit_at = 0;
static uint64_t bootloader_at = 0;

static void service_usb() {
#if CHUNI_FAULT_RECOVERY_ENABLE
    if (usb_reinit_pending) {
        if (time_us_64() >= usb_reinit_at) {
            tusb_init();
            usb_reinit_pending = false;
        }
        return;
    }
    if (!chuni_dcd_task()) {
        tud_deinit(0);
        usb_reinit_pending = true;
        usb_reinit_at = time_us_64() + 250000;
        return;
    }
#else
    (void)chuni_dcd_task(); // service hardware, never reinitialize USB
#endif
    tud_task_ext(0, false);
}

// Physical button pins
#define BUTTON_ENTER_PIN  18  // GP18 - Barrier mode 1 selection at startup
#define BUTTON_2_PIN      19  // GP19 - Barrier mode 0 selection at startup

// Onboard LED
#define LED_PIN 25

// Barrier mode selection buttons (startup only)
// 按照用户要求：
// - 不按按键上电 → 模式 2 (默认)
// - 按住 GP18 上电 → 模式 1
// - 按住 GP19 上电 → 模式 0 (优先级最高)

// Runtime barrier mode (determined at startup)
static uint8_t runtime_barrier_mode = 2;  // Default: mode 2

// NKRO Keyboard report
struct __attribute__((packed)) {
    uint8_t modifier;
    uint8_t keymap[15];
} hid_nkro, sent_hid_nkro;

// HID 状态管理
static volatile bool hid_dirty = false;  // 状态变化标志
static volatile uint64_t last_hid_send_time = 0;  // 上次发送时间
static volatile uint32_t hid_send_count = 0;  // HID 发送计数

// USB 活跃性统计（区分 "CPU 卡住" 与 "USB/电源层掉线" 的关键观测点）
static volatile uint64_t last_tud_task_us = 0;       // 上次 tud_task() 调用时刻
static volatile uint32_t max_tud_task_interval_us = 0;  // 两次 tud_task() 之间的最大间隔
static volatile uint32_t tud_task_count = 0;
static volatile uint32_t hid_ready_false_count = 0;  // HID endpoint busy 次数
static volatile uint64_t hid_busy_since_us = 0;      // 连续 not-ready 起点 (0 = endpoint ready)
static volatile uint32_t max_hid_not_ready_us = 0;   // 连续 not-ready 最长持续时间
static volatile uint32_t max_hid_send_gap_us = 0;    // 两次成功 HID 发送的最大间隔

//==============================================================================
// USB 健康状态 (部分关键指标可经 USBSTATUS 读取, 不依赖 printf)
//
// 用于区分四类故障 (发生 USB 无输入后逐项核对):
//   A. tud_mounted()==false        → 枚举/主机连接层问题 (unmount_count 增加)
//   B. mounted + suspended         → 主机 USB suspend (不是 HID 故障)
//   C. mounted + 非suspend + HID not-ready 持续很久 → endpoint 卡死
//      (max_hid_busy_us 增大, 超阈值触发受控重枚举 usb_recovery_count++)
//   D. mounted + HID ready 但发送失败 → 栈异常 (hid_send_fail_count 增加)
//==============================================================================
typedef struct {
    uint32_t mount_count;
    uint32_t unmount_count;
    uint32_t suspend_count;
    uint32_t resume_count;
    uint32_t hid_send_count;
    uint32_t hid_send_fail_count;
    uint32_t usb_recovery_count;    // 受控重枚举执行次数
    uint32_t max_tud_gap_us;        // 两次 tud_task() 的最大间隔
    uint32_t max_hid_busy_us;       // HID endpoint 连续 not-ready 的最长持续时间
    uint64_t last_mount_us;
    uint64_t last_unmount_us;
    uint64_t last_suspend_us;
    uint64_t last_resume_us;
    uint64_t last_hid_send_us;
} usb_health_t;

static usb_health_t usb_health;
static volatile bool usb_mounted = false;     // tud_mount_cb / tud_umount_cb 维护
static volatile bool usb_suspended = false;   // tud_suspend_cb / tud_resume_cb 维护
// IRQ only reads this byte, never a possibly torn 64-bit Core0 timestamp.
static volatile bool hid_stalled_for_led = false;

// ---- HID endpoint watchdog (仅 mounted + 非 suspended 时计时) ----
// ★ 自动恢复默认关闭 (CHUNI_USB_AUTO_RECOVERY_ENABLE=0) ★
// 原因: 恢复动作 (tud_disconnect/tud_connect) 本身就是一次 USB 断开重连,
// 主机侧表现与掉线完全相同 —— 自动恢复会把 "一次真死" 变成 "反复断连",
// 且误判条件 (如主机选择性挂起) 会造成周期性自断连。默认只统计不干预;
// 确认需要时把宏改为 1 再启用受控重枚举。
// Recovery switches are grouped in vl53l0x.h.

static const uint32_t HID_STALL_RECOVERY_MS = 5000;    // not-ready 持续阈值
static const uint32_t USB_RECOVERY_COOLDOWN_MS = 3000; // 两次受控重枚举最小间隔
static uint64_t hid_not_ready_since_us = 0;            // 本轮 not-ready 起点 (0 = ready)
static uint64_t last_usb_recovery_us = 0;
#if CHUNI_USB_AUTO_RECOVERY_ENABLE
static bool usb_disconnect_pending = false;            // disconnect 后等待延迟重连
static uint64_t usb_disconnect_at_us = 0;
#endif

// ---- 复位原因/启动计数 ----
// boot_count 放在 .uninitialized_data 段: SRAM 保留的复位可能保留此值。
// 断电/欠压后的 SRAM 不可靠, magic 不匹配时重新计数; 不能据此证明 brownout。
// USBSTATUS 的 wdt 才是 watchdog_caused_reboot() 读取的硬件复位证据。
#define BOOT_MAGIC 0x43485531u  // "CHU1"
static volatile uint32_t boot_magic __attribute__((section(".uninitialized_data")));
static volatile uint32_t boot_count __attribute__((section(".uninitialized_data")));
static bool reboot_by_watchdog = false;

// 性能统计
static volatile uint32_t main_loop_count = 0;
static volatile uint32_t main_loop_max_us = 0;
static volatile uint32_t main_loop_avg_us = 0;
static volatile uint64_t main_loop_last_time = 0;

// 监控模式
static volatile bool monitor_mode = false;
static volatile uint32_t monitor_interval_ms = 100;
static volatile uint64_t last_monitor_time = 0;
static volatile uint32_t monitor_truncated_count = 0; // CDC 背压导致被截断的 monitor 输出次数
static volatile uint32_t cdc_cmd_dropped_count = 0;   // CDC 背压导致被丢弃的命令条数

// Core0 各任务最大执行时间 (定位 "tud_task gap" 的真正来源; 低成本统计:
// 每任务一次 start/end + max 比较, 不产生任何输出)
static volatile uint32_t cdc_task_max_us = 0;
static volatile uint32_t slider_update_max_us = 0;
static volatile uint32_t air_update_max_us = 0;
static volatile uint32_t hid_task_max_us = 0;   // gen_nkro_report + report_usb_hid
static volatile uint32_t save_loop_max_us = 0;
static volatile uint32_t cmd_step_max_us = 0;    // 单条 CDC 命令执行耗时

// sent_hid_nkro 是否有效: USB 重枚举后置 false, 强制下一轮完整重发当前状态
// (用户无需重新按键 HID 就能恢复输出)
static bool sent_valid = false;

static char cdc_rx_buf[256];
static uint8_t cdc_rx_pos = 0;

// ---- CDC 命令队列 ----
// ★ cdc_task 只负责 "接收+解析+入队", 绝不在 CDC 路径执行命令。
//   执行由主循环 command_step() 完成, 每轮最多 1 条 —— 即使命令处理
//   路径出现未预期耗时, 也只会延后而不是累积阻塞主循环。
#define CDC_CMD_QUEUE_DEPTH 4
static char cdc_cmd_queue[CDC_CMD_QUEUE_DEPTH][256];
static volatile uint8_t cdc_cmd_q_head = 0;   // 生产者: cdc_task
static volatile uint8_t cdc_cmd_q_tail = 0;   // 消费者: command_step
static volatile uint32_t cdc_cmd_queue_full_count = 0;

// ---- 主循环 stage 面包屑 (硬锁现场留存) ----
// 写入 .uninitialized_data 段: 看门狗复位时保留, 断电后的值不可靠。
// 看门狗复位后从 prev_stage 即可读出卡死位置, 不再是 "黑盒重启"。
typedef enum {
    MAIN_STAGE_IDLE = 0,     // 上电未进入主循环
    MAIN_STAGE_TUD_TASK,     // TinyUSB 协议栈
    MAIN_STAGE_CDC_TASK,     // CDC 接收/解析/入队
    MAIN_STAGE_CMD_STEP,     // CDC 命令执行 (每轮最多 1 条)
    MAIN_STAGE_SLIDER,       // MPR121 轮转轮询 + 异步命令状态机
    MAIN_STAGE_AIR,          // ToF 快照消费
    MAIN_STAGE_BUTTON,       // 物理按钮
    MAIN_STAGE_HID,          // HID 报文生成/发送 + watchdog
    MAIN_STAGE_SAVE,         // 延迟 Flash 保存
    MAIN_STAGE_LOOP_END,     // 一轮完整结束 (喂狗点)
    MAIN_STAGE_SENSOR_INIT,  // 冷启动传感器初始化 (8s 看门狗保护)
} main_stage_t;

static volatile uint32_t last_main_stage __attribute__((section(".uninitialized_data")));
static volatile uint32_t last_stage_enter_us __attribute__((section(".uninitialized_data")));
static volatile uint32_t loop_completed_count __attribute__((section(".uninitialized_data")));

// 上一次生命周期 (看门狗复位前) 的现场快照, main() 开头捕获
static uint32_t crash_prev_stage = 0;
static uint32_t crash_prev_stage_us = 0;
static uint32_t crash_prev_loops = 0;

#define STAGE_ENTER(st) do { \
    last_main_stage = (uint32_t)(st); \
    last_stage_enter_us = time_us_32(); \
} while (0)

static const char* main_stage_name(uint32_t st) {
    switch (st) {
        case MAIN_STAGE_IDLE:     return "IDLE";
        case MAIN_STAGE_TUD_TASK: return "TUD_TASK";
        case MAIN_STAGE_CDC_TASK: return "CDC_TASK";
        case MAIN_STAGE_CMD_STEP: return "CMD_STEP";
        case MAIN_STAGE_SLIDER:   return "SLIDER";
        case MAIN_STAGE_AIR:      return "AIR";
        case MAIN_STAGE_BUTTON:   return "BUTTON";
        case MAIN_STAGE_HID:      return "HID";
        case MAIN_STAGE_SAVE:     return "SAVE";
        case MAIN_STAGE_LOOP_END: return "LOOP_END";
        case MAIN_STAGE_SENSOR_INIT: return "SENSOR_INIT";
        default:                  return "?";
    }
}

// HID Key codes (HID Usage Table)
#define HID_KEY_A       0x04
#define HID_KEY_B       0x05
#define HID_KEY_C       0x06
#define HID_KEY_D       0x07
#define HID_KEY_E       0x08
#define HID_KEY_F       0x09
#define HID_KEY_G       0x0A
#define HID_KEY_H       0x0B
#define HID_KEY_I       0x0C
#define HID_KEY_J       0x0D
#define HID_KEY_K       0x0E
#define HID_KEY_L       0x0F
#define HID_KEY_M       0x10
#define HID_KEY_N       0x11
#define HID_KEY_O       0x12
#define HID_KEY_P       0x13
#define HID_KEY_Q       0x14
#define HID_KEY_R       0x15
#define HID_KEY_S       0x16
#define HID_KEY_T       0x17
#define HID_KEY_U       0x18
#define HID_KEY_V       0x19
#define HID_KEY_W       0x1A
#define HID_KEY_X       0x1B
#define HID_KEY_Y       0x1C
#define HID_KEY_Z       0x1D
#define HID_KEY_1       0x1E
#define HID_KEY_2       0x1F
#define HID_KEY_3       0x20
#define HID_KEY_4       0x21
#define HID_KEY_5       0x22
#define HID_KEY_6       0x23
#define HID_KEY_7       0x24
#define HID_KEY_8       0x25
#define HID_KEY_9       0x26
#define HID_KEY_0       0x27
#define HID_KEY_ENTER   0x28
#define HID_KEY_LBRACKET  0x2F  // [
#define HID_KEY_RBRACKET  0x30  // ]
#define HID_KEY_BACKSLASH 0x31  // \
#define HID_KEY_SEMICOLON 0x33  // ;
#define HID_KEY_APOSTROPHE 0x34 // '
#define HID_KEY_COMMA   0x36
#define HID_KEY_PERIOD  0x37
#define HID_KEY_SLASH   0x38

// Slider keyboard mapping (Key 1-32)
// Hardware partition: 8/12/12 (matching MPR121 pin counts: 0x5C=8, 0x5B=12, 0x5A=12)
// Row 1 (cell 1-8):   Q W E R T Y U I
// Row 2 (cell 9-20):  O P [ ] a s d f g h j k
// Row 3 (cell 21-32): l ; ' \ z x c v b n m ,
static const uint8_t slider_keymap[32] = {
    HID_KEY_Q, HID_KEY_W, HID_KEY_E, HID_KEY_R,
    HID_KEY_T, HID_KEY_Y, HID_KEY_U, HID_KEY_I,

    HID_KEY_O, HID_KEY_P, HID_KEY_LBRACKET, HID_KEY_RBRACKET,
    HID_KEY_A, HID_KEY_S, HID_KEY_D, HID_KEY_F,
    HID_KEY_G, HID_KEY_H, HID_KEY_J, HID_KEY_K,

    HID_KEY_L, HID_KEY_SEMICOLON, HID_KEY_APOSTROPHE, HID_KEY_BACKSLASH,
    HID_KEY_Z, HID_KEY_X, HID_KEY_C, HID_KEY_V,
    HID_KEY_B, HID_KEY_N, HID_KEY_M, HID_KEY_COMMA,
};

// Air keyboard mapping (IR1-6: 4 5 6 7 8 9)
static const uint8_t air_keymap[6] = {
    HID_KEY_4,  // IR1
    HID_KEY_5,  // IR2
    HID_KEY_6,  // IR3
    HID_KEY_7,  // IR4
    HID_KEY_8,  // IR5
    HID_KEY_9,  // IR6
};

// Set key in NKRO bitmap
static void nkro_set_key(uint8_t keycode, bool pressed) {
    if (keycode >= 120) return;
    uint8_t byte = keycode / 8;
    uint8_t bit = keycode % 8;
    if (pressed) {
        hid_nkro.keymap[byte] |= (1 << bit);
    } else {
        hid_nkro.keymap[byte] &= ~(1 << bit);
    }
}

// Generate NKRO report
static void gen_nkro_report() {
    // 保存旧状态
    uint8_t old_keymap[15];
    uint8_t old_modifier = hid_nkro.modifier;
    memcpy(old_keymap, hid_nkro.keymap, sizeof(hid_nkro.keymap));

    // 清空新状态
    memset(&hid_nkro, 0, sizeof(hid_nkro));

    // Physical buttons (GP18=ENTER, GP19=2)
    if (!gpio_get(BUTTON_ENTER_PIN)) {
        nkro_set_key(HID_KEY_ENTER, true);
    }
    if (!gpio_get(BUTTON_2_PIN)) {
        nkro_set_key(HID_KEY_2, true);
    }

    // Slider keys (32 keys)
    uint32_t slider_state = slider_get_state();
    for (int i = 0; i < 32; i++) {
        if (slider_state & (1 << i)) {
            nkro_set_key(slider_keymap[i], true);
        }
    }

    // Air keys (6 height levels)
    uint8_t air_state = air_get_bitmap();
    for (int i = 0; i < 6; i++) {
        if (air_state & (1 << i)) {
            nkro_set_key(air_keymap[i], true);
        }
    }

    // 检查状态是否变化
    if (hid_nkro.modifier != old_modifier ||
        memcmp(hid_nkro.keymap, old_keymap, sizeof(hid_nkro.keymap)) != 0) {
        hid_dirty = true;  // 状态变化，需要发送
    }
}
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
int main(void) {
    // Use Pico's conservative 125 MHz clock during stability qualification.
    // I2C baud rates and sensor timing budgets are configured independently.
    set_sys_clock_khz(125000, true);
    // 注意: 不调用 stdio_init_all() —— 本工程 stdio 输出后端全部关闭
    // (CMakeLists: pico_enable_stdio_usb/uart = 0), USB device 栈的唯一
    // 所有者是 tusb_init() 的 TinyUSB 生命周期。

    // ===== 复位原因 / 启动计数 (SRAM 保留时有效, magic 校验) =====
    bool retained_state_valid = boot_magic == BOOT_MAGIC;
    if (retained_state_valid) {
        boot_count++;
    } else {
        boot_magic = BOOT_MAGIC;
        boot_count = 1;
    }
    reboot_by_watchdog = watchdog_caused_reboot();

    // 捕获上一次生命周期的硬锁现场 (看门狗复位时 last_main_stage 即
    // 卡死位置)。断电冷启动时 .uninitialized_data 为随机值, 仅在
    // wdt_reboot=1 时解读。
    if (retained_state_valid && reboot_by_watchdog) {
        crash_prev_stage = last_main_stage;
        crash_prev_stage_us = last_stage_enter_us;
        crash_prev_loops = loop_completed_count;
    }
    loop_completed_count = 0;
    // 为本次生命周期初始化面包屑 (冷启动时 .uninitialized_data 为随机值,
    // 若不初始化, LED stage-stall 判定会在进入主循环前误报常亮)
    last_main_stage = (uint32_t)MAIN_STAGE_IDLE;
    last_stage_enter_us = time_us_32();

    // Initialize LED
    gpio_init(LED_PIN);
    gpio_set_dir(LED_PIN, GPIO_OUT);
    gpio_put(LED_PIN, 1);

    // ===== BARRIER MODE SELECTION (before any other initialization) =====
    // 初始化 GP18 和 GP19 用于启动时检测
    gpio_init(BUTTON_ENTER_PIN);  // GP18
    gpio_set_dir(BUTTON_ENTER_PIN, GPIO_IN);
    gpio_pull_up(BUTTON_ENTER_PIN);

    gpio_init(BUTTON_2_PIN);      // GP19
    gpio_set_dir(BUTTON_2_PIN, GPIO_IN);
    gpio_pull_up(BUTTON_2_PIN);

    // 等待 pull-up 稳定 (RP2040 内部 pull-up 约 50kΩ，需要时间充电线路电容)
    busy_wait_us(100);

    // 读取按键状态（active low）
    bool gp18_pressed = !gpio_get(BUTTON_ENTER_PIN);  // 按住 GP18 → 模式 1
    bool gp19_pressed = !gpio_get(BUTTON_2_PIN);      // 按住 GP19 → 模式 0

    // 确定 barrier mode（GP19 优先级高于 GP18）
    if (gp19_pressed) {
        runtime_barrier_mode = 0;  // Mode 0: 直接接触
    } else if (gp18_pressed) {
        runtime_barrier_mode = 1;  // Mode 1: 物体间隔
    } else {
        runtime_barrier_mode = 2;  // Mode 2: 物体间隔+手套 (默认)
    }

    printf("\n========================================\n");
    printf("   Chuni245Tof Controller\r\n");
    printf("   Optimized for High-Speed Air Detection\r\n");
    printf("========================================\n");

    // Print barrier mode selection
    printf("\n[STARTUP] Barrier Mode Selection:\n");
    printf("  GP18: %s, GP19: %s\n",
           gp18_pressed ? "PRESSED" : "released",
           gp19_pressed ? "PRESSED" : "released");
    printf("  Selected Mode: %d", runtime_barrier_mode);
    if (runtime_barrier_mode == 0) {
        printf(" (Direct contact - Touch=20 Release=18 CONFIG1=0x35 CONFIG2=0x02)\n");
    } else if (runtime_barrier_mode == 1) {
        printf(" (Object barrier - Touch=3 Release=2 CONFIG1=0x35 CONFIG2=0x22)\n");
    } else {
        printf(" (Object barrier + glove - Touch=3 Release=2 CONFIG1=0x25 CONFIG2=0x22)\n");
    }
    printf("\n");

    static mutex_t lock;
    mutex_init(&lock);

    // ===== Set barrier mode before config_init =====
    // This affects default touch/release thresholds and MPR121 CONFIG registers
    config_set_barrier_mode(runtime_barrier_mode);

    // ===== Initialize configuration =====
    // This will load from Flash or use defaults
    // The defaults will use runtime_barrier_mode for touch/release thresholds
    config_init();
    save_init(0xCA34CAFE, &lock);

    printf("Initializing sensors...\r\n");
    // Cover initialization too: otherwise a fault after watchdog reset can
    // leave the LED lit forever before the runtime watchdog is enabled.
#if CHUNI_FAULT_RECOVERY_ENABLE
    watchdog_enable(8000, true);
#endif
    STAGE_ENTER(MAIN_STAGE_SENSOR_INIT);
    button_init();
    slider_init();  // This will call mpr121_init() with barrier mode settings
#if DEBUG_MPR121
    mpr121_debug_init();  // one-shot config dump after MPR121 init
#endif
    // I2C1 由 Core1 独占: VL53L0X 初始化与轮询全部在 Core1 上执行
    // (air_init → tof_reader_init → Core1 启动 vl53l0x_init)
    air_init();      // 启动 Core 1 读取任务（含 I2C1 + VL53L0X 初始化）
    // Both sensor initializations are scheduled, not waited on. Core0 can now
    // service enumeration while their reset/settling deadlines elapse.
    tusb_init();
    printf("Ready.\r\n\n");

    printf("Commands: STATUS, AIRDEBUG, PERF, DIST, AIR, HELP\r\n\n");

    main_loop_last_time = time_us_64();

    /*
     * ==============================================================================
     * Core 0 主循环架构
     * ==============================================================================
     *
     * 【实时任务优先级】
     * ⭐⭐⭐⭐⭐  TinyUSB tud_task()    - USB协议栈，必须持续运行
     * ⭐⭐⭐⭐⭐  USB HID              - 必须持续发送，不能长时间阻塞
     * ⭐⭐⭐⭐⭐  MPR121 Slider        - 更高优先级实时输入，但故障不能拖死Core 0
     * ⭐⭐⭐⭐    AIR                  - 高实时性输入
     * ⭐        CDC/Monitor          - 低优先级调试接口
     * ⭐        Flash Save           - 仅在SAVE命令时执行
     *
     * 【关键原则】
     * 1. MPR121正常时：必须优先保证其扫描频率和实时性
     * 2. MPR121异常时：快速失败，不阻塞AIR和USB HID
     * 3. AIR必须完全独立于MPR121，即使MPR121全部失败，AIR仍正常运行
     * 4. 任何单个实时任务的最坏执行时间必须有界（<5ms）
     * 5. USB HID不能被任何输入设备长时间阻塞
     *
     * 【架构改进】
     * - MPR121 I2C使用极短timeout（500us），失败立即返回
     * - CDC任务限制每次处理的字节数，避免大量数据阻塞
     * - Monitor输出按间隔调用，不会频繁阻塞
     * - Flash操作只在SAVE命令时执行，不在主循环中
     *
     * ==============================================================================
     */
    // ===== Core0 硬锁看门狗 =====
    // 任何主循环 stage 永久卡死 (未知的 while/mutex/sleep 路径, 状态机
    // 卡住等) 最多 2s 后强制复位; 复位后 crash_prev_stage 给出卡死位置。
    // 冷启动的 8s 看门狗在此收紧为 2s; 主循环每轮末尾喂狗一次。
    // pause_on_debug=1: gdb 断点暂停时不误触发。
#if CHUNI_FAULT_RECOVERY_ENABLE
    watchdog_enable(2000, 1);
#endif

    // ===== LED 生命信号: 硬件定时器 IRQ (与主循环完全解耦) =====
    // 旧实现 LED 在主循环内更新 —— 主循环一死 LED 一起冻结, 失去
    // 观测价值 (用户实测 "USB 无输入时 LED 也停止变化" 即此缺陷)。
    // 新实现: 10ms 硬件定时器中断更新 LED, 主循环卡死时由 stage-stall
    // 判定点亮 (常亮 = 卡死证据)。IRQ 处理器仅做比较 + gpio_put, 微秒级。
    add_repeating_timer_us(LED_TICK_US, led_timer_cb, NULL, &led_timer);

    while (1) {
        if (bootloader_at && time_us_64() >= bootloader_at) reset_usb_boot(0, 0);
        // 性能统计：记录循环开始时间
        uint64_t loop_start = time_us_64();

        // ===== USB 服务间隔统计 =====
        // 真正决定 USB 稳定性的是两次 tud_task() 之间的最大空洞:
        // 主循环任何阻塞路径都会直接体现在该统计上
        uint32_t tud_interval_us = (uint32_t)(loop_start - last_tud_task_us);
        if (last_tud_task_us && tud_interval_us > max_tud_task_interval_us) {
            max_tud_task_interval_us = tud_interval_us;
            usb_health.max_tud_gap_us = tud_interval_us;
        }
        last_tud_task_us = loop_start;

        // ===== TinyUSB Task（最高优先级，必须持续运行）=====
        STAGE_ENTER(MAIN_STAGE_TUD_TASK);
        service_usb();
        tud_task_count++;

        // ===== Slider更新（更高优先级实时输入，非阻塞）=====
        STAGE_ENTER(MAIN_STAGE_SLIDER);
        // 推进 MPR121 的一个 I2C 步骤；FIFO/ACK/STOP 等待跨主循环完成。
        { uint64_t t0 = time_us_64();
        slider_update();
        uint32_t d = (uint32_t)(time_us_64() - t0); if (d > slider_update_max_us) slider_update_max_us = d; }
#if DEBUG_MPR121
        mpr121_debug_tick();
#endif

        // ===== AIR更新（高实时性输入，完全独立）=====
        STAGE_ENTER(MAIN_STAGE_AIR);
        // 仅依赖Core 1 TOF snapshot，不依赖MPR121
        { uint64_t t0 = time_us_64();
        air_update();
        uint32_t d = (uint32_t)(time_us_64() - t0); if (d > air_update_max_us) air_update_max_us = d; }

        // ===== 物理按钮更新（非阻塞GPIO读取）=====
        STAGE_ENTER(MAIN_STAGE_BUTTON);
        button_update();

        // ===== HID Report生成和发送（必须持续运行）=====
        STAGE_ENTER(MAIN_STAGE_HID);
        { uint64_t t0 = time_us_64();
        gen_nkro_report();
        report_usb_hid();
#if CHUNI_FAULT_RECOVERY_ENABLE
        usb_hid_watchdog();
#endif
        uint32_t d = (uint32_t)(time_us_64() - t0); if (d > hid_task_max_us) hid_task_max_us = d; }

        // ===== CDC任务（低优先级，只接收/解析/入队）=====
        { uint64_t t0 = time_us_64();
        STAGE_ENTER(MAIN_STAGE_CDC_TASK);
        cdc_task();
        uint32_t d = (uint32_t)(time_us_64() - t0); if (d > cdc_task_max_us) cdc_task_max_us = d; }

        // ===== CDC 命令执行（每轮最多 1 条, 分步推进）=====
        { uint64_t t0 = time_us_64();
        STAGE_ENTER(MAIN_STAGE_CMD_STEP);
        command_step();
        uint32_t d = (uint32_t)(time_us_64() - t0); if (d > cmd_step_max_us) cmd_step_max_us = d; }
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

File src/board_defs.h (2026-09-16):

/*
 * Hardware Board Definitions
 * Pin assignments for Chuni245Tof Controller
 */

#ifndef BOARD_DEFS_H
#define BOARD_DEFS_H

// I2C Ports
#define I2C0_PORT i2c0
#define I2C0_SDA 16
#define I2C0_SCL 17

#define I2C1_PORT i2c1
#define I2C1_SDA 6
#define I2C1_SCL 7

// MPR121 Touch Controller Addresses
#define MPR121_ADDR_1 0x5A
#define MPR121_ADDR_2 0x5B
#define MPR121_ADDR_3 0x5C

// VL53L0X TOF Sensor XSHUT pins
#define TOF1_XSHUT 5
#define TOF2_XSHUT 4
#define TOF3_XSHUT 3
#define TOF4_XSHUT 2
#define TOF5_XSHUT 1

// Button pins
#define BUTTON_CARD 28
#define BUTTON_TEST 27

// LED pin
#define LED_PIN 25

//------------------------------------------------------------------------------
// 编译期引脚隔离校验 (Recovery Access Boundary 的硬件前提)
//
// I2C0 (MPR121, Core0) 与 I2C1 (VL53L0X, Core1) 是两个完全独立的总线域。
// 上述所有引脚两两不得重叠 —— 若重叠, ToF 恢复期间对 XSHUT/I2C1 引脚的
// GPIO 操作将直接破坏另一条总线的电气状态。此不变量由编译器强制保证。
//------------------------------------------------------------------------------
#ifdef __cplusplus
#include <stddef.h>
constexpr inline unsigned chuni_board_pins[] = {
    I2C0_SDA, I2C0_SCL,                                    // I2C0 (MPR121)
    I2C1_SDA, I2C1_SCL,                                    // I2C1 (VL53L0X)
    TOF1_XSHUT, TOF2_XSHUT, TOF3_XSHUT, TOF4_XSHUT, TOF5_XSHUT, // ToF XSHUT
    BUTTON_CARD, BUTTON_TEST, LED_PIN,
};
constexpr inline bool chuni_board_pins_distinct()
{
    for (size_t i = 0; i < sizeof(chuni_board_pins) / sizeof(chuni_board_pins[0]); ++i)
        for (size_t j = i + 1; j < sizeof(chuni_board_pins) / sizeof(chuni_board_pins[0]); ++j)
            if (chuni_board_pins[i] == chuni_board_pins[j]) return false;
    return true;
}
static_assert(chuni_board_pins_distinct(),
              "I2C0/I2C1/XSHUT/GPIO pin overlap: I2C bus isolation broken");
#endif

#endif /* BOARD_DEFS_H */

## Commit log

2026-08-18 Refactor AIR detection: fix timestamp logic, optimize polling, add hysteresis mechanism
    [main.cpp, vl53l0x.cpp]
2026-08-18 debug: add mpr121 debug monitor print
2026-08-18 docs: add BOM
    [BOM_CN.csv, BOM_EN.csv]
2026-08-19 enhance vl53l0x i2c access frequence
2026-08-20 modify top panel window position
    [main_toppanel_1mm.dxf]
2026-08-22 complete barrier mode parameter & fix occational air input lag
    [main.cpp, mpr121.cpp]
2026-08-26 fix FLASH, mpr121 parameter, tof distance problem
    [config_cdc.py, main.cpp, mpr121.cpp]
2026-09-03 switch calculating TOF max value to just threshold comparing
2026-09-16 fix cross core lock
    [board_defs.h, main.cpp, mpr121.cpp]
